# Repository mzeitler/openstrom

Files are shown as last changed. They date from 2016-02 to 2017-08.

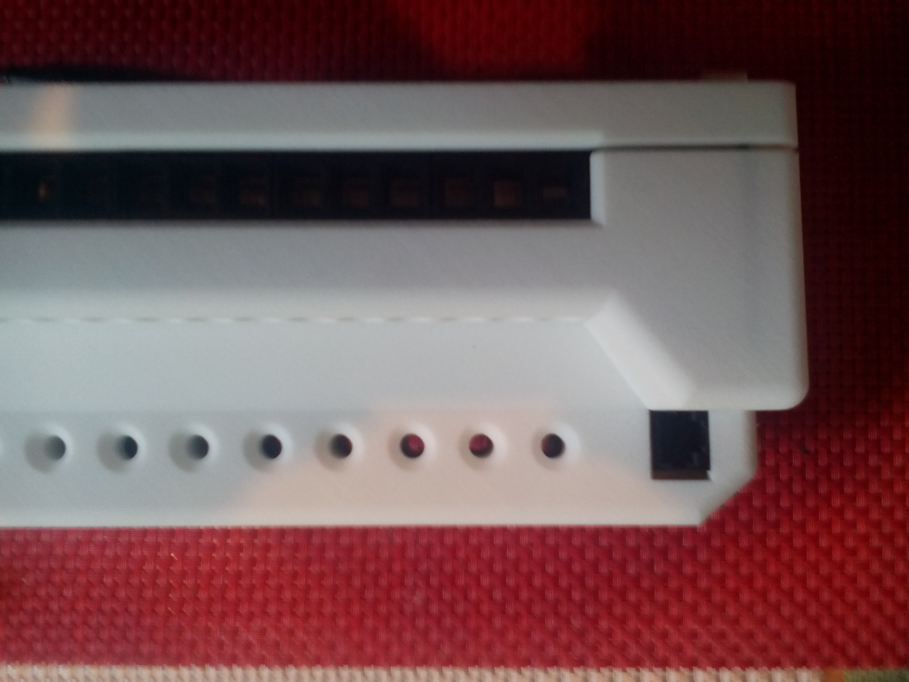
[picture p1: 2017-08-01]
housing/v0.4 - prototype 2/assembled/2017-06-19 11.30.17.jpg

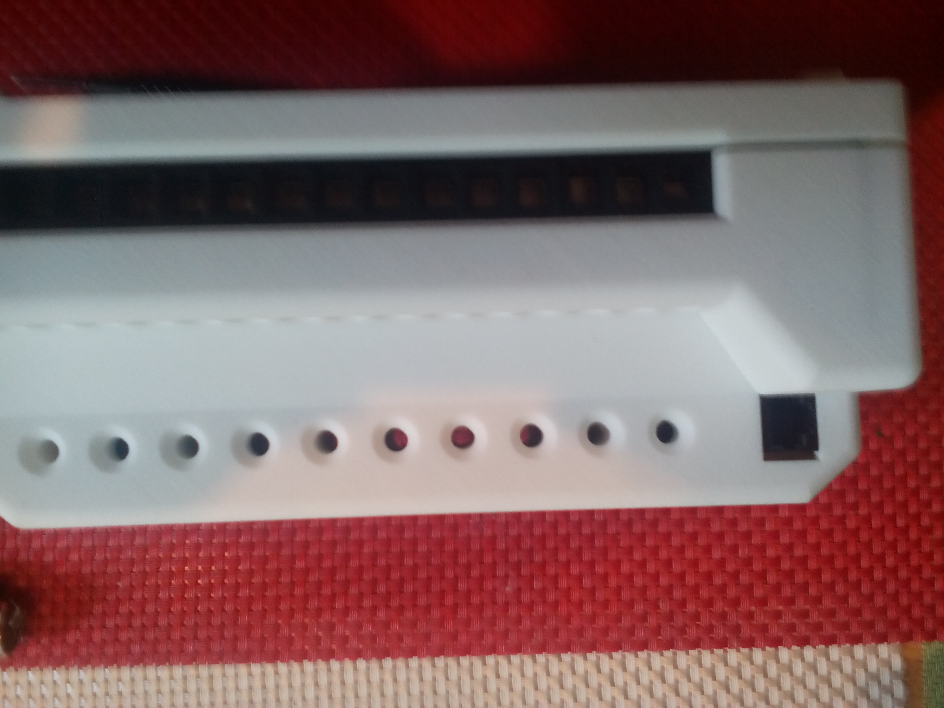
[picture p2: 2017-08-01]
housing/v0.4 - prototype 2/assembled/2017-06-19 11.30.14.jpg

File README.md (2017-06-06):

OpenStrom is an Open Hardware device that can measure and control power circuits over the internet.

It is developed by the [OpenStrom KG](http://www.openstrom.com) and generously supported by [netidee](http://www.netidee.at).

---
Copyright 2017 OpenStrom KG

Permission is hereby granted, free of charge, to any person obtaining a copy of this software and associated documentation files (the "Software"), to deal in the Software without restriction, including without limitation the rights to use, copy, modify, merge, publish, distribute, sublicense, and/or sell copies of the Software, and to permit persons to whom the Software is furnished to do so, subject to the following conditions:

The above copyright notice and this permission notice shall be included in all copies or substantial portions of the Software.

THE SOFTWARE IS PROVIDED "AS IS", WITHOUT WARRANTY OF ANY KIND, EXPRESS OR IMPLIED, INCLUDING BUT NOT LIMITED TO THE WARRANTIES OF MERCHANTABILITY, FITNESS FOR A PARTICULAR PURPOSE AND NONINFRINGEMENT. IN NO EVENT SHALL THE AUTHORS OR COPYRIGHT HOLDERS BE LIABLE FOR ANY CLAIM, DAMAGES OR OTHER LIABILITY, WHETHER IN AN ACTION OF CONTRACT, TORT OR OTHERWISE, ARISING FROM, OUT OF OR IN CONNECTION WITH THE SOFTWARE OR THE USE OR OTHER DEALINGS IN THE SOFTWARE.
---

if you are interested in helping with development or if you think you have some interesting use cases that we should consider, please get in touch with [Matthias](mailto:m.zeitler@openstrom.com "Matthias Zeitler").

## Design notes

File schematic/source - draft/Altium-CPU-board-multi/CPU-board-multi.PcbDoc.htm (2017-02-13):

Reporting Options

# File in Previous Format

Date | : | 03.01.2017
Time | : | 12:11:02
Filename | : | C:\Users\Matthias E. Zeitler\Dropbox\OpenStrom\Spec Documents\Production files for SM rev.2\CPU-Board files\AltiumFiles\CPU-board-multi.PcbDoc

Version | Warning

This file was generated by an earlier version of the software

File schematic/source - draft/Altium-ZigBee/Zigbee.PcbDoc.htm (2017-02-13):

Reporting Options

# File in Previous Format

Date | : | 03.01.2017
Time | : | 12:12:11
Filename | : | C:\Users\Matthias E. Zeitler\Dropbox\OpenStrom\Spec Documents\Production files for SM rev.2\Zigbee files\Zigbee.PcbDoc

Version | Warning

This file was generated by an earlier version of the software

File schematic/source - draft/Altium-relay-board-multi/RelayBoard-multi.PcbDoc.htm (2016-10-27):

Altium Reporting Options

# File in Newer Format

Date | : | 9/20/2016
Time | : | 3:22:10 PM
Filename | : | C:\APP\Dropbox\OpenStrom\Spec Documents\Schematics\SmartMeter-AltiumProject\Altium-relay-board-multi\RelayBoard-multi.PcbDoc

Version | Warning
Release 10 | CAUTION - New Custom Grids and Guides were introduced. Be aware that your design might contain Custom Grids and Guides that cannot be read in previous versions.
Release 10 | CAUTION - New Structured Clusters were introduced. Be aware that your design might contain Structured Clusters that cannot be read in previous versions.
Release 10 | CAUTION - New PCB 3D Movie Manager was introduced. Be aware that your design might contain 3D PCB movie that cannot be read in previous versions.
Release 10 update 1 | CAUTION - New Clearance Rule subscopes targeting differential pairs were introduced. Be aware that your design might contain Clearance Rules using those subscopes that cannot be read in previous versions.
Release 10 update 15 | CAUTION - Support of Solder Mask and Paste Mask expansions for Tracks, Arcs, Fills and Regions was introduced. Be aware that your design might contain Solder Mask and Paste Mask expansions for these types of primitives that cannot be read in the version of Altium Designer you are currently using.
Altium Designer update 19 | CAUTION - Air Gap Width attribute was introduced to Polygon Connect Style Rule. Be aware that your design might contain Polygon Connect Style Rules with new Air Gap Width attribute cannot be read in the version of Altium Designer you are currently using.
Release 13 | CAUTION - Silk To Solder Mask Clearance Rules are converted to Silkscreen Over Component Pads Rules.

This file was generated by a later version of the software

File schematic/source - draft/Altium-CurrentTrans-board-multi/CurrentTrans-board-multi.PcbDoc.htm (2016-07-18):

Reporting Options

# File in Previous Format

Date | : | 18.07.2016
Time | : | 20:55:33
Filename | : | C:\Users\Matthias E. Zeitler\Dropbox\OpenStrom\Spec Documents\Schematics\SmartMeter-AltiumProject\Altium-CurrentTrans-board-multi\CurrentTrans-board-multi.PcbDoc

Version | Warning

This file was generated by an earlier version of the software

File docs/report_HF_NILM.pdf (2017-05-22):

# High-frequency NILM and Possible Applications

## Innovationsscheck-Studie

## FHS, Günther Eibl

26.04.2017

# Contents

Introduction | 2
1 NILM Survey Papers of Zeifman and Zoha | 3
2 Google (Scholar) searches | 5
2.2.2 | Fault Detection of Airflow Handlers and Air Condi-
2.2.3 | Condition Monitoring of Wind Energy Converters . . | 9
3 What Other Companies Promise | 11
4 Books | 13

1

# Introduction

The goal of this work is the identification of possible applications of high frequency NILM (NonIntrusive Load Monitoring) with more emphasis on the application and less emphasis on the method. If possible the search results were screened for the frequency of the measurements in order to determine if the high frequency is really needed.
The report is structured by the main phases of the literature research. The search was done in four main phases with most time consumed in the first two phases.
The first, logical step builds on two already known NILM-surveys. Both of these two surveys were searched in depth for (i) other applications apart from NILM and (ii) applications based on NILM. Summarizing the results of this part of the research, the two survey papers are a good starting point for methodological research, their benefit for screening of possible applications of high-frequency measurements is however limited.
As a result, in the second phase further searching with Google (Scholar) was done which seemed to be more promising at this point of time. Despite various efforts papers found by Google searches only additionally yielded fault detection applications.
In order to find other kinds of applications, in the third phase the idea was to search on other companies web pages for applications. The special case of PCube was considered in more detail. While there numerous applications are listed, no details of the methods are given. Based on the statements there, it seems that the combined analysis of multiple sensors is necessary for many kinds of applications.
Finally, in the last phase, in order to have reliable and well-prepared information, various searches for books were performed. Books with promising names are listed in the last chapter.

2

# Chapter 1

# NILM Survey Papers of Zeifman and Zoha

The first starting point is the survey papers about NILM methods by Zeifman [1] and Zoha [2] and the contained publications. Both papers treat NILM methods for the disaggregation of the consumption curve into the consumption curves of different appliances. Both papers and practically all cited papers are very much focused on this particular application.

## 1.1 Cited Papers

The two papers only cite very few papers that do not only focus on NILM but could, according the their title, contain other applications. These papers are listed below:

- Publication [16] in [2] treats demand side management:
Cox, Robert, et al. "Transient event detection for nonintrusive load monitoring and demand side management using voltage distortion." Applied Power Electronics Conference and Exposition, 2006. APEC’06. Twenty-First Annual IEEE. IEEE, 2006.
- Publication [75] in [2] treats the influence of user behavior
Wood, G., and M. Newborough. "Influencing user behaviour with energy information display systems for intelligent homes." International journal of energy research 31.1 (2007): 56-78.
- Publication [77] in [2] considers NILM-results as input for a controlling unit
Erickson, Varick L., et al. "Energy efficient building environment

3

1.2. Description of Features | 4

control strategies using real-time occupancy measurements." Proceedings of the First ACM Workshop on Embedded Sensing Systems for Energy-Efficiency in Buildings. ACM, 2009.
- Publication [24] in [1] is different from the previous papers in that it mentions an application that is not directly related to NILM. It is a first hint that large frequencies are important for monitoring of motors Lee, Kwangduk D., et al. "Estimation of variable-speed-drive power consumption from harmonic content." IEEE Transactions on Energy Conversion 20.3 (2005): 566-574..
- Publication [41] in [1] then directly mentions the possibility to do fault-diagnosis of engines. However, it focuses on how information from different sensors should be fused.
Basir, Otman, and Xiaohong Yuan. "Engine fault diagnosis based on multi-sensor information fusion using Dempster–Shafer evidence theory." Information Fusion 8.4 (2007): 379-386.

## 1.2 Description of Features

On the methodological side, the different features that are used for analysis of high frequency signals could be of interest. These are listed below

- Harmonics or more generally the spectral envelope
- Correlation between power and different harmonics
- In contrast to the FFT, wavelets leads to information not only of the frequency but also of the time
- Geometric properties like the I-V curve
- Time-series I(t)
V(t)

, I · V(t)
- Eigenvalues of oscillation
- Transient curve when turning on or off
- Phase angle and power factor Preal
Papparent
Additionally, there are other features like occurrence frequencies of events, data from other sensors (e.g. noise). However, these features are not assumed to be interesting for this report.

High-frequency NILM and Possible Applications

# Chapter 2

# Google (Scholar) searches

Various search variants were conducted using Google and Google Scholar in order to find practical applications of high frequency measurements. Nearly all results are considering applications that are essentially based on NILM methods. The small remaining part of the scientific literature treats fault detection especially of motors. This part of the report is structured by application type. The papers found were screened especially for information about the frequency of the measurements.

## 2.1 NILM-related applications

### 2.1.1 Energy disaggregation

- The first paper of Batra is a practical NILM-toolkit for energy disaggregation. Of practical interest could be in Section 3 about data set diagnostics, statistics, preprocessing and accuracy metrics.
Batra, Nipun, et al. "NILMTK: an open source toolkit for non-intrusive load monitoring." Proceedings of the 5th international conference on Future energy systems. ACM, 2014.
- The second paper of Batra explores the differences between energy disaggregation for residential homes and commercial buildings. Batra, Nipun, et al. "A comparison of non-intrusive load monitoring methods for commercial and residential buildings." arXiv preprint arXiv:1408.6595 (2014).

5

2.1. NILM-related applications | 6

### 2.1.2 Appliance Identification

The two papers of Chang [3, 4]a treat appliance identification with transient signals. Signal durations in the graphics are in the order of several times 0.1s. The method works with wavelets and neural nets.

### 2.1.3 Occupancy Detection

Erickson [5] treats occupancy detection which is used in order to reduce the amount of air conditioning in large buildings.

### 2.1.4 NILM Applications

The paper of Armel focuses on possible applications of appliance-specific information and could be a good starting point for further research. Armel, K. Carrie, et al. "Is disaggregation the holy grail of energy efficiency? The case of electricity." Energy Policy 52 (2013): 213-234.

Given potential applications are

- Benefits to the consumer through direct feedback
– Auto-commissioning (not clearly explained)
– Fault detection
– Enabling of enhanced behavioral techniques through feedback – Analysis of when and what type of new appliance to purchase based on current use
- R&D
– Appliance Innovation: (a) redesign appliances for energy efficiency, (b) improved standards, and (c) back up appliance energy efficiency marketing
– Buildings: mproved building simulation models? Commissioning.
- Energy efficiency marketing
- Improved objectivity, sensitivity, and causal inference in program evaluation?
- Performance based metrics, ratings, and incentives of buildings
- Improved load forecasting

High-frequency NILM and Possible Applications

2.2. Fault Detection | 7

The paper also lists requirements for disaggregation algorithms and dares to estimate the number of detectable appliances depending on the frequency

- Hourly data: 3 end-use categories (i.e., loads that correlate with outdoor temperature, loads that are continuous, and loads that are timedependent such as pool pumps and outdoor lighting)
- 1min to 1s: 8 appliance types
- Multiple kHz range: identification of 20-40 appliance types
- MHz range: identification of potentially close to 100 distinct appliances

Finally, it explores the gap between existing solutions and what is needed, e.g. the accuracy of the AD-converter which influences the accuracy of the measurements.

## 2.2 Fault Detection

First, naive searches with Google with different searching terms showed surprisingly few papers that do NOT focus on the energy disaggregation application.
As a consequence, the search was performed with a possible application in mind, like fault detection. Good queries are e.g.
- fault detection induction motor

### 2.2.1 Fault detection of Induction Motors

The paper by Benbouzid [6] is a good starting point for fault detection of induction motors. Three types of faults are discussed

- Bearings damage
- Air gap eccentricity
- Broken rotor bar

According to this paper and that of Konar [7], bearings damage accounts for about 50% of failures. All these failures result in additional frequencies that occur in the motor current. Formulas for the frequencies are given. The methods that are used are also briefly discussed

High-frequency NILM and Possible Applications

2.2. Fault Detection | 8
- Classical FFT of single-phase motor current also includes a description how the analyis system looks like.
- Instant power FFT
- The bispectrum looks like an autocorrelation function with 2 varying time lags.
- High Resolution spectral analysis with determination of the eigenvalues of the autocorrelation matrix
- Wavelet analysis has the advantage over FFT that transitory characteristics can be described (e.g. drifts, abrupt changes, frequency drifts)
- Motor Current Signature algorithm

Konar [7] use a wavelet+ANN/SVM (Artificial Neural Nets / Support Vector Machines) approach. The sampling rate of the signal is given as 7680 Hz. The paper also shows a machinery fault simulator which could be interesting.
A paper where I only read the abstract is form Sualhi. The highlight of this paper seems to be its unsupervised classification technique (artificial ant clustering).
Soualhi, Abdenour, Guy Clerc, and Hubert Razik. "Detection and diagnosis of faults in induction motor using an improved artificial ant clustering technique." IEEE Transactions on Industrial Electronics 60.9 (2013): 4053-4062.

### 2.2.2 Fault Detection of Airflow Handlers and Air Condi-

tioners

This paper of Orji [8] is the first paper I found about fault detection. Although the method is based on fault detection of induction motors, it is applied to airflow handlers and therefore in its own subsection. It describes speed detection for an induction motor. The spectral envelope is used to determine when the device is turned on. The speed is calculated with the so-called principal slot harmonic frequency (Eq. (1) in the paper). This approach for estimating the speed of the motor seems to be quite common. The paper itself focuses on the determination of a frequency search window in which the maximum is taken. This approach has limited spectral accuracy for short sampling durations. An optimization method is proposed that improves the accuracy.

High-frequency NILM and Possible Applications

2.3. Methodological Papers | 9

The method is applied for the estimation of the blockage condition of an airflow handling unit due to clogging. The speed of the fan blade is a needed input for the estimation of the histogram of the volumetric airflow of the fan. The histogram needs to be created by many starts of the fan. This paper cites the survey of Benbouzid above.

There is also a PhD thesis of Christopher Reed Laughman from 2008 called "Fault detection methods for vapor-compression air conditioners using electrical measurements". While only the introduction is available, the references are also contained and could serve as a basis for further research.

In the PhD thesis of Cox [9], electromechanical actuators are triggered e.g. compressed air and vacuum systems are triggered by e.g. pressure or temperature. The time between pump runs in the graphics is in the order of minutes. So sampling rates of kHz do not seem to be needed for that. But maybe other systems have higher time intervals.

### 2.2.3 Condition Monitoring of Wind Energy Converters

The paper of Amirat [10] is very unspecific, especially the needed sampling rate is unclear.

The paper of Yang from 2010 treats condition monitoring for wind turbines. There, the sampling frequency seems to be 2kHz.
Yang, Wenxian, et al. "Cost-effective condition monitoring for wind turbines." IEEE Transactions on industrial electronics 57.1 (2010): 263-271.

## 2.3 Methodological Papers

Some papers do not treat applications but show methods that could be valuable for different applications.

Preprocessing is often of crucial importance for good performance of subsequent analysis tools. In 2010, Laughman introduces a Park Transform-Based Method for Condition Monitoring of Three-Phase Electromechanical Systems. The used sampling frequency was 8 kHz.
Laughman, Christopher, et al. "A park transform-based method for condition monitoring of three-phase electromechanical systems." Power Electronics, Machines and Drives (PEMD 2010), 5th IET International Conference on. IET, 2010.

High-frequency NILM and Possible Applications

2.3. Methodological Papers | 10

The energy monitoring sensor itself is possibly only among many sensors that are for example sensing also vibrations, sound, pressure and temperature (see also the description of PCube applications). Methods for combining evidence of different sensors are then needed. Such a method is shown in [11]

High-frequency NILM and Possible Applications

# Chapter 3

# What Other Companies Promise

You can find competitors easily by searching for “power quality monitoring” , “power monitoring” or “power monitoring solution”. I analyzed one of these companies (PQube) and screened another (Schneider Electric). These websites are good for getting ideas for possible applications. However, they of course do not contain precise informations about the arising problems and the solutions. PQube provides limited information about the sampling rate.

## 3.1 PQube

Regarding PQube, a high sampling rate is needed for electric vehicle charging monitoring: “You can even use your low-cost PQube 3 to record DC voltages and currents - 30,000 samples per second is standard – providing independent confirmation of charger performance, and cross-triggered DC disturbances.” While they sometimes mention the 30kHz, this of course does not mean that it is really necessary.
The following list contains the applications they propose (which is however often not much more than the application domain).
- Find Power Problems. Save Service Costs!
– Detect power disturbances, e.g. sags, quality of incoming power – Semiconductor tools
– MRI and medical equipment
– Data Centers - AC (and 380V DC!)
– Telecom and Base Stations

11

3.1. PQube | 12

– Use the barometric pressure sensors to detect clogged air filters. – Shipboard power, record the ship’s pitch and roll
– Large HVAC commissioning, and service, Environmental Sensors for temperature, humidity, and barometric pressure, remotely monitor
– Aircraft power and airports: monitor critical power infrastructure, like backup generators
– Pharmaceutical manufacturing
– Large power plant stability
– Distribution stability: impedances, to grid reconfiguration, to stability issues related to PV inverters, even to detect cyber attacks on substations
– Solar inverters
– Wind turbine nacelles
– Government and University Research
– Railroads and Transport: monitoring the power signature of rail switch motors, which can help predict mechanical failures and motor failures before they happen
– Electric vehicle charging: confirmation of charger performance – Military: bases and ships

High-frequency NILM and Possible Applications

# Chapter 4

# Books

There already exist books on power quality monitoring or power monitoring. Here is a short list of search results

- Electrical Power Systems Quality by Roger C. Dugan and Mark F. McGranaghan
- Modern Solutions for Protection, Control and Monitoring of Electric Power Systems by Hector J. Altuve Ferrer and Edmund O. Schweitzer
- Solar Power Generation Problems, Solutions and Monitoring by Peter Gevorkian
- Operation and Maintenance of Thermal Power Stations: Best Practices and Health Monitoring (Energy Systems in Electrical Engineering) by Pradip Chanda and Suparna Mukhopaddhyay
- Interconnected Power Systems: Wide-Area Dynamic Monitoring and Control Applications by Yong Li and Dechang Yang
- Phasor Measurement Units and Wide Area Monitoring Systems by Antonello Monti and Carlo Muscas

13

# Bibliography

[1] M. Zeifman and K. Roth, “Nonintrusive Appliance Load Monitoring: Review and Outlook,” IEEE Transactions on Consumer Electronics, vol. 57, pp. 76–84, 2011.
[2] A. Zoha, A. Gluhak, M. A. Imran, and S. Rajasegarar, “Non-intrusive Load Monitoring approaches for disaggregated energy sensing: A survey,” Sensors (Switzerland), vol. 12, no. 12, pp. 16 838–16 866, 2012.
[3] H. H. Chang, “Non-intrusive demand monitoring and load identification for energy management systems based on transient feature analyses,” Energies, vol. 5, no. 11, pp. 4569–4589, 2012.
[4] H.-H. Chang, K.-l. Lian, Y.-C. Su, and W.-j. Lee, “Energy Spectrum-Based Wavelet Transform for Non-Intrusive Demand Monitoring and Load Identification Hsueh-Hsien Chang,” in Industry Applications Society Annual Meeting. IEEE, 2013, pp. 1–9.
[5] V. L. Erickson, Y. Lin, A. Kamthe, R. Brahme, A. Surana, A. E. Cerpa,
M. D. Sohn, and S. Narayanan, “Energy efficient building environment control strategies using real-time occupancy measurements,” in Proceedings of the First ACM Workshop on Embedded Sensing Systems for Energy-Efficiency in Buildings - BuildSys ’09, 2009, p. 19. [Online]. Available: http://portal.acm.org/citation.cfm?doid=1810279.1810284
[6] M. E. H. Benbouzid, “A Review of Induction Motors Signature Analysis as a Medium for Faults Detection,” IEEE Transactions on Industrial Electronics, vol. 47, no. 5, pp. 984–993, 2000.
[7] P. Konar and P. Chattopadhyay, “Bearing fault detection of induction motor using wavelet and Support Vector Machines (SVMs),” Applied Soft Computing, vol. 11, no. 6, pp. 4203–4211, 2011.

14

Bibliography | 15

[Online]. Available: http://www.sciencedirect.com/science/article/pii/S1568494611001104 (http://www.sciencedirect.com/science/article/pii/S1568494611001104)

[8] U. A. Orji, Z. Remscrim, C. Laughman, S. B. Leeb, W. Wichakool,
C. Schantz, R. Cox, J. Paris, J. L. Kirtley, and L. K. Norford, “Fault detection and diagnostics for non-intrusive monitoring using motor harmonics,” Conference Proceedings - IEEE Applied Power Electronics Conference and Exposition - APEC, pp. 1547–1554, 2010.
[9] R. W. Cox, “Minimally Intrusive Strategies for Fault Detection and Energy Monitoring,” Ph.D. dissertation, Massachusetts institute of technology, 2006.
[10] Y. Amirat, M. E. H. Benbouzid, E. Al-Ahmar, B. Bensaker, and S. Turri, “A brief status on condition monitoring and fault diagnosis in wind energy conversion systems,” Renewable and sustainable energy reviews, vol. 13, no. 9, pp. 2629–2636, 2009.
[11] O. Basir and X. Yuan, “Engine fault diagnosis based on multi-sensor information fusion using Dempster-Shafer evidence theory,” Information Fusion, vol. 8, no. 4, pp. 379–386, 2007.

High-frequency NILM and Possible Applications

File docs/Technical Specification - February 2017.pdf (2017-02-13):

# OpenStrom

# Technical Specification

v0.8

## 12. February 2017

The OpenStom Technical Specification by OpenStrom KG (http://www.openstrom.com/) is licensed under a Creative Commons Attribution-ShareAlike 4.0 International License. (http://creativecommons.org/licenses/by-sa/4.0/)
Based on a work at https://github.com/mzeitler/openstrom.

THIS IS A DRAFT AND DOES NOT REFLECT THE FINAL SPECIFICATION Please direct all comment to m.zeitler@openstrom.com

Technical Specification

### Content

## Overview

OpenStrom is a hardware device that can measure and control up to 10 power circuits over the internet. It is intended to monitor and control the energy parameters from the wide spectrum of home and industrial appliance.

The device should meet to specified technical requirements and to cover certain functional features.

The main features are:

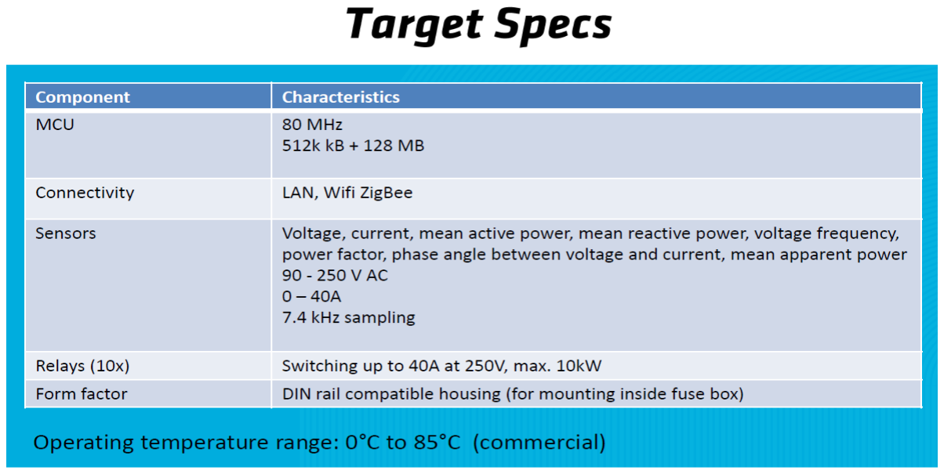
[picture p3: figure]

## Functional features

Scan, measure and record the energy parameters from 10 energy circuits that supply different types of appliances such as refrigerators, heaters, pool pumps, washers, dryers, toasters, computers and etc.

### Energy parameter measurements

Active power P [W] The device measures active power up to 10 KW | P = Irms * Vrms * cos(θ); Iac is a AC current in circuit; Vac is voltage in circuit; cos(θ) is a phase angle between current Iac and Vac
Reactive power Q [VAR] The device measures reactive power up to 10 KVAR | Q = V * I * sinθ which can be positive (+ve) for inductive, negative (-Ve) for capacitive load; Q refers to the maximum value of the instantaneous power absorbed the reactive component of the load
Apparent power S [VA] The device measures apparent power up to 10 KVA | S=Vrms*Irms;
Power factor PF The Power Factor is in the range 0-1 | In AC circuits, the power factor is the ratio of the real power that is used to do work and the apparent power that is supplied to the circuit.
Current and voltage [V] and [A] | The device detect and monitor the undervoltage (sag) and overvoltage (swell);

Frequency of the line Frq

### Functional requirements

- Switch 10 circuits on/off remotely via LAN or Wi-Fi up to 40A 250
- Measure data with high sampling frequency (7.8 kHz) to allow energy disaggregation algorithms for detecting of specific appliances or error states

### Communication Options

- Ethernet network with 10/100 Mbit/s transfer speed
- Wi-Fi standard 802.11. b/g/n
- ZigBee standard 802.14.4

In order to meet the functional requirements, the device will include the following circuits:

- Sensor circuits
- CPU
- Relays control circuits
- Network communications
- External RAM

## Technical specifications

### Sensor circuits

To meet the functional features of OpenStrom the sensor system measures the current and the voltage of every electrical grid connected to the device.

The sensor circuits comprise a current and voltage sensors.

Current sensor technical specification

- The current sensor input range is - 0~40 amps AC
- The sampling frequency is 1 KHz – 7.8 KHz with tolerance +-10 %
- Output convert the analog values of current in digital sequence in 24 bits binary format
- The sensor has linear response, because small error in transformation may result in incorrect output
- Resolution of the sensor is 24-bits to be able to transform the current changes with a high accuracy
- Size of the sensor is small, because of board size limitation

Voltage sensor specification

- Voltage sensor senses AC voltage
- Input range is 0~400 VAC
- Sampling frequency is 1KHz – 7.8KHz with tolerance +-10%
- Resolution of the voltage sensor is minimum 16-bits to be able to transform the voltage changes
- Voltage spikes should have no effect on sensor components

Frequency sensor specification

Range of frequency sensor must be 45 – 70Hz. Other than, this range cannot practically achieve, because at frequency outside this range the appliance device may get damage.

Specifications for frequency design
- Input range 40 – 70Hz;
- Output of the sensor will find zero crossing of input AC (important to switch relays)

Sensor circuits selection

The investigation and research of the possible sensor component implementation reached to the following solution:

STPM energy IC 34:

- Active power accuracy
- < 0.1% error over 5000 :1 dynamic range
- < 0.5% error over 10000:1 dynamic range
- Reactive power accuracy
- error over 2000:1 dynamic range
- Dual mode apparent energy calculation
- Instantaneous and averaged power
- RMS and instantaneous voltage and current
- Under voltage and over voltage detection (sag and swell)
- The limits of sag and swell set up programmable
- Sampling frequency 7.8 kHz tolerance +-0.5%
- UART and SPI high-speed serial interface;
- SPI timing specifications:
- MCLK of SPI communication – 20MHz;
- T_clk – Clock period | - 50ns;
- T-cpw – Clock pulse width | - 25ns;
- T_hold – Hold time | - 40ns;
- 2 independent current and voltage channels;
- Analog input voltage specifications:
- Current inputs voltages max +-300mV; min =-37.5mV;
- Current channel input gain – 2, 4, 8,16;
- Voltage inputs voltage +- 300mV;
- Voltage channel input gain – 2;
- Oversampling frequency – 4MHz+-1%;
- Vcc supply range 3.3v +- 10%;
- Supply current Icc 4mA+-400uA;
- Input clock frequency 16MHz+-1%;

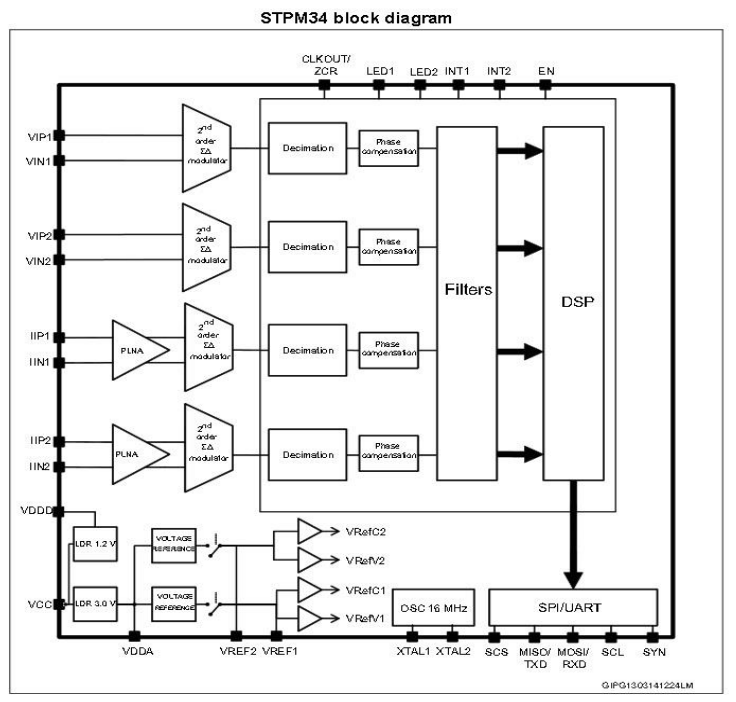
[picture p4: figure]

Current transformers

For the current measurements are used current transformers (CT).

The specifications for CT are:
- Sensed current I in – 40Amps;
- Turns(N) pri:sec – 1:2500 ;
- Frequency range(kHz) – 7-1000kHz;
- SMD size;

One of the more appropriate CT covering these requirements is ZMCT116A

### Technical specifications for the CPU / Microcontroller MCU

The CPU provides the following functions:
- Acquire data from sensor's circuits
- Process data
- Send and receive data and commands from backend server through the network
- Wi-Fi, Ethernet, Zig-Bee communication interfaces
- Control the states of relay’s circuits

Following the functional requirements, CPU acquires input data from current and voltage sensors of 10 grid circuits with sampling frequency between 1Hz – 7.8Mhz.

After scanning of Inputs data, the CPU exchanges the data with the backend server. At the same time the CPU control if some failures are raised (critical values of currents, voltages and mains frequency).

The high sampling frequency and the high number of the monitored and logged sensors requires from CPU to operate with very high performance and to have a large memory – RAM and flash.

A good choice would be if the CPU owns implemented network controller such a Wi-Fi, Ethernet or Zig-Bee. To be able to communicate effective with all these circuits, CPU has a high speed serial interface - SPI and UART.

We look for a CPU with a high performance, high speed serial interfaces, implemented TCP/IP stack and certain network controller.

CPU selection

We found that the PIC32MX795F512H system offers the best choice for us

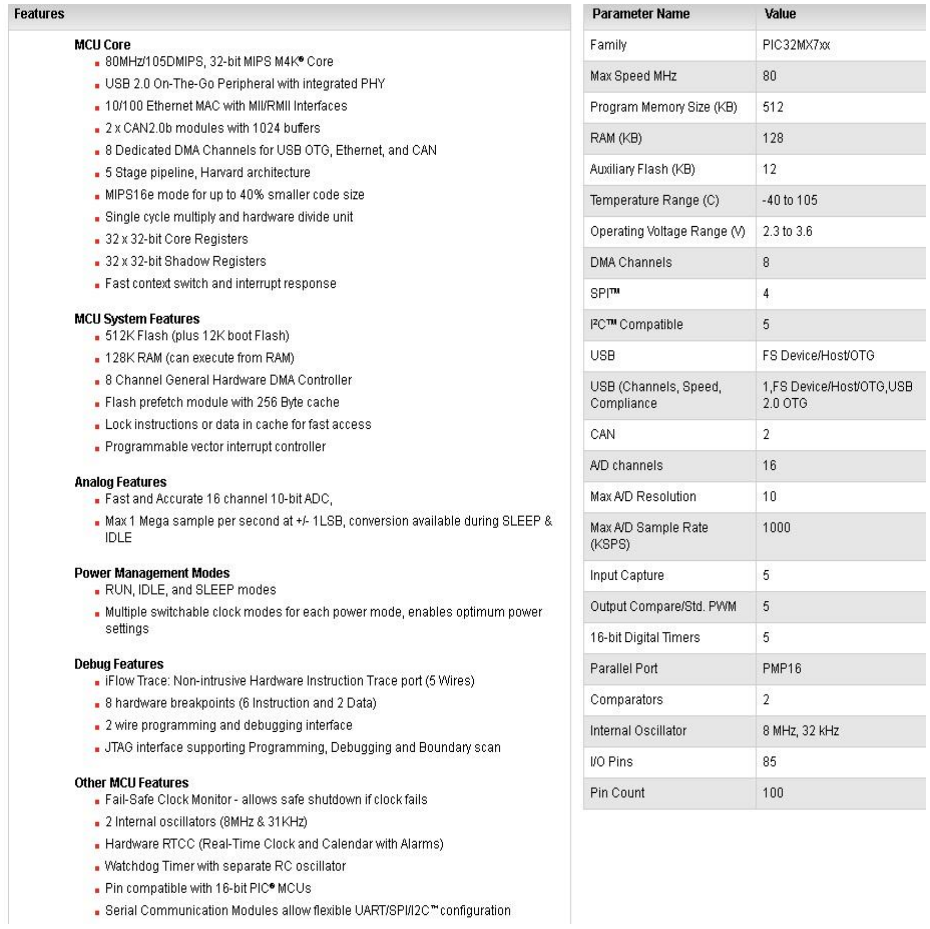
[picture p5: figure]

### Network specifications

Connectivity

To meet the functional requirements the device transmit and receive data frames (data and commands) from/to cloud server. Therefore the communication between the device and server should be realized as communication between “client” (smart meter) and active backend “server”.

LAN transfer speed

The required LAN bandwidth depends on the amount of data collected.

Data Collected | Bandwidth
1 circuit at 1 kHz | 120K bytes
1 circuit at 5 kHz | 600K bytes
1 circuit at 7.8 kHz | 936K bytes

Network protocol

The smart meter communicates in a network using TCP/IP protocol.
The device uses DHCP protocol to get default gateway, subnet mask and IP address by default. However it is also possible to assign these values manually on the device.

Ethernet controller

The Ethernet controller as MAC structure is included in the main microcontroller. The IC 8720 realizes PHY layer as an external module.
As a output bus is used RMII (Reduce Media Independed Interface) because have better ration performance/cost.

Wi-Fi module

The device has a Wi-Fi transceiver module to communicate with an access point (router).

Wi-Fi specifications

The Wi-Fi module has the following specifications:

- Wi-Fi standard IEEE 802.11 b/g/n;
- Wireless transmission rate – 100Mbps, 54Mbps, 10 Mbps;
- Frequency range – 2.4 GHz;
- Functional mode – Client/AP/Router;
- Wireless security – WPA/WPA2;

- Covered distance – 100m;

As Wi-Fi controller the ESP 8266 WROOM, commercial number ESP-EROOM-02 has been selected. This Wi-Fi module meets entirely the technical specifications. Moreover, this module has very good ratio performance/cost.

Technical specification of ESP 8266 WROOM module:

Espressif Systems’ Smart Connectivity Platform (ESCP) is a set of high performance, high integration wireless SOCs, designed for space and power constrained mobile platform designers. It provides unsurpassed ability to embed WiFi capabilities within other systems, or to function as a standalone application, with the lowest cost, and minimal space requirement.

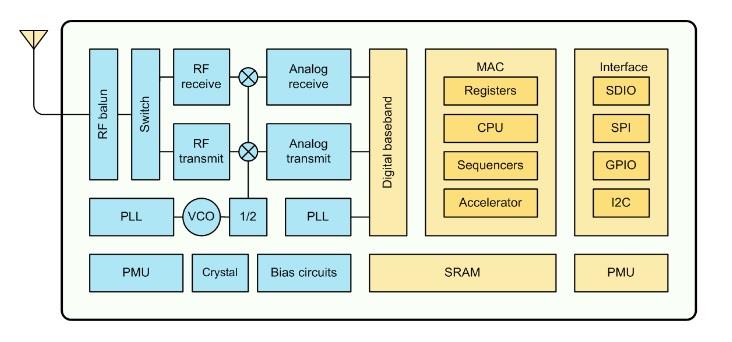
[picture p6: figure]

ESP 8266 WROOM offers a complete and self-contained WiFi networking solution; it can be used to host the application or to offload WiFi networking functions from another application processor. When ESP 8266 WROOM hosts the application, it boots up directly from an external flash. In has integrated cache to improve the performance of the system in such applications.
Alternately, serving as a WiFi adapter, wireless internet access can be added to any micro controller-based design with simple connectivity (SPI/SDIO or I2C/UART interface).
ESP 8266 WROOM is among the most integrated WiFi chip in the industry; it integrates the antenna switches, RF balun, power amplifier, low noise receive amplifier, filters, power management modules, it requires minimal external circuitry, and the entire solution, including front-end module, is designed to occupy minimal PCB area.
ESP 8266 WROOM also integrates an enhanced version of Tensilica’s L106 Diamond series 32-bit processor, with on-chip SRAM, besides the WiFi functionalities. ESP 8266 WROOM is often integrated with external sensors and other application specific devices through its GPIOs; sample codes for such applicationsare provided in the software development kit (SDK)

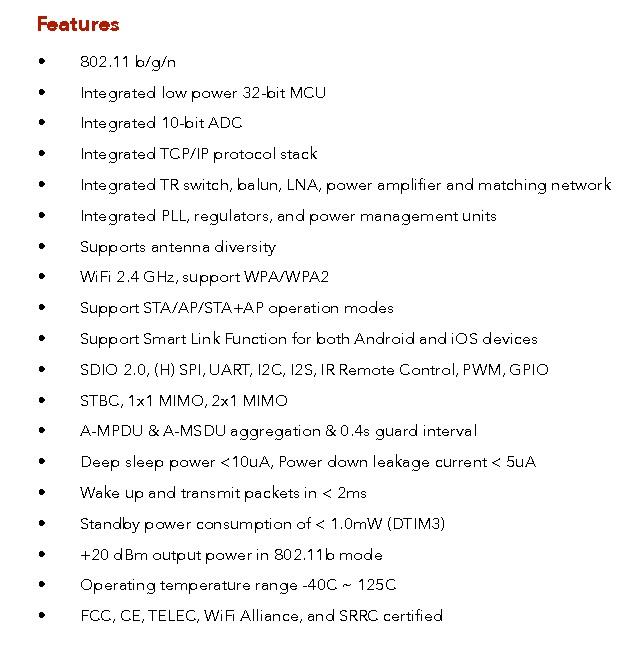
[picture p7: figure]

Zig-Bee Module Specification

- IEEE Std. 802.15.4™ Compliant RF Transceiver;
- Supports ZigBee, MiWi™, MiWi™ P2P and Proprietary Wireless Networking Protocols;
- Distance Up to 122meter(400 ft);
- Data Rate: 250 kbps;

- 94 dBm Typical Sensitivity with +5 dBm Maximum Input Level;
- ISM Band 2.405-2.48 GHz Operation;
- +0 dBm Typical Output Power with 36 dB TX Power Control Range;
- Integrated Low Phase Noise VCO, Frequency Synthesizer and PLL Loop Filter;
- Digital VCO and Filter Calibration;
- Integrated RSSI ADC and I/Q DACs;
- Integrated LDO;
- High Receiver and RSSI Dynamic Range;
- Hardware CSMA-CA Mechanism, Automatic ACK
- Response and FCS Check;
- Independent Beacon, Transmit and GTS FIFO;
- Supports all CCA modes and RSS/LQI;
- Automatic Packet Retransmit Capable;
- Hardware Security Engine (AES-128) with CTR, CCM and CBC-MAC modes;
- Supports Encryption and Decryption for MAC Sublayer and Upper Layer;
- Hardware CSMA-CA Mechanism, Automatic ACK;
- Response and FCS Check Independent Beacon, Transmit and GTS FIFO;
- Supports all CCA modes and RSS/LQI Automatic Packet Retransmit Capable;

- Hardware Security Engine (AES-128) with CTR, CCM and CBC-MAC modes;
- Supports Encryption and Decryption for MAC Sublayer and Upper Layer.

The Zig-Bee module that meets these specifications is MRF24J40MA from Microchip.

### Relay circuits

The device has 10 relays that control the state of the circuits. GPIO will turn on and off the relays. Each relay switches the grid circuit with the max load of 40 amps. The relays are mounted on the separated board. They are reconfigurable. The user can configure if NO or NC leads to be connected to the controlled circuit.
They can provide about 100,000 clicks before which it will get degraded.

Specification for the switching relays

- Power requirements of the coil - 5v/40mA
- Can support load up to 40 A
- 10 years expected lifetime
- Contact system – SPDT with external possibility to exchange the NO with NC contacts
- Reconfigurable leads

The relays that can meet these specifications are:
JQX-16F manufacturer YUEQING HENGWEI ELECTRONICS CO.,LTD

### Additional components

The device includes the following active and passive components:
- Power supply IC
- NPN transistors
- Diodes
- Capacitors
- Resistors
- Quartz resonators
- Terminal blocks
- Network connector RJ-45
- 128 MB SRAM
- Battery
- Power switch

Power Supply
A 5v and a 3.3v supply will be used to provide necessary voltages for all circuits and components of device. The power supplies are step-down switching regulators located on the main board.

Power Supply 3.3 v
Rating is 3.3v+- 0.3v @ 500 mA;
Expected life time of 10 years

Power Supply 5 v
Rating is 5v +- 0.4v @ 2 Amps Expected life time of 10 years

PCB

The device comprises three PCBs.
- SM-CPU Board PCB;
- SM-Relay Board PCB;
- SM-Current Trans Board PCB;

The SM-CPU Board PCB will be designed as a high density 6 layers PCB according to EMI and RoHS requirements and will cover the following specifications:
- Core Material should be - FR
- Copper layers – weight (oz)- 1; thickness(mm) - 1.2;
- Thermal pads and vias for high density IC packages;
- The high frequency signals are routed without loops and max shorted;
- The digital and analog grounds are separated;
- The zones of PCB where high EMI radiation is expected should be hatched with appropriate segments;

- Dimensions - 99.4mm x 66mm;

The SM-Relay Board PCB will be designed as a 4 layers PCB according to termal and high current requirements and will cover the following specifications:
- Core Material should be - FR
- Copper layers – weight (oz)- 4;
- The track’s width for high current lines should be up to 6mm on the Top and Bottom layers.
- Dimensions – 100mm x 170mm;

The SM-Current Transf Board PCB will be designed as a 2 layers PCB and will cover the following specifications:
- Core Material should be - FR
- Copper layers – weight (oz)- 1;
- Dimensions – 170.2mm x 43mm;

### BOM

# | Description | Manufacturer | Part Number | Package | Amount | Cost $ (@1000) | Total

1 | PIC32MX512 microcontroler | Microchip | PIC32MX795F512H | 64QFN | 1 | $6,68 | $6,68
2 | Energy IC STPM34 | ST Microelectronics | SSTPM34TR | 32 QFN | 5 | $1,13 | $5,65
3 | WiFi IC module ESP8266 | Shenzhen Guangshun Electronic Business | ESP 8266-Wroom-2 | | 1 | $2,34 | $2,34
4 | PHY IC LAN 8720 | Microchip | LAN 8720 | 24 QNF | 1 | $0,95 | $0,95
5 | ZigBee IC moduleMRF24J40MA | Microchip | MRF24J40MA | 32 QN2 | 1 | $3,39 | $3,39
6 | Serial RAM 128 MB | Winbond Electronics | W25Q16DVZPIG | 8-WSON | 1 | $1,82 | $1,82
8 | Terminal Blocks | Shenzhen Sced Electronics Co Ltd | GD135-3 | | 10 | $0,25 | $2,50
9 | Ethernet Transformer | Pulse Electronic Corporation | HX1224-CNL | | 1 | $1,27 | $1,27
10 | Power Supply IC MP2403 | MPS Inc | MP2403DN-LF-Z | 8-SOIC | 1 | $2,6 | $2,6
11 | Power Supply IC MP1470 | MPS Inc | MP1470GJ-P | 8-SOIC | 1 | $1,12. | @1,12
12 | Crystal oscillator 40Mhz | China manfufacturer | HC-49S | | 2 | $0,25 | $0,50
13 | JQX-16F relay 250VAC/40A | Yueqing HengweiElectronics Co.,Ltd | JQX-16F(T91) | | 1 | $0,32 | $0,32
15 | RJ-45 8px8c modulare jack | China manufacturer | P88RE50V2GN | | 1 | $0,25 | $0,25
16 | Optocouplers 4N25 | Vishay China analog | 4N25 | DIL-6 | 10 | $0,02 | $0,20
17 | Transistors NPN | Fairchild | MMBT2222 | | 10 | $0,02 | $0,20
18 | PCB1 | SM-CPU | | 6Layers | 1

19 | PCB2 | SM-RelayBoard | | 4 layers | 1
20 | PCB3 | SM-CurrentTrans | | 2 layers | 1
21 | Custom Housing | TBD | | | 1 | $5,00 | $5,00
22 | LED | longhua | quarter watt led blue color
23 | Current transformer | NanJing ZeMing Electronics Co.Ltd | ZMCT116A | | 10 | $0,4 | $4,00

The most up to date BOM is available online: https://docs.google.com/spreadsheets/d/1HDGjBxVw-1nGk1cR228rhcC5lW-j-Xv8pPq2h0ZrsOU/edit?usp=sharing (https://docs.google.com/spreadsheets/d/1HDGjBxVw-1nGk1cR228rhcC5lW-j-Xv8pPq2h0ZrsOU/edit?usp=sharing)

### Software specification

This section determines the specifications to the software allowing the device to realize its functional features.

The software includes:
- Firmware structure
- User application firmware
- Provisioning (initial setup)
- Server application software backend

Firmware specifications

The device firmware is created with MPLAB Harmony, a development framework containing a wide set of firmware libraries (API), device drivers, middleware and application software.

To cover the basic software feature the firmware is separated in appropriate software modules, realized with the resources of Harmony:

Scan and Measure Sensors – SPI Library Module

This library provides an interface to manage the SPI of PIC32MX microcontroller and includes the following functions:

- System Interaction Functions – provides system module interface, device initialization, reinitialization, task and status functions
- Client Setup Functions – provides open, close, status and setup functions;
- Data Transfer Functions – provides send and receive data messages;
- Relay Control - Port Peripheral Library(PLIB)
Firmware Feature | Harmony Resources
Scan and measure sensors Relay control | SPI Library Module Port Peripheral Library(PLIB)
WiFi transfer | UART Library Module
Ethernet Transfer | TCP/IP Stack Module
Service functions and archive in EEPROM | SPI Library Module

This library provides an API to the GPIO of PIC32MX and includes the following functions:
- Port functions – performs port access read/write/toggle/clean interface to the available ports in MPU;

Wi-Fi Transfer – UART Library Module
The Wi-Fi transfer between MCU and ESP 8266 wi-fi module is realized by UART Library(API)

This library includes the following functions:
- Baud rate generator Function – provides setup and configuration interface routine;
- Transmit Function – provides setup, data transfer, error and status interface routines for the transmitter
- Receive Function – provides setup, data transfer, error and status interface routines for the receiver;

Ethernet Transfer – TCP/IP Stack Device Driver Library

This driver includes the following API functions:
- Client Level Functions - DRV_ETHMAC_PIC32Open, DRV_ETHMAC_PIC32Close, DRV_ETHMAC_PIC32MACSetup to support the TCP/IP Stack
- Receive Functions
- Transmit Functions
- Event Functions

Host Driver

The host driver performs the communication services between Wi-Fi module and AP (access point). The host driver sends request to the AP and receives the responses from the server. This driver is located in ESP8266 and can be configured and update with the appropriate software tool.

Technical specifications of Host driver
- support Wi-Fi subsystem services (callback functions );
- support asynchronous even handling;
- support hardware function of the its own 32-bit microcontroller;
- support the following peripheral interfaces:
- SPI with SCLK up to 20 Mbps;
- Standard UART with up to 3 Mbps;

User Application Firmware

The application firmware contains the following modules
- Init Routine – this routine utilizes API library function to initialize device hardware
- Input Scan Routine - this routine performs scanning and measuring inputs of energy metering IC and store there values in microcontroller SRAM
- Time Sampling Routine – this routine use timer’s resources of microcontroller to generate time sampling sequences

- JSON Convertor Routine– this routine converts measured data into JSON string format;
- Switch Relay Routine - this routine provide relay’s switching process
- Main program – this program should be as a state machine program to run the all firmware tasks in the device

Provisioning (Initial Setup)

The smart meter can communicate in wireless network as a standalone device (station), or as a AP (Access point) device. The selection of the ESP8266 Wi-Fi module gives two options of Wi-Fi configurations (Initial Setup):

1. Smart meter as a station. In this configuration it communicates with separated AP device (router). In this case, the SSDI and password set up by AT Command programming interface using a software tool.
2. Smart meter as AP device. In this case configuration is realized by AP control firmware. This firmware allows the user to connect to the smart meter and set SSDI and password of the network the smart meter will be connected to.

The AP firmware has the following specifications:
- set the smart meter to AP mode
- set a name and password
- present a server asking for SSDI and password
- connect to the network

Server Software

The data from the sensors will be converted into interchange formats such as JSON and XML/Webservices and send to a backend server.

The JSON format meets the requirements of the standard ECMA 404.
Since the transformation of binary data into JSON format data, increase JSON files with 33%, the software of SM should have compression algorithm such a gziped+hpack and an additional temporary SRAM to store JSON data blocks before to be transferred to the backend server.
Take into account that 10 KHz sampling creates data blocks of 2 MB per second and requires optimization.
As a high level of compression algorithm is used so called “Resumable Load data compression” algorithm applied in smart grid investigation in Massachusetts Institute of technology(MIT). This algorithm is based on the consume power profiles of values of home appliances energy parameters. The compression is coming from the fact that the two neighbor values can be presented with their difference that in 90% of cases is very small.

A SRAM buffer and battery will keep unsent data in case of connectivity or power loss and resend data to backend server after connectivity/power is restored.

Firmware functionality
For the prototype the initial version of the firmware should covers these basic features for demonstration and testing:
- Data logging of all sensor data in a XML package
- Sending the XML package to a web service backend (backend will be simulated with hyper terminal)
- Connecting to default wifi hotspot
- Connecting to LAN (DHCP)
- Controlling relays (=data package response turns on/off specific relay)
- Controlling one Zigbee device (turn on and off)

The initial firmware will only be used to show the circuit works in general. A more advanced firmware will be specified and implemented later

### Housing

The housing should fit into a standard fuse box and be DIN rail mountable.

- The enclosure provides a degree of protection to personnel against access to hazardous parts and to provide a degree of protection of the equipment inside the enclosure against ingress of solid foreign objects;
- The enclosure covers the requirements of the IEC 60950-1 standard.
- The device has protection against RF&EMF radiations.
- The device enclosure has thermal shield which has sink up to 12-15W.

It should provide location of one PCB board with following sizes:
- Length - 240+35mm;
- Width - 175+35mm;
- Height - 40+10mm;

### Self-testing and diagnostic possibilities

The device will execute test procedure verifying its main blocks of the device.
This procedure starts by the command from the server and generates feedback messages that determine the faults. The faults messages will be organized as a dictionary of faults.

The other diagnostic specifications are
- Watchdog timer;
- Calibration procedure for inputs sensors group;
- Check procedure for Wi-Fi transfer;
- Check procedure for relays;
- Test points (TP) at the every one functional circuit.

### Safety & Compliance Marking

The device will be marked with the applicable safety and compliance marks required for commercial distribution in US and EU markets.

Specifically:

- For EU market of electric and electronic appliances - CE, RoHS;
- For Nord America market – UL, FCC

In addition each device will be marked as follows:

OpenStrom a product of OpenStrom KG
Part Number P/N: xxxxxxxxxx
Serial Number: xxxxxxxxxxxxxxx Wifi MAC: xxxxxxxxxxxxxxx
LAN MAC: xxxxxxxxxxxxxxx
Barcode
Standard Marks

### Safety Requirements and Specifications

The OpenStorm meets the requirements of the following electronic standards

- FCC – Federal Communication Commission - USA;
- CE – Conformite Europence – Europe;
- UE – Underwrites Laboratory - USA / Canada;
- OSHA Electrical Safety – Europe;
- EMC Directive – Europe;
- R&TTE – Europe;
- RoHS – Europe;

The following are the product safety compliance regulations are implemented:

- UL60950-1/CSA 60950-1 (USA / Canada)
- EN60950-1 (Europe)
- IEC60950-1 (International)

Specifications of Safety

OpenStorm design will handle normal operating conditions and also faulty conditions, consequential faults, and external influences such as temperature, altitude, pollution and moisture.

- The safety design for OpenStrom includes:
- Enclosure design for protection of electrical shock and energy related hazards;
- Enclose will have a high value of dielectric insulation
- Enclosure’s material will be high resistive to fire , climate factors and electromagnetic radiations;
- The component selection, circuit design and enclosure will be done to protect the device from currents overload, insulate breakdown and by this way will protect the device from the temperature shock and fire
- Protection against mechanical hazard will be reach in enclosure design where the sharp edges and corners will be rounded

RF Certification Compliance

The design of OpeenStorm includes two types of RF wireless communications:

- WiFi;
- ZigBee;

To be compliant with RF certification requirements OpenStorm is designed with the following modules:

- WiFi ESP 8266-Wroom-2 module which is pre-certified with the standard ETSI – Europe
- ZigBee MRF24J40MA module is pre-certified with:
- FCC(USA);
- IC(Canada);
- ETSI(Europe);

## Schematic

The complete schematic is available at: https://www.dropbox.com/sh/ot0jd58d2qf6njz/AAB8RIcgBR5rNrH3Oqq_DbuMa?dl=0

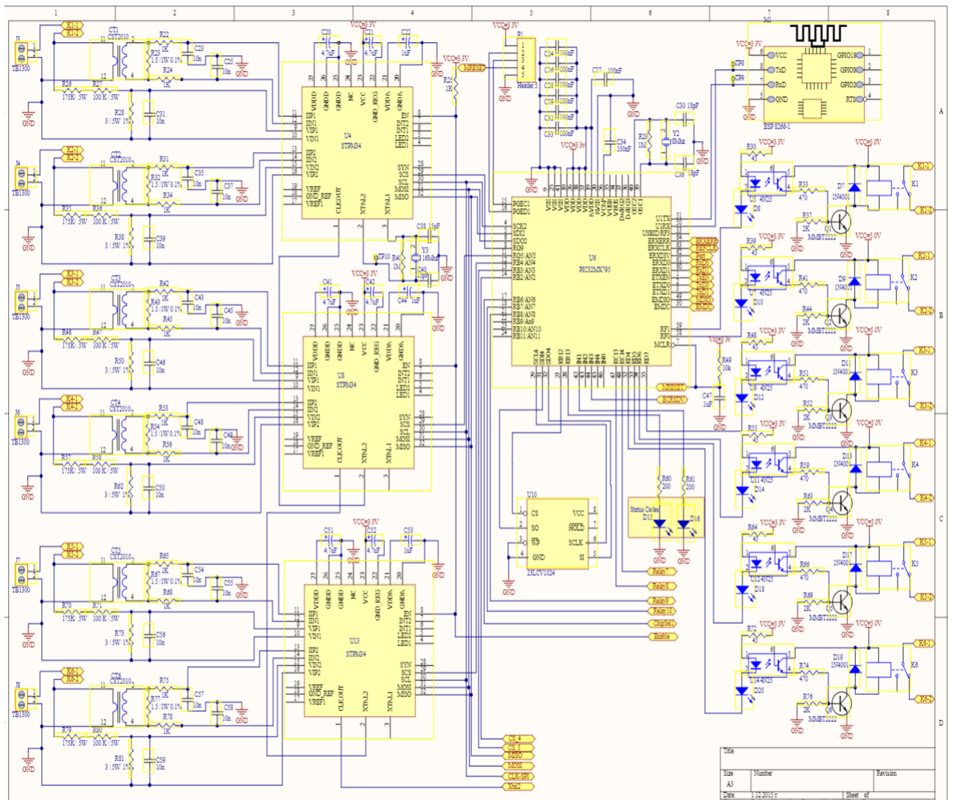
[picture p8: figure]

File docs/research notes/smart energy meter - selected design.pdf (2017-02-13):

# SMART ENERGY METER

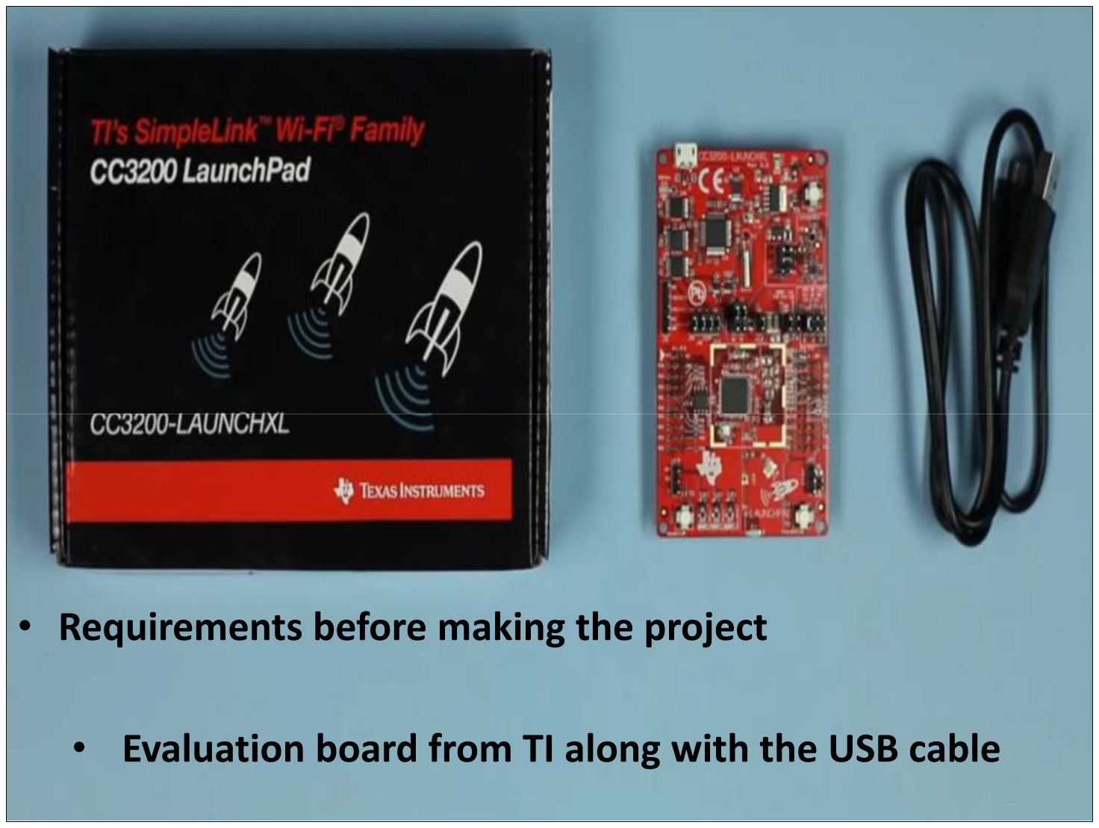
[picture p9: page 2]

- Requirements before making the project
- Evaluation board from TI along with the USB cable

## Software requirements

- Latest CCS or Energia.
- I Prefer Code composer studio Version 6.0.1
- Software : cc3200sdk_1.0.0 _ downloadable.
- >> Testing Datafor the terminal :

– Recommended Teraterm,
– Hyperterminal, termite can be tried.

- TI – RTOS for simplelink as addon in CCS
- SimpleLink Wifi as addons in CCS

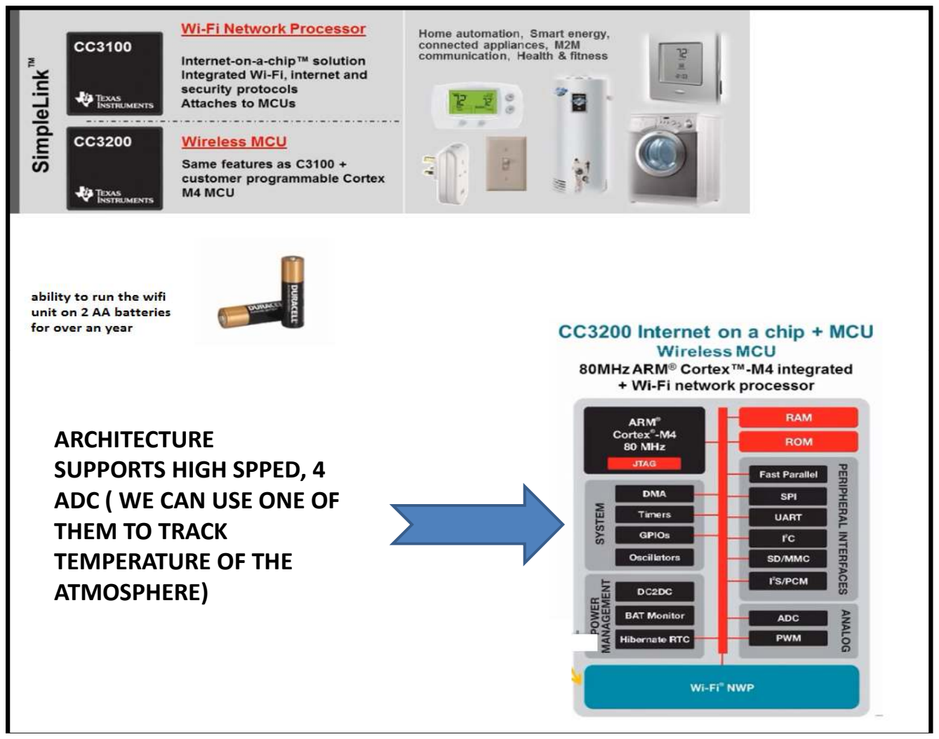
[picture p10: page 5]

ARCHITECTURE
SUPPORTS HIGH SPPED, 4
ADC ( WE CAN USE ONE OF
THEM TO TRACK
TEMPERATURE OF THE
ATMOSPHERE)

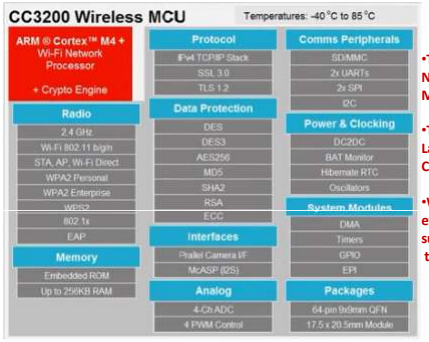
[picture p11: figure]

•The modules shows
No sign of Ethernet
Module.

•To be controlled through
Lan we need a Ethernet
Controller.

•We will have to fix an

suffice our requirement
to access through LAN

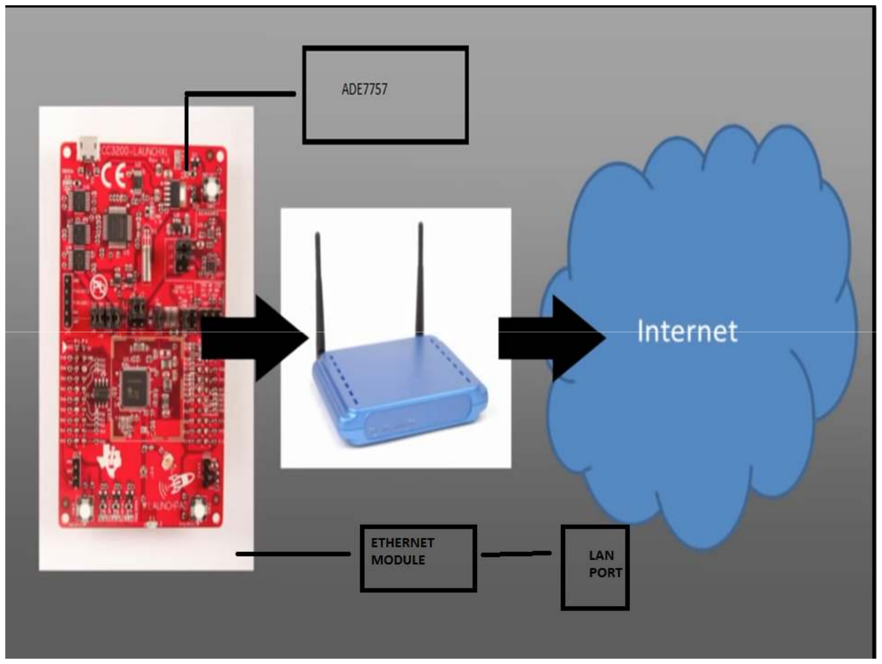
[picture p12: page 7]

I have to still work on accessing Details to the cloud .

I have no much experience on accessing The cloud details.

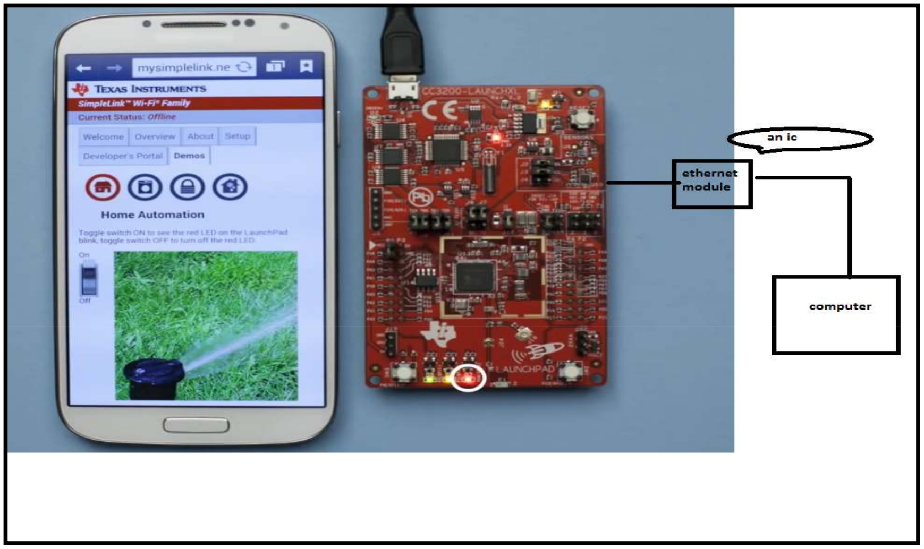
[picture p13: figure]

## SECURITY

- WPA2 PERSONAL AND ENTERPRISE
- SSL 3.0/ TLS 1.2
- On chip hw encryption – Real time encryption – Fast TLS connection in 200 msec

## Module required

- Cc3200r1m2rgc ( 256kb, ram) - 1000 nos @ $4.61

## Codes and different API’s

- Init function to setup the access point.
- Drive the relays through the uln2003 driver or appropriate drivers.
- Drive relays to check parameters in the LCD module on the board. ( keeping an lcd module would help us to trouble shoot it in the later stage, lets apis be written for this , not necessary to have it mounted on the finished project)

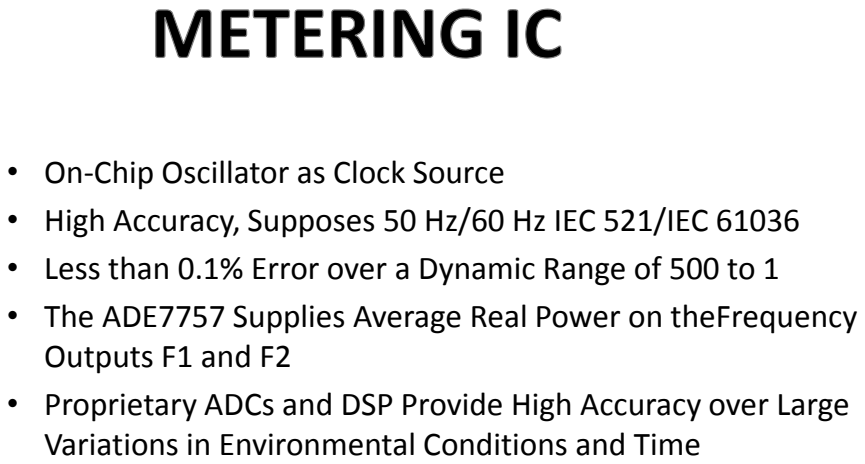
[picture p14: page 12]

• On-Chip Oscillator as Clock Source
• High Accuracy, Supposes 50 Hz/60 Hz IEC 521/IEC 61036
• Less than 0.1% Error over a Dynamic Range of 500 to 1

Outputs F1 and F2
• Proprietary ADCs and DSP Provide High Accuracy over Large
Variations in Environmental Conditions and Time

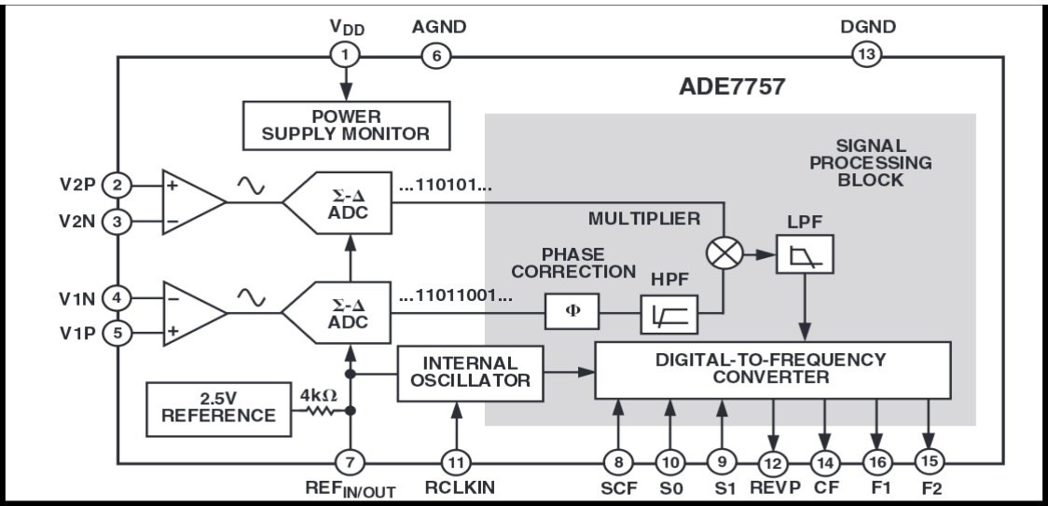
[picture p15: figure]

•ADC used is a Sigma Delta
•On-Chip Power Supply Monitoring
•On-Chip Creep Protection (No Load Threshold)
•On-Chip Reference 2.5 V (20 ppm/C Typical) with External Overdrive Capability
•Single 5 V Supply, Low Power (20 mW Typical)
•Low Cost CMOS Process
•AC Input Only

Sample Circuit to read details
from the sensing circuit using ADE7757

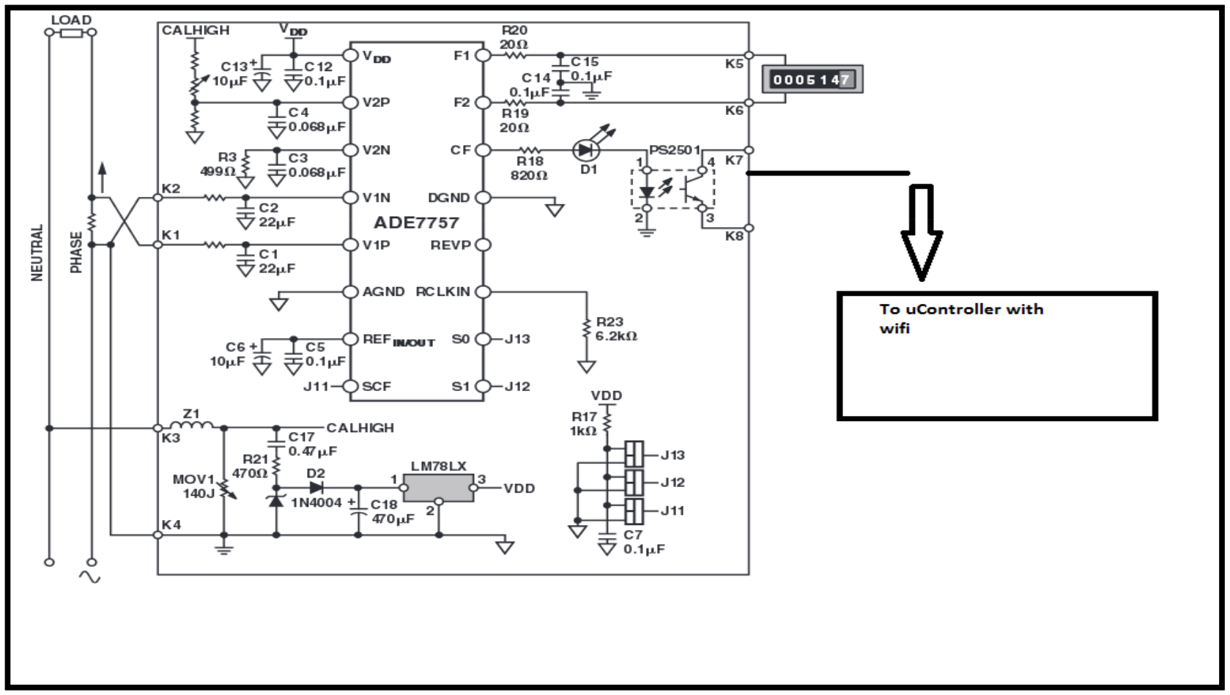
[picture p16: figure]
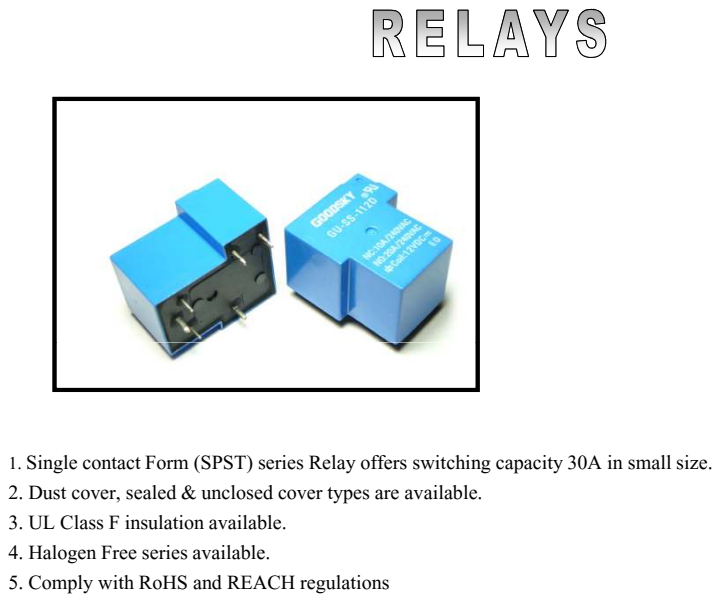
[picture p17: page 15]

1. Single contact Form (SPST) series Relay offers switching capacity 30A in small size.
2. Dust cover, sealed & unclosed cover types are available.
3. UL Class F insulation available.
4. Halogen Free series available.
5. Comply with RoHS and REACH regulations

•Power Consumption | : | 0.93 W
•Dielectric Strength
•:
AC, 1500V (between coil and contact). AC, 1500VBetween Contacts

•Life Expectancy:
•Mechanical 10 ^ 7 = 10000000 times at No load condition
•Electrical 10 ^ 5 = 100000 at resistive load

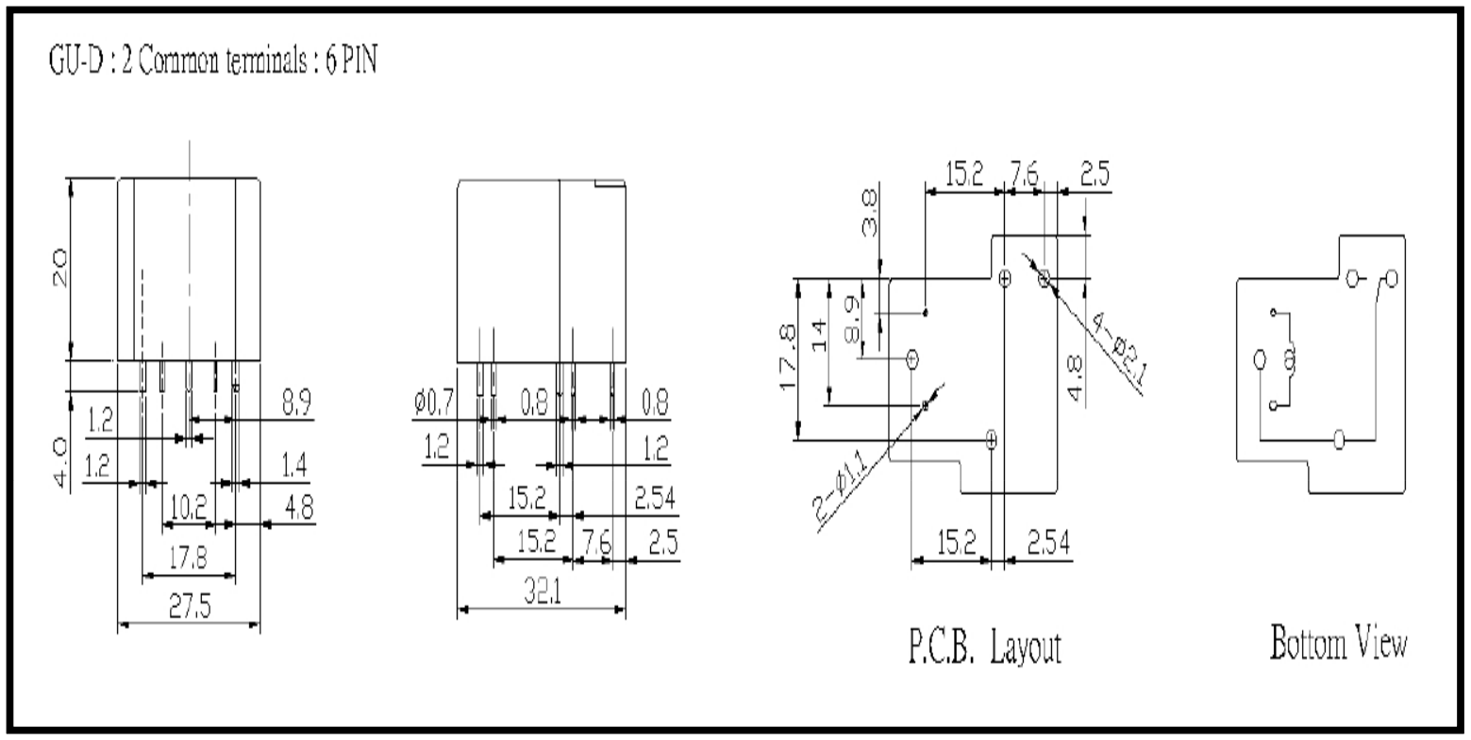
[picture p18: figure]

### PENDING ITEMS

- PCB BOARD -
- BOXING
- ACCESSING SOFTWARES….

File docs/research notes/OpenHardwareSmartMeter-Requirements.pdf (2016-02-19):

## OpenStrom ‐ Open Hardware Smart Meter Requirements

Please send feedback to m.zeitler@openstrom.com

The idea is to build an open hardware smart meter that can measure and control 10 circuits and will be used by makers and system integrators as part of their own smart electricity applications and projects. It will be connected via LAN /wifi to the internet.

1
The main difference to existing smart meters is that we want to create an open solution (not proprietary systems), get a higher level of details (voltage/current/power factor, not only energy) and have relays to do some simple automation tasks compared to other commercial smart meters.
Also we want to get into a €30 price range for manufacturing costs (assuming contract manufacturing in China and an initial batch size of about 1000 units; not considering tooling and other manufacturing setup costs). This would allow a sales price around €100.

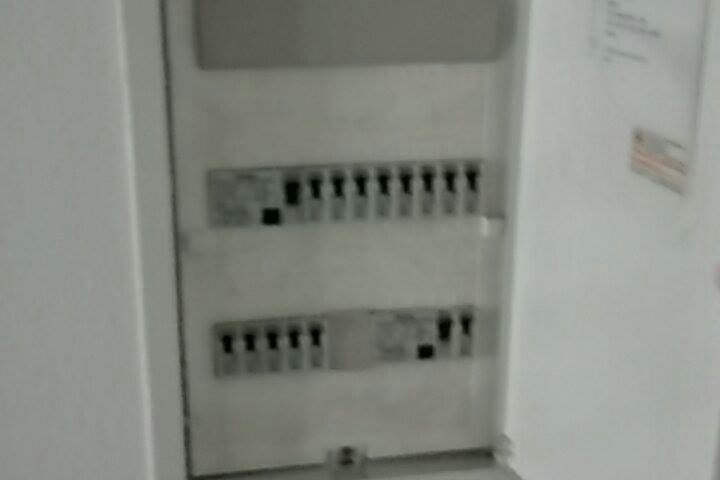
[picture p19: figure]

The solution consists of one (or more) din rail mounted hardware devices that plug directly into the main fuse box, the firmware that interacts with the sensors/relays and a simple backend server that logs the data and performs simple automation tasks.

The scope of this requirements document is the hardware aspect of the project. The backend system will be described in a different document.

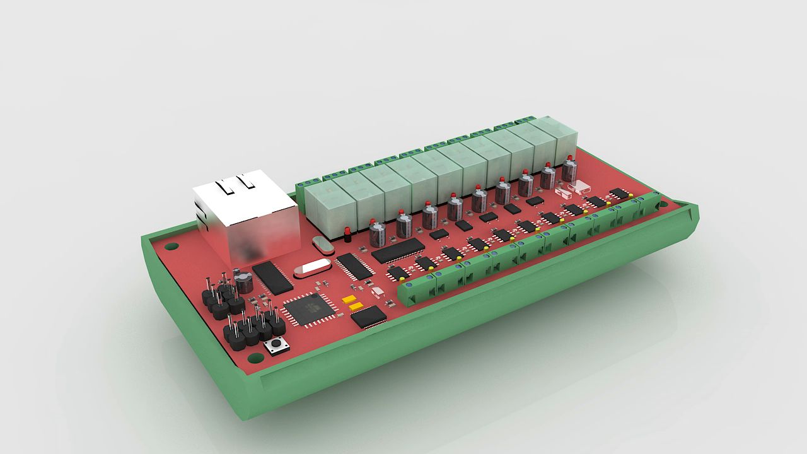
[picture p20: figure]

We will provide a firmware that logs the data and accepts on/off commands for circuits via simple HTTP/XML communication. Special focus has to be put on the easy initial setup of the device, the ability to do firmware updates and safety/regulatory requirements.

Even though we expect others to use our smart meter in their solutions and will not design the final applications for endusers, our smart meter should support a wide range of use cases like:

people that run data centers and want to know individual consumption data to determine if old hardware should be replaced

1 There are currently no MCUs available that have Wifi and LAN on the chip. A possible solution for LAN is using Wiznet W5200, preferably as an addon as it is not clear if we need to support wifi and LAN for most users.

industrial or agricultural use cases to see if machinery has an unusual energy pattern (like a blocked pump).
consumer use cases where people want to monitor their whole house and do simple home automation by switching circuits on and off

We will NOT cover the public power utility use case where energy consumption is metered and billed to the end customer. This use case has a lot of regulatory requirements and already huge competition, so we will stay away from it. This reduces our requirements and costs significantly.

The hardware has to be able to cover a range of use cases and we see the following requirements:

measure electric power (P), reactive power (Q), apparent power (S), electric current (I), voltage (V), power factor (cos phi), others?
detecting specific appliances through energy disaggregation

2
The idea is to do this on the backend (cloud), however depending on our sampling frequency this means we would potentially need to send a lot for data which could be a problem. So maybe a combination of some kind of “patterns” detection on the device and backend data processing is required.
Also there are challenges getting into our target price range when aiming really high sampling (MHz range), so we will most likely limit this to 10kHz.
detecting unusual patterns (e.g. a fridge using coolant and requiring more power than normal or a freezer that needs thawing/cleaning)
switching off/on a whole circuit (we are not switching appliances, but the whole phase)
This has a massive impact on size of the device and the cost to build it. I would prefer to build only one device (because of easier certification, testing,
manufacturing, logistics etc.) instead of different models, but maybe we can make the switching functionality somewhat modular, so that the relays can be added via some kind of “shield” to the device to allow users to buy the device with and without switching functionality.
combine multiple smart meters to interact with more than 10 circuits (most likely by combining them in the backend software). The management/aggregation of data will be done on the backend, so that we install multiple devices with the same hardware to accomplish this.
fault tolerance (what happens when we lose internet connectivity or if we have a failure on one of the circuits). This might require some local data storage (if internet is lost) and some failure mode for switching (to prevent circuits to be permanently on or off when internet is lost). Also consider “missed” data packets and other similar error scenarios.

2
http://web.stanford.edu/group/peec/cgibin/docs/events/2011/becc/presentations/3%20Disaggregation%20The%20Holy%20Grail%20-%20Carrie%20Armel.pdf (http://web.stanford.edu/group/peec/cgi-bin/docs/events/2011/becc/presentations/3%20Disaggregation%20The%20Holy%20Grail%20-%20Carrie%20Armel.pdf)

Some initial considerations regarding components:

Which MCU to use? Arduino would be great (very open), but maybe not enough processing power and possible issues with wifi
Check: TI CC3200 and HLK-RMO4; also maybe ESP8266; also check MediaTek MT7681
How to measure? Should we use a sensor chip or should we design our own circuit Check: ADE7753ARSZRL and CS5484; also maybe 78M6618 or STPM32/33/34 or ATM90E26
| Which relays should we use? Something like SSR25A might make it expensive for
| 10 circuits (especially if not everyone is using the switching functionality). Can the
| switching functionality be like an addon “shield”?
| Check: T90S5D12-5 , jqx-15f , HF102F, JQX-102F
Also consider power consumption of the device. Latching/solid state relays?
Doing our own custom housing might be cost prohibitive for small production runs (as
| it would require injection molding). Can we fit our solution into a “standard” DIN rail
| housing? Which one?
Everything should be as integrated as possible to reduce manufacturing and
| installation. Power supply has to be on the board itself.
What is required to test the functionality of the device during manufacturing to
| prevent that we ship defective devices? Test points?
The solution should be marketed worldwide (main focus: USA and European Union).
| There are several legal requirements to market electronic products in these markets
| like the CE mark, electromagnetic compatibility (EMC 2014/30/EU) and the low
| voltage directive 2014/35/EU. There might be other relevant regulations.
| The relevant legal requirements must be identified and considered when designing
| the device.

Roadmap:
Based on these initial requirements we will develop a technical specification and ask for feedback from the smart meter community and possible customers.
The idea is to build a working prototype, already designed for manufacturing and designed to cost.
After the prototype is completed, a vendor selection with different contract manufacturing companies will initiated to get quotes.
Then a crowdfunding campaign will be launched to presell the first production run.
In parallel we will develop the initial firmware and backend for the system.

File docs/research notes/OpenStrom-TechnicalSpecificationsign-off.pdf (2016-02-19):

# OpenStrom Topics and Structure of Technical Specification

The goal of the technical specification document is to have a basis to design the solution. The high level requirements of our solution are listed here: https://docs.google.com/document/d/1AJmYfzObi8I9YgZ2tjCaWna7VfgmVBiYcD5WFaKjvU

The technical specification will probably have between 15 and 30 pages and look similar (in terms of formatting and outline) to this document: http://files.opencompute.org/oc/public.php?service=files&t=4bb682624927b315b4f3d8a30f0 22c19 (http://files.opencompute.org/oc/public.php?service=files&t=4bb682624927b315b4f3d8a30f022c19)

The document should be broken down into individual sections that outline the solution. This is not a complete list of aspects that need to be considered for each section of the document, but rather a starting point for you.

MCU:
| Is it powerful enough for our use cases? (cpu/ram)
| oWhat is the maximum sampling rate and how much data would need to be
| processed on the unit and how much data would be sent to the backend
| oCan we support energy disaggregation on the unit?
| oCan we support event detection (appliance turned on/off or unusual energy
| consumption patterns) on the unit?
| oCan we use data compression on the unit to reduce the amount of data we
| sent to the backend?
| What is available on the chip?
| oWifi
| oLAN
| oGPIO (how many?)
| oI2C?
| oOther interesting functions (for future extensions and to allow users to hack
| the device with their own stuff)

Data / API:
| JSON and/or XML to transfer data (needs spec of format)
| Compression
| Frequency of sending data and packet size for different sampling rates
| Device should always initiate connection to backend, so that we can rule out any
security issue by making the device accessible to the internet. So no incoming connections. This means that the switching of circuits needs to be triggered by the confirmation message after sending data or by some polling mechanism. Also consider “missed” messages or stuck relays, so the device should also receive the total expected relay status from the server, not only a single on/off command.

Sensors:
| Which data can be collected by sensors?
| What is the resolution of the sensor and what the maximum collection frequency?

Relays:
| Expected lifetime of relay
| Power draw of relay
| Plugin/Shield for relays to save cost? Basically this would mean that the device works
without relays, but we can just add a special relay board to add switching functionality. (using the same housing and pretty much the same manufacturing steps to get two versions of the device). What are the advantages/disadvantages of this approach?

Power Supply:
| Expected lifetime
| Temperature / heat

Housing/Enclosure:
| Do we need a custom mold? Or can we use a standard housing? Which one?
| Heat issues
| Electric magnetic shielding required?
| Wifi antenna required?

Firmware:
How does the initial setup of the network connectivity work? (see http://www.ti.com/lit/wp/swry011/swry011.pdf). Should support: Wifi Protected Setup , Access Point Mode until internet connectivity is established, Smart Config app via phone
| How does the user/device enter the initial setup mode?
| How can users update the firmware? Can they brick the device? How to unbrick?
| How can the initial firmware be loaded during manufacturing (fast)
| How can we assign a unique device identifier that we can use to connect devices to the
backend service
| Do we need to set MAC address during manufacturing?
| What security considerations do we need to consider?

Legal / Regulatory
Which laws and regulations do we need to consider to market the device in the US and in the EU?

PCB:
| What connectors do we need? (how do they align with the housing?)
| Do we need a reset or on/off switch? What happens with the relays if we turn the device
off?
Do we support addons, shields or other extensions that users can use to add functionality to the device? (like additional sensors for e.g. temperature?)

Pricing:

Are we at the €30-€35 BOM cost?

Components:
The component selection is part of the design phase, however the technical specification should already reference the different options listed in the requirements and do a quick assessment if these components are suitable. Use a table format that has the component and the relevant parameters at the end of each section.

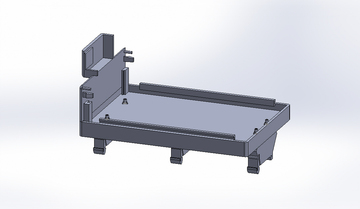
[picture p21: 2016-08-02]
housing/v0.2 - design for prototpye/Part1.JPG

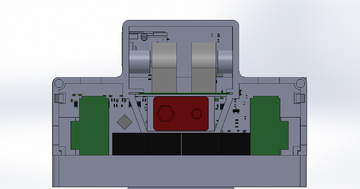
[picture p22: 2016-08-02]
housing/v0.2 - design for prototpye/Assem1 _Back View.JPG

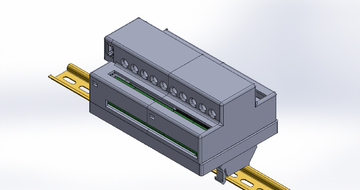
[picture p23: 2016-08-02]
housing/v0.2 - design for prototpye/Assem1.JPG

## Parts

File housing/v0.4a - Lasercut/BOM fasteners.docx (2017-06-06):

| Part | Qty | Link to order
1 | Standoff M3x45 | 16 | http://www.tme.eu/bg/details/tfm-m3x45_dr224/distantsionni-metalni-elementi/dremec/224x45/
2 | Standoff M3x18 | 8 | http://www.tme.eu/bg/details/tff-m3x18_dr124/distantsionni-metalni-elementi/dremec/124x18/
3 | Spacer 4.3x25 | 8 | http://www.tme.eu/bg/details/dr318_4.3x25/distantsionni-metalni-elementi/dremec/31843x25/
4 | Spacer 4.3x4 | 12 | http://www.tme.eu/bg/details/dr318_4.3x4/distantsionni-metalni-elementi/dremec/31843x04/
5 | Screw M3x10 | 16 | http://www.tme.eu/bg/details/b3x10_bn1719/boltove/bossard/1370162/
6 | Screw M4x16 | 12 (+4) | http://www.tme.eu/bg/details/b4x16_bn3334/boltove/bossard/1538772/
7 | Screw M4x40 | 8 | http://www.tme.eu/bg/details/b4x40_bn3334/boltove/bossard/1538829/
8 | Nut M4 | 20 | http://www.tme.eu/bg/details/b4_bn115/gayki/bossard/m4bn115/
9 | Nut M3 | 4 (+6) | http://www.tme.eu/bg/details/b3_bn115/gayki/bossard/m3bn115/
10 | Screw M3x5 | 4 (+2) | http://www.tme.eu/bg/details/b3x5_bn344/boltove/bossard/1131079/
11 | Screw M4x10 | 2 (+9) | http://www.tme.eu/bg/details/b4x10_bn3334/boltove/bossard/1538748/
12 | Screw M3x16 | (4) | http://www.tme.eu/bg/details/b3x16_bn3334/boltove/bossard/1538640/
13 | Screw M4x6 | (12) | http://www.tme.eu/bg/details/b4x6_bn384/boltove/bossard/1154494/

- - Numbers in brackets are for the 3D printed housing.

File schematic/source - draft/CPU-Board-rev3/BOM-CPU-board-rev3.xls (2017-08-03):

Comment | Designator | Quantity | Manufacturer | Suppl.PN# | Supplier | Mfr.PN# | PackageReference
4.8V/300mAh | Battry pack 4xaaa | 1 | Guangdong, China (Mainland) |  | https://www.google.bg/search?q=battery+pack+aaa+4.8v+300mah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 | HW-NiMH 4.8v 300-2/3AAA
1uF/6.3V | C7, C16, C28, C46, C59, C64, C78, C81, C93, C99, C111, C117 | 12 | Murata | 490-1320-1-ND | DigiKey | GRM155R60J105KE19D | 0402
22uF/6.3V | C8, C10 | 2 | Murata | 490-1824-2-ND | Digi-Key | GRM31CR60J226KE19L | 1206
100nF/6.3V | C9, C11, C13, C14, C24, C27, C30, C34, C36, C37, C38, C40, C41, C44, C45, C52, C53, C57, C60, C63, C67, C71, C72, C75, C77, C82, C88, C89, C91, C95, C100, C105, C107, C110, C112, C116, C123, C124, C125 | 39 | Taiyo Yuden | 587-1227-1-ND | Digi-Key | CRM155R71H103KA880 | 0402
10uF/6.3V | C12, C15 | 2 | Murata | 490-13238-6-ND | Digi-Key | GRM155R60J106ME15D | 0402
150pF/10V | C17, C50, C51, C69, C70, C86, C87, C104, C106, C121, C122 | 11 | Wurth Electronics | 732-7432-1-ND | Digi-Key | 885012005014 | 0402
10pF/50V | C18, C19, C20, C21 | 4 | Murata | 490-6186-1-ND | Digi-Key | GRM1555C1H100FA01D | 0402
470pF/7.5kV | C22 | 1 | Murata | 81-DHRB5AD471M1CB | Mouser | DHRB5AD471M1CB | 1801
22nF/16V | C23 | 1 | Murata Electronics | 490-3884-1-ND | 490-5407-6-ND | GRM155R71H223KA12D | 0402
30pF/50V | C25, C26 | 2 | Murata | 399-7785-1-ND | KEMET | C0402C300J5GACTU | 0402
150pF/10V | C29, C32, C33, C56, C61, C62, C74, C79, C80, C96, C97, C98, C108, C113, C115 | 15 | Wurth Electronics | 732-7432-1-ND | Digi-Key | 885012005014 | 0402
470uF/6.3V | C31 | 1 | Nichicon | 493-4019-3-ND | Digi-Key | RL80J471MDNASQKX | Radial Can
10n/16V | C35, C43, C48, C54, C65, C66, C68, C73, C83, C84, C85, C90, C94, C101, C102, C103, C114, C118, C119, C120 | 20 | Murata Electronics | GRM155R71C103KA01D, GRM155R71C103KA01D, GRM155R71C103KA01D, GRM155R71C103KA01D, 490-1313-1-ND, GRM155R71C103KA01D, GRM155R71C103KA01D, GRM155R71C103KA01D, GRM155R71C103KA01D, GRM155R71C103KA01D, GRM155R71C103KA01D, GRM155R71C103KA01D, GRM155R71C103KA01D, GRM155R71C103KA01D, GRM155R71C103KA01D, GRM155R71C103KA01D, GRM155R71C103KA01D, GRM155R71C103KA01D, GRM155R71C103KA01D, GRM155R71C103KA01D | Digi-Key | GRM155R71C103KA01D | 0402
4.7uF/16V | C39 | 1 | Samsung | 1276-6836-1-ND | DigiKey | CL05A475MO5NUNC | 0402
22pF/6.3V | C42, C47 | 2 | Murata | 490-8170-1-ND | DigiKey | GRM1555C1E120JA01D | 0402
LED2 | D2, D7, D8, D9, D14, D15 | 6 | Lite-On Inc | 160-1446-2-ND | Digi-Key | LTST-C191KGKT | 0603
ES3A | D4, D16 | 2 | Fairchild Co | ES3AFSCT-ND | DigiKey | ES3A | DO-214AC
1N4148 | D5 | 1 | Vishay | 1N4148W-E3-18CT-ND | Digikey | 1N4148W-E3-18 | SOD-123
MM3Z4V7 | D6 | 1 | Fairchild Semi | MM3Z4V7BCT-ND | DigiKey | MM3Z4V7B | SOD-323F
RJ45-GENERIC | J1 | 1 | Assman WSW Components | AE10384-ND | DigiKey | A-2004-2-4-LP-N-R
Header2x1 | J2, J3, J4, J5, J6, J7 | 6 |  | S9014E-02-ND | Digikey
4.7uH/2.6A | L2 | 1 | Bourns | 490-10791-1-ND | DigiKey | SDR7045-6R8M | 2-SMD
FB1/120 Ohms | L3 | 1 | Murata Electronics | 490-1037-1-ND | Digi-Key | BLM18PG121SN1D | 0603
FeILB | L4, L5, L6, L7, L8, L9, L10, L11, L12, L13, L14, L15, L16, L17, L18, L19, L20, L21, L22, L23, L24, L25, L26, L27, L28, L29, L30, L31, L32, L33 | 30 | Brand Samsung | 1276-6326-1-ND | Digi-Key | C1M10J152NC | 0603
ESP8266-WROOM-02 | M1 | 1 |  | ESP8266-WROOM-02 | Alixpress | https://www.aliexpress.com/store/product/ESP8266-serial-WIFI-model-ESP-WROOM-02-Authenticity-Guaranteed/431798_32319251013.html
MRF24J40MA | M2 | 1 | Microchip | MRF24J40MDT-I/RMCT-ND | Digi-Key | MRF24J40MDT-I/RM
Header 5 | P1, P4 | 2 |  | S9014E-05-ND | Digikey
Header 24 | P2 | 1 | Sullins Connector Solution | S7057-ND | Digikey | PPPC241LFBN-RC
Header 13 | P3 | 1 | Sullins Connector Solution | S7046-ND | Digikey | PPPC131LFBN-RC
Header 5X2 | P5 | 1 | Samtec Inc | SAM8798-ND | Digikey | FTSH-105-01-L-D-K
Wifi-Ext Connector | P6 | 1 |  | S9014E-05-ND | Digikey
Fan Connector | P7 | 1 |  | S9014E-05-ND | Digikey
PWR2.5 | PJ1 | 1 | CUI Inc | CP1-022PJCT-ND | Digikey | PJ1-022-SMT-TR
MMBT3906 | Q1 | 1 | On Semi | MMBT3906LT1GOSCT-ND | DigiKey | MMBT3906LT1G | SOT23-3
MMBT2222 | Q2 | 1 | Diodes Inc. | MMBT2222A-FDICT-ND | Digi-Key | MMBT2222A-7-F | SOT-323
100K | R3 | 1 | Panasonic | P100KLCT-ND | DigiKey | ERJ-2RKF1003X | 0402
47R | R4, R20 | 2 |  | P47.0LCT-ND | Digi-Key | CRCW080545R0FKTA, ERJ-6ENF47R0V | 0402
27K | R7 | 1 | Panasonic | P27.0KLDKR-ND | DigiKey | ERJ-2RKF2702X | 0402
4.7k | R9, R22, R36 | 3 | Panasonic | P4.70KLCT-ND | Digi-Key | ERJ-2RKF4701X | 0402
10R | R10, R11 | 2 | Panasonic | P10.0LDKR-ND | DigiKey | ERJ-2RKF10R0X | 0402
17.2K | R12 | 1 | Vishay Dale | 541-2080-2-ND | DigiKey | TNPW040217K2BEED | 0402
10K | R13, R16, R17, R59, R120, R121 | 6 | Panasonic | P10.0KLTR-ND, P10.0KLTR-ND, P10.0KLTR-ND, P10.0KLTR-ND, P10KJCT-ND, P10.0KLTR-ND | Digi-Key | ERJ-2RKF1002X, ERJ-2RKF1002X, ERJ-2RKF1002X, ERJ-2RKF1002X, ERJ-2GEJ103X, ERJ-2RKF1002X | 0402
0 Ohm | R14 | 1 | Vishay Dale | 541-2230-1-ND | Digi-Key | RCA0805100KFKEA | 0402
30K | R15 | 1 | Panasonic |  | DigiKey | ERJ-2RKF3002X | 0402
75K | R18 | 1 | Panasonic | P75KJDKR-ND | Digikey | ERJ-2GEJ753X | 0402
40.2K/1%/.125W | R19 | 1 | Panasonic | P40.2KLCT-ND | DigiKey | ERJ-2RKF4022X | 0402
13K | R21 | 1 | Panasonic | P13.0KLCT-ND | DigiKey | ERJ-2RKF1302X | 0402
49.9R | R23, R24, R25, R26 | 4 | Panasonic | P49.9LCT-ND | Digi-Key | ERJ-2RKF49R9X | 0402
75R | R27, R28, R33, R34 | 4 | Panasonic | P75.0LCT-ND | Digi-Key | ERJ-2RKF75R0X | 0402
30R | R29, R30, R31, R32, R35 | 5 | Panasonic | P30.0LCT-ND | Digi-Key | ERJ-2RKF30R0X | 0402
12.1k | R37 | 1 | Panasonic | P12.1KLCT-ND | Digi-Key | ERJ-2RKF1212X | 0402
220R | R38, R39, R40, R42, R47, R50, R55, R58, R63, R66, R67, R68, R74, R77, R80, R83, R87, R89, R92, R95, R101, R104, R109, R111 | 24 | Panasonic | P1.00KLCT-ND | DigiKey | ERJ-2RKF1001X | 0402
6.2R | R41, R49, R57, R64, R75, R82, R88, R94, R103, R110 | 10 | Vishay Dale | 541-6.20LLCT-ND | Digi-Key | CRCW04026R20FKED | 0402
470/1%/.250W | R45, R53, R61, R72, R78, R85, R90, R96, R106, R112 | 10 | Vishay/Draloric | 71-SMM0204-F-470 | Mouser | SMM02040C4700FB300 | 1206
1M | R46 | 1 | Panasonic | P1.00MLTR-ND | Digi-Key | ERJ-2RKF1004X | 0402
10K | R113 | 1 | Panasonic | P10.0KLCT-ND | Digikey | ERJ-2RKF1002X | 0402
10K | R114, R115, R116, R117 | 4 | Panasonic | P10.0KLCT-ND | Digikey | ERJ-2RKF1002X | 0402
Wifi - Switch | S1 | 1 | Digibay |  | http://www.digibay.in/157-smd-tactile-micro-push-button-switch | SE-DE01-09-0157 | SPST-2
TESTPOINT | TP6, TP7, TP8,TP9, TP10, TP1 ,TP14, TP15,TP16, TP17, TP26, TP27,TP7,TP8,TP28,TP29,TP30,TP50,TP51,TP52,TP53,TP54 | 30 | Harwing Inc | 952-2665-1-ND | Digikey | S2761-46R
TESTPOINT | TP2, TP3, TP4,TP5, TP11, TP11, TP12, TP13, TP17, TP18, TP19, TP20, TP21, TP21, TP22, TP23, TP24, TP25 | 25 | Sullins Connector Solution |  |  | GRPB- 01-1- VWV c-RC
HX1224CNL | TrET1 | 1 | Pulse Electronic Corporation | HX1224CNL-ND | DigiKey | HX1224CNL
PTC TMP37 | TS1 | 1 | Analog Devices | TMP37GRTZ-REEL7CT-ND | Digikey | TMP37GRTZ-REEL7
MP1470 | U2 | 1 | MPS Inc | 1589-1018-1-ND | DigiKey | MP1470GJ-P | TSOT-23-6
LAN8720A | U3 | 1 | Microchip | LAN8720A-CP-CT-ND | Digi-key | LAN8720A-CP-TR | 24 QFN
STPM34 | U4, U6, U8, U9, U10 | 5 | STMicroelectronics | 497-14670-1-ND | DigiKey | STPM34TR
PIC32MX795F512H | U5 | 1 | Microchip | PIC32MX795F512H-80I/PT-ND | Digikey | PIC32MX795F512H-80I/PT
W25Q16DVZP | U7 | 1 | Winbond Electronics | W25Q16DVZPIG-ND | DigiKey | W25Q16DVZPIG | 8-SOIC
NUD312D | U11, U13 | 2 | On Semi | NUD3112DMT1GOSCT-ND | Digikey | NUD3112DMT1G
NUD3112D | U12, U14, U15, U21 | 4 | On Semi | NUD3112DMT1GOSCT-ND | Digikey | NUD3112DMT1G
NL17SZ125 | U16, U17, U18, U19, U20 | 5 | ON Semi | NL17SZ125DTT1GOSCT-ND | Digikey | NL17SZ125DTT1G
25MHz | Y1 | 1 | KDS DAISHINKU.Corp | DSX321SH-25MHz | KDS DAISHINKU.Corp | DSX321SH-25MHz
CB-3 Oscillator | Y2 | 1 | CTS Electronics Component | 774-632L3I016M00000 | Mouser | 632L3I016M00000
8MHz | Y3 | 1 | KDS DAISHINKU.Corp | DSX321G-8MHz | KDS DAISHINKU.Corp | DSX321G-8MHz
Header 5X2 | P5 | 1 | Samtec Inc | SAM8798-ND | Digikey | FTSH-105-01-L-D-K
MRF24J40MA | M2 | 1 | Microchip | MRF24J40MDT-I/RMCT-ND | Digi-Key | MRF24J40MDT-I/RM
ZF120A-1202000 | Mini Power Supply -12V Vdc, 2.0A,24W | 1 |  |  | https://www.aliexpress.com/item/100PCS-LOT-DC12V-2A-24W-Mini-Ultra-thin-Compact-size-LED-Drive-power-supply-AC-DC/32428741080.html
DFS401012H | Mini Fan - DC2 V , 1.1W | 1 |  |  | https://ru.aliexpress.com/item/10-PCS-LOT-DC6-12V-40x40x10-40mm-4010-Small-Brushless-Cooling-Cooler-Fan/32743113432.html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

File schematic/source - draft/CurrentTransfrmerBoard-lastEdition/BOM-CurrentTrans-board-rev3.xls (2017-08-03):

Designator | Manufacturer | Mfr.PN# | PartType | Quantity | Suppl.PN# | Supplier
CT1, CT2, CT3, CT4, CT5, CT6, CT7, CT8, CT9, CT10 | NanJing ZeMing Electronics Co.Ltd | ZMCT116A | CurrentTransf | 10 |  | NanJing ZeMing Electronics Co.Ltd
P1 | ASSMAN WSW Components | 2.54mm 90 degree singlw row 13 pins | AW140-EA-G13J | 1 |  | ASSMAN WSW Components

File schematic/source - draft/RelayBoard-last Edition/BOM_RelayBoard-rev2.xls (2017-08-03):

Comment | Description | Designator | Manufacturer | Mfr.PN# | Quantity | PackageReference | Suppl.PN# | Supplier
1N4148 | 1N4001, 1N4001, 1N4001, 1N4148, 1N4001, 1N4001, 1N4001, 1N4001, 1N4001, 1N4001 | D1, D2, D3, D4, D5, D6, D7, D8, D9, D10 | Micro Commercial Co | 1N4148X-TP | 10 | SOD523 | 1N4148XTPMSCT-ND | Digikey
Relay-SPDT | Single-Pole Dual-Throw Relay | K1, K2, K3, K4, K5, K6, K7, K8, K9, K10 | Yueqing Hengwei Electronics Co. | BT-SS-1-05-D | 10 | MODULE5B | JQX15F(T90)-40-1C DC12 | Yueqing Hengwei Electronics Co.
Header 24 | Header, 24-Pin - Pin header,pitch 2.54,right-angled, single 24 pins | P1 | ASSMANN WSW components | AW140-EA-G02J | 1 |  |  | http://www.tracepartsonline.net/(S(4ypagvgyqx3mb4lo30hzmeaj))/partdetails.aspx?PartID=10-15062010-080061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
Header 2 | Header, 2-Pin | P3, P4 | TE Connectivity | 282834-2 | 2 |  | 650282834-02 | Connection Technologies
270K/5%/.5 | Resistor | R1, R2, R3, R4, R5, R6, R7, R8, R9, R10, R11, R12, R13, R14, R15, R16, R17, R18, R19, R20, R21, R22, R23, R24, R25, R26, R27, R28, R29, R30 | Panasonic | ERJ-14YJ274U | 30 | 1210 | P270KVCT-ND | DigiKey
DG135-3 | Header, 3-Pin | TB1, TB2, TB3, TB4, TB5, TB6, TB7, TB8, TB9, TB10 | SMparts/www.smparts.com | DG135T-10.16-04P-13-00A(H)-3pin | 10 |  | DG-135DG135T-10.16-04P-13-00A(H) | SMparts/www.smparts.com
DG135-1 | Socket | TB-1, TB-2 | SMparts/www.smparts.com | SMparts/www.smparts.com | 2 |  | SMparts/www.smparts.com | SMparts/www.smparts.com

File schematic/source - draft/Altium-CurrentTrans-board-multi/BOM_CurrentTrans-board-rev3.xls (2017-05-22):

Designator | Manufacturer | Mfr.PN# | PartType | Quantity | Suppl.PN# | Supplier | Link
CT1, CT2, CT3, CT4, CT5, CT6, CT7, CT8, CT9, CT10 | NanJing ZeMing Electronics Co.Ltd | ZMCT116A | CurrentTransf | 10
P1 | JYR Ecec Co.,Ltd China | 2.54mm 90 degree singlw row 13 pins | Header 13 | 1 |  | Alibaba | http://jyrcon.en.alibaba.com/product/60262288613-800882385/2_54mm_pitch_single_row_3_pin_male_header_90degree.html

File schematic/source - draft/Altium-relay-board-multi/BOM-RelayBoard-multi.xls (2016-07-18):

Item No | Comment | Description | Designator | Manufacturer | Mfr.PN# | Quantity | Suppl.PN# | Supplier | PackageReference | Links
1 | 1N4148 | 1N4148 | D1, D2, D3, D4, D5, D6, D7, D8, D9, D10 | Micro Commercial Co | 1N4148X-TP | 10 | 1N4148XTPMSCT-ND | Digikey | SOD523 | http://www.digikey.com/product-search/en?keywords=1N4148XTPMSCT-ND
2 | Relay-SPDT | Single-Pole Dual-Throw Relay | K1, K2, K3, K4, K5, K6, K7, K8, K9, K10 | Yueqing Hengwei Electronics Co. | JQX16(T91) | 10 | JQX16(T91) | Yueqing Hengwei Electronics Co. | MODULE5B | http://mollelec.en.made-in-china.com/product/CvLEGXrPOfVY/China-Air-Conditioning-Jqx-16-Relay.html
3 | Header 24 | Header, 24-Pin | P1 | ASSMANN WSW components | AW140-EA-G02G | 1 |  |  |  | https://www.verical.com/pd/assmann--aw140-ea-g02g-1721380
4 | 270K/5%/.5 | Resistor | R1, R2, R3, R4, R5, R6, R7, R8, R9, R10, R11, R12, R13, R14, R15, R16, R17, R18, R19, R20, R21, R22, R23, R24, R25, R26, R27, R28, R29, R30 | Panasonic | ERJ-14YJ274U | 30 | P270KVCT-ND | DigiKey | 1206 | http://www.digikey.com/product-search/en?keywords=P270KVCT-ND
5 | DG135 | Header, 3-Pin | TB1, TB2, TB3, TB4, TB5, TB6, TB7, TB8, TB9, TB10 | SMParts | DG-135-10.16-3 | 10 | DG-135-10.16-3 | SMParts |  | http://smparts.com/
6 | DG135-1 | Socket | TB-1 | SMParts | DG135.10.16-1 | 1 | SMParts | DG135.10.16-1 |  | http://smparts.com/

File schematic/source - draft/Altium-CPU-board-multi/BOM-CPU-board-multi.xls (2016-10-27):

Comment | Designator | Price | Quantity | Manufacturer | Suppl.PN# | Supplier | Mfr.PN# | PackageReference | Link
9.0V | BT1- Battery 9v/250mAh | 1 | 1 | Guangdong, China (Mainland) |  | Alibaba | PICCELL | BAT-2 | https://www.alibaba.com/product-detail/9v-Rechargeable-Nimh-Battery-With-250mah_60442896775.html Link
10n/16V | C35, C43, C48, C54, C65, C66, C68, C73, C83, C84, C85, C90, C94, C101, C102, C103, C114, C118, C119, C120, C123 | .002 | 22 | Murata Electronics | GRM155R71C103KA01D, GRM155R71C103KA01D, GRM155R71C103KA01D, GRM155R71C103KA01D, GRM155R71C103KA01D, 490-1313-1-ND, GRM155R71C103KA01D, GRM155R71C103KA01D, GRM155R71C103KA01D, GRM155R71C103KA01D, GRM155R71C103KA01D, GRM155R71C103KA01D, GRM155R71C103KA01D, GRM155R71C103KA01D, GRM155R71C103KA01D, GRM155R71C103KA01D, GRM155R71C103KA01D, GRM155R71C103KA01D, GRM155R71C103KA01D, GRM155R71C103KA01D, GRM155R71C103KA01D, GRM155R71C103KA01D | Digi-Key | GRM155R71C103KA01D | 0402 | http://www.digikey.com/product-detail/en/murata-electronics-north-america/GRM155R71C103KA01D/490-1313-1-ND/587926
10uF/6.3V | C12, C15 | .049 | 3 | Murata | 490-13238-6-ND | Digi-Key | GRM155R60J106ME15D | 0402 | http://www.digikey.com/product-search/en?keywords=490-13238-6-ND
100nF/6.3V | C9, C11, C13, C14, C24, C27, C30, C34, C36, C37, C38, C40, C41, C44, C45, C46, C52, C53, C57, C60, C63, C67, C71, C72, C75, C77, C82, C88, C89, C91, C95, C100, C105, C107, C110, C112, C116, C123, C124 | .002 | 40 | Taiyo Yuden | 587-1227-1-ND | Digi-Key | LMK105BJ104KV-F | 0402 | http://www.digikey.com/product-search/en?keywords=587-1227-1-ND
1uF/6.3V | C7, C16, C28, C46, C59, C64, C78, C81, C93, C99, C111, C117 | .049 | 11 | Murata | 490-1320-1-ND | DigiKey | GRM155R60J105KE19D | 0402 | http://www.digikey.com/product-search/en?keywords=490-1320-1-ND
22uF/6.3V | C8, C10 | .049 | 2 | Murata | 490-1824-2-ND | Digi-Key | GRM31CR60J226KE19L | 1206 | http://www.digikey.com/product-search/en?keywords=490-1824-2-ND
150pF | C17, C50, C51, C69, C70, C86, C87, C104, C106, C121, C122 | .002 | 11 | Wurth Electronics | 732-7432-1-ND | Digi-Key | 885012005014 | 0402 | http://www.digikey.com/product-search/en?keywords=732-7432-1-ND
10pF/50V | C18, C19, C20, C21 | .03 | 4 | Murata | 490-6186-1-ND | Digi-Key | GRM1555C1H100FA01D | 0402 | http://www.digikey.com/product-search/en?keywords=490-6186-1-ND
470pF/7.5k | C22 | .0096 | 1 | Vishay | 564R75GAT47 | Digikey | 564R75GAT47-ND | thoughhole | http://www.digikey.com/product-search/en?keywords=564R75GAT47-nd
22nF/16V | C23 | .0096 | 1 | Murata Electronics | 490-3884-1-ND | 490-5407-6-ND | GRM155R71H223KA12D | 0402 | http://www.digikey.com/product-search/en?keywords=490-3884-1-ND
18pF/6.3V | C25, C26 | 0402 | 2 | Murata | 490-6172-1-ND | Digi-Key | GRM1555C1E180JA01D | 0402 | http://www.digikey.com/product-search/en?keywords=490-6172-1-ND
150pF/10V | C29, C32, C33, C56, C61, C62, C74, C79, C80, C96, C97, C98, C108, C113, C115 | .002 | 15 | Wurth Electronics | 732-7432-1-ND | Digi-Key | 885012005014 | 0402 | http://www.digikey.com/product-search/en?keywords=732-7432-1-ND
470uF/6.3V | C31 | .065 | 1 | Nichicon | 493-4019-3-ND | Digi-Key | RL80J471MDNASQKX | Radial Can | http://www.digikey.com/product-search/en?keywords=493-4019-3-ND
4.7uF/16V | C39 | 0.1 | 1 | Samsung | 1276-6836-1-ND | DigiKey | CL05A475MO5NUNC | 0402 | http://www.digikey.com/product-search/en?keywords=1276-6836-1-ND
LED2 | D2, D7, D8, D9, D20, D21 | .04 | 17 | Lite-On Inc | 160-1446-2-ND | Digi-Key | LTST-C191KGKT | 0603 | http://www.digikey.com/product-search/en?keywords=160-1446-2-ND
ES1A | D4 | .142 | 1 | Fairchild Co | ES1A | DigiKey | ES1AFSCT-ND | DO-214AA | http://www.digikey.com/product-detail/en/fairchild-semiconductor/ES1A/ES1AFSCT-ND/3042545
1N4148 | D5 | 0.14 | 1 | Vishay | 1N4148W-E3-18CT-ND | Digikey | 1N4148W-E3-18 | SOD-123 | http://www.digikey.com/product-search/en?keywords=1N4148W-E3-18CT-ND
Zener 9.1V | D6 | 0.21 | 1 | NXP Semi | 568-12284-1-ND | DigiKey | BZX84-C9V1,235 | SOT23-3 | http://www.digikey.com/product-detail/en/nxp-semiconductors/BZX84-C9V1,235/568-12284-1-ND/5221780
RJ45-GENERIC | J1 | 0.32 | 1 | Assman WSW Components | AE10384-ND | DigiKey | A-2004-2-4-LP-N-R |  | http://www.digikey.com/product-search/en?keywords=AE10384-ND
4.7uH/2.6A | L2 | .82 | 1 | Bourns | 490-10791-1-ND | DigiKey | SDR7045-6R8M | 2-SMD | http://www.digikey.com/product-search/en?keywords=490-10791-1-ND
FB1/120 Ohms | L3 | .288 | 1 | Murata Electronics | 490-1037-1-ND | Digi-Key | BLM18PG121SN1D | 0603 | http://www.digikey.com/product-search/en?keywords=490-1037-1-ND
FeILB | L4, L5, L6, L7, L8, L9, L10, L11, L12, L13, L14, L15, L16, L17, L18, L19, L20, L21, L22, L23, L24, L25, L26, L27, L28, L29, L30, L31, L32, L33 | .027 | 30 | Brand Samsung | 1276-6326-1-ND | Digi-Key | C1M10J152NC | 0603 | http://www.digikey.com/product-search/en?keywords=1276-6326-1-ND
MRF24J40MA | M1 | 6.08 | 1 | Microchip | MRF24J40MDT-I/RMCT-ND | Digi-Key | MRF24J40MDT-I/RM |  | http://www.digikey.com/product-search/en?keywords=MRF24J40MDT-I%2FRMCT-ND
ESP-WROOM-02 | M2 | 3.0 | 1 |  | ESP-WROOM-02 |  |  |  | http://espressif.com/en/products/hardware/esp-wroom-02/resources
Header 5 | P1 | 0.22 | 4 |  | S9014E-05-ND | Optional depend of debugger |  |  | http://www.digikey.com/product-search/en?keywords=S9014E-05-ND
Header 24 | P2 | 0.3 | 1 | Guagdong, China |  |  | PH2.54-A201 |  | https://www.alibaba.com/product-detail/single-row-straight-24pin-female-header_925058879.html
Header 13 | P3 | 0.2 | 1 | Guangdong, China (Mainland) |  |  | EL1734164865 |  | https://www.alibaba.com/product-detail/single-row-straight-24pin-female-header_925058879.html
MMBT3906 | Q1 | 0.022 | 1 | On Semi | MMBT3906 | Verical | MMBT3906LT1G | SOT23-3 | http://www.digikey.com/product-detail/en/on-semiconductor/MMBT3906LT1G/MMBT3906LT1GOSCT-ND/1139817
MMBT2222 | Q2 | 0.022 | 11 | Diodes Inc. | MMBT2222ALT1G | Verical | MMBT2222A-7-F | SOT23-3 | http://www.digikey.com/product-search/en?keywords=MMBT2222A-FDICT-ND
100K | R3 | .0035 | 2 | Panasonic | P100KLCT-ND | DigiKey | ERJ-2RKF1003X | 0402 | http://www.digikey.com/product-search/en?keywords=P100KLCT-ND
220R | R40, R42, R47, R50, R55, R58,R38,R39, R63, R66, R74, R77, R80, R83, R87, R89, R92, R95, R101, R104, R109, R111, R113, R114 | .0035 | 24 | Panasonic | P1.00KLCT-ND | DigiKey | ERJ-2RKF1001X | 0402 | http://www.digikey.com/product-search/en?keywords=P1.00KLCT-ND
47R | R4, R20, R35 | .0035 | 3 | Panasonic | P47.0LCT-ND | Digi-Key | CRCW080545R0FKTA, ERJ-6ENF47R0V, CRCW080545R0FKTA, CRCW080545R0FKTA, CRCW080545R0FKTA | 0402 | http://www.digikey.com/product-search/en?keywords=P47.0LCT-ND
10K | R113,R114,R115,R116,R117 | .0035 | 5 | Panasonic | P10.0KLTR-ND | Digi-Key | ERJ-2RKF1002X | 0402 | http://www.digikey.com/product-search/en?keywords=P10.0KLTR-ND
27K | R7, R15 | .0035 | 2 | Panasonic | P27.0KLDKR-ND | DigiKey | ERJ-2RKF2702X | 0402 | http://www.digikey.com/product-search/en?keywords=P27.0KLDKR-ND
4.7k | R9, R22, R36 | .1 | 3 | Panasonic | P4.70KLCT-ND | Digi-Key | ERJ-2RKF4701X | 0402 | http://www.digikey.com/product-search/en?keywords=P4.70KLCT-ND
10R | R10, R11 | .0035 | 2 | Panasonic | P10.0LDKR-ND | DigiKey | ERJ-2RKF10R0X | 0402 | http://www.digikey.com/product-search/en?keywords=P10.0LDKR-ND
57.6K | R12 | .0035 | 1 | Panasonic | P57.6LCT-ND | DigiKey | ERJ-2RKF57R6X | 0402 | http://www.digikey.com/product-search/en?keywords=P57.6LCT-ND
0/125W | R14 | .0035 | 1 | Vishay Dale | 541-2230-1-ND | Digi-Key | RCA0805100KFKEA | 0402 | http://www.digikey.com/product-search/en?keywords=541-2230-1-ND
75K/1%/.125W | R18 | .0035 | 1 | Panasonic | P75KJDKR-ND | Digikey | ERJ-2GEJ753X | 0402 | http://www.digikey.com/product-search/en?keywords=P75KJDKR-ND
40.2K/1%/.125W | R19 | .0035 | 1 | Panasonic | P40.2KLCT-ND | DigiKey | ERJ-2RKF4022X | 0402 | http://www.digikey.com/product-search/en?keywords=P40.2KLCT-ND
13K | R21 | .0035 | 1 | Panasonic | P13.0KLCT-ND | DigiKey | ERJ-2RKF1302X | 0402 | http://www.digikey.com/product-search/en?keywords=P13.0KLCT-ND
49.9 | R23, R24, R25, R26 | .0026 | 4 | Panasonic | P49.9LCT-ND | Digi-Key | ERJ-2RKF49R9X | 0402 | http://www.digikey.com/product-search/en?keywords=P49.9LCT-ND
75/1%/.125W | R27, R28, R33, R34 | .0026 | 4 | Panasonic | P75.0LCT-ND | Digi-Key | ERJ-2RKF75R0X | 0402 | http://www.digikey.com/product-search/en?keywords=P75.0LCT-ND
100 | R29, R30, R31, R32 | .1 | 4 | Panasonic | P100LCT-ND | Digi-Key | ERJ-2RKF1000X | 0402 | http://www.digikey.com/product-search/en?keywords=P100LCT-ND
12.1k | R37 | .1 | 1 | Panasonic | P12.1KLCT-ND | Digi-Key | ERJ-2RKF1212X | 0402 | http://www.digikey.com/product-search/en?keywords=P12.1KLCT-ND
6.2 | R41, R49, R57, R64, R75, R82, R88, R94, R103, R110 | .05 | 10 | Vishay Dale | 541-6.20LLCT-ND | Digi-Key | CRCW04026R20FKED | 0402
470/1%/.250W | R45, R53, R61, R72, R78, R85, R90, R96, R106, R112 | .02 | 10 | Vishay/Draloric | 71-SMM0204-F-470 | Mouser | SMM02040C4700FB300 | 1206
1M | R46 | .0027 | 1 | Panasonic | P1.00MLTR-ND | Digi-Key | ERJ-2RKF1004X | 0402 | http://www.digikey.com/product-search/en?keywords=P1.00MLTR-ND
Wago-2060 | TB1-1, TB1-2 |  | 2 | Wago | 2059-301/998-403 |  | 2059-301/998-403, 2102477 |  | https://eshop.wago.com/JPBC/0_5StartPage.jsp;jsessionid=765159348460A4FDB6DFF08CE911289B?zone=6
Pulse Transformer | TrET1 | 4.0 | 1 | Pulse Electronic Corporation | HX1224CNL-ND | DigiKey | HX1224CNL |  | http://www.digikey.com/product-search/en?keywords=MP2403DN-LF-Z-ND
MP1470 | U2 | 0.65 | 1 | MPS Inc | MP1470GJ-Z | Avnet | MP1470GJ-P | TSOT-23-6 | http://www.digikey.com/product-search/en?keywords=1589-1018-1-ND
LAN8720 | U3 | .76 | 1 | Microchip | LAN8720A-CP-CT-ND | Digi-key | LAN8720A-CP-TR | 24 QFN | http://www.digikey.com/product-search/en?keywords=LAN8720A-CP-CT-ND
STPM34 | U4, U6, U8, U9, U10 | 1.0 | 5 | STMicroelectronics | 2435572 | farnel | STPM34TR |  | http://www.digikey.com/product-search/en?keywords=497-14670-1-ND
PIC32MX795F512H | U5 | 5.16 | 1 | Microchip | 1778989 | Farnel | PIC32MX795F512H-80I/PT | TQFP64N | http://bg.farnell.com/microchip/pic32mx795f512h-80i-pt/mcu-32bit-pic32-80mhz-tqfp-64/dp/1778989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|pcrid|93205780756|kword|pic32mx795f512h%2080i%20pt|match|p|plid
NUD3112D | U11, U12, U13, U14, U15 | 0.227 | 5 | On Semi | NUD3112DMT1GOSCT-ND | Digikey | NUD3112DMT1G
W25Q16DVPIG | U7 | 0.44 | 1 | Microchip | W25Q16DVZPIG | DigiKey | 23LCV1024-I/SN | 8-SOIC | http:/Winbond.com (http://www.digikey.com/product-search/en?keywords=23LCV1024-I%2FSN-ND)
25MHz | Y1 | 0.2 | 1 | KDS DAISHINKU.Corp | DSX321SH-25MHz | KDS DAISHINKU.Corp | DSX321SH-25MHz |  | www.kds.info/product
CB-3 Oscillator | Y2 | 1.0 | 1 | CTS Electronics Component | CTX947LVCT-ND | DigiKey | CB 3 LV-31-16M000 |  | http://www.digikey.com/product-search/en?keywords=CTX947LVCT-ND
8MHz | Y3 | 0.2 | 1 | KDS DAISHINKU.Corp | DSX321G-8MHz | KDS DAISHINKU.Corp | DSX321G-8MHz |  | www.kds.info/product
NL17SZ125 | U16, U17, U18, U19, U20 | 0.068 | 5 | ON Semi | NL17SZ125DTT1GOSCT-ND , NL17SZ125DTT1GOSCT-ND , NL17SZ125DTT1GOSCT-ND , NL17SZ125DTT1GOSCT-ND, NL17SZ125DTT1GOSCT-ND | Digikey | NL17SZ125DTT1G |  | http://www.digikey.bg/product-detail/en/on-semiconductor/NL17SZ125DTT1G/NL17SZ125DTT1GOSCT-ND/3487613
12pF/6.3V | C42, C47 | 0.02 | 2 | Murata | 490-8170-1-ND | DigiKey | GRM1555C1E120JA01D | 0402
Header 5X2 | P5 | 3.0 | 1 | Samtec Inc | SAM8798-ND | Digikey | FTSH-105-01-L-D-K
Header2x5(.050") | female cable two 2x5 headers with 5-wires cable 18cm |  | 1 | Samtec Inc | SAM8219-ND | Digikey | FTSD-05-D-12.00-01-N

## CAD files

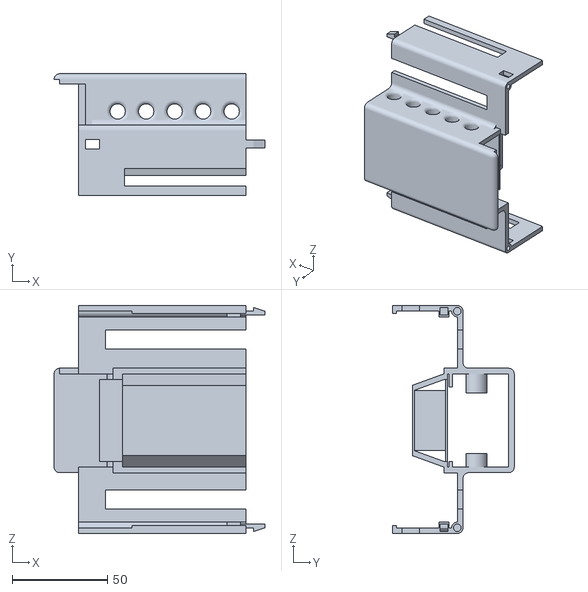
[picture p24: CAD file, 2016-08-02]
housing/v0.3 - prototype/Part2.STL
111.0 x 64.0 x 120.0

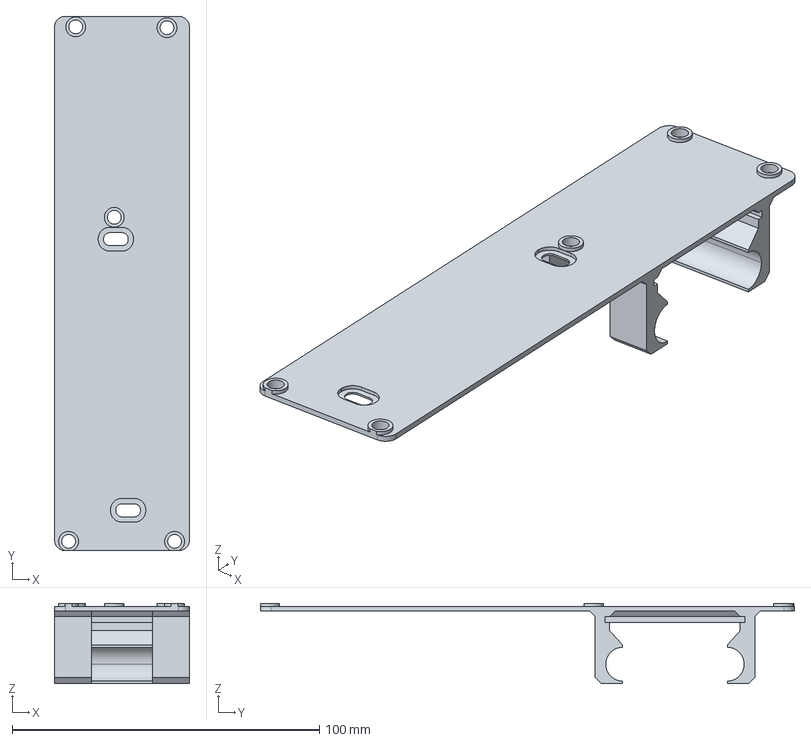
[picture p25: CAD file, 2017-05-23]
housing/v0.4 - prototype 2/SmartM Additional Fixture.step
44.0 x 174.0 x 26.1 mm

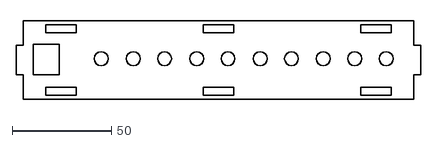
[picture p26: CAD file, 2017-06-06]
housing/v0.4a - Lasercut/3.dxf
203.3 x 39.3

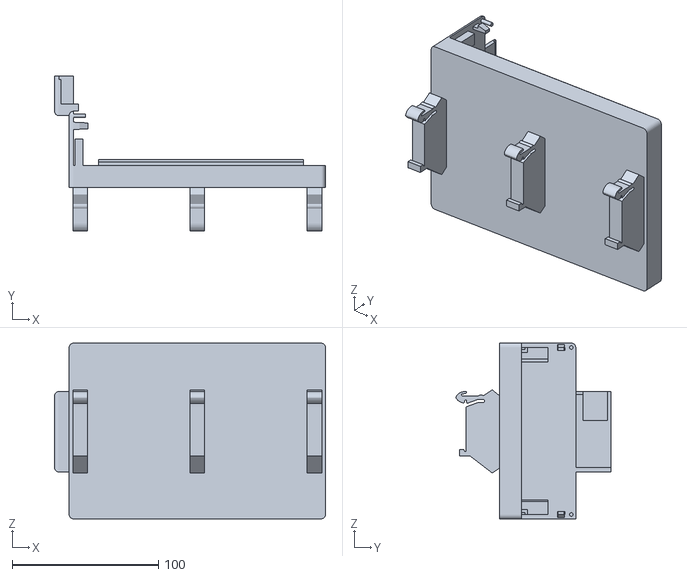
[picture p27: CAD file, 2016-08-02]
housing/v0.3 - prototype/Part1.STL
185.0 x 105.7 x 120.0

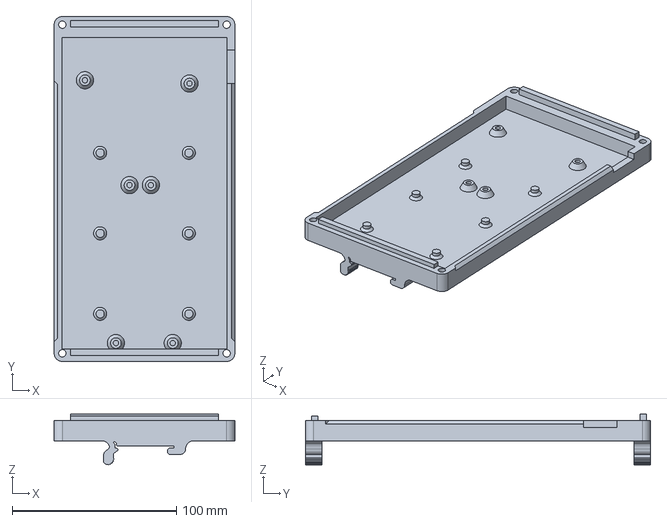
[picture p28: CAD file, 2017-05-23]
housing/v0.4 - prototype 2/SmartM Housing Bottom Plate.step
110.0 x 210.0 x 30.8 mm

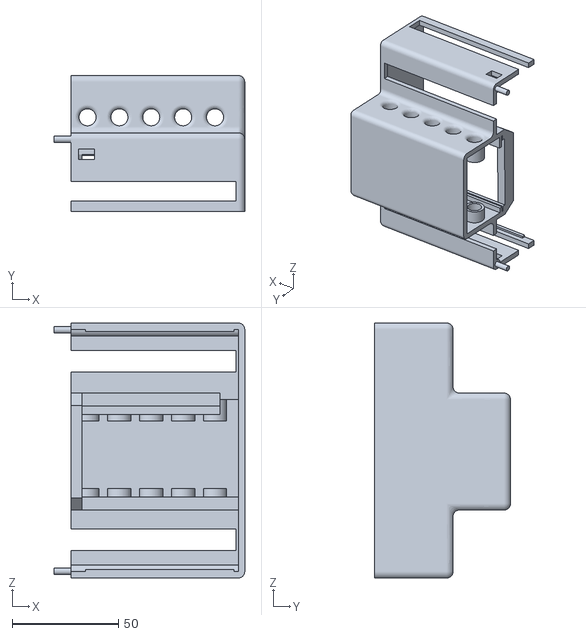
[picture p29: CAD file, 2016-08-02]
housing/v0.3 - prototype/Part3.STL
89.7 x 64.0 x 120.0

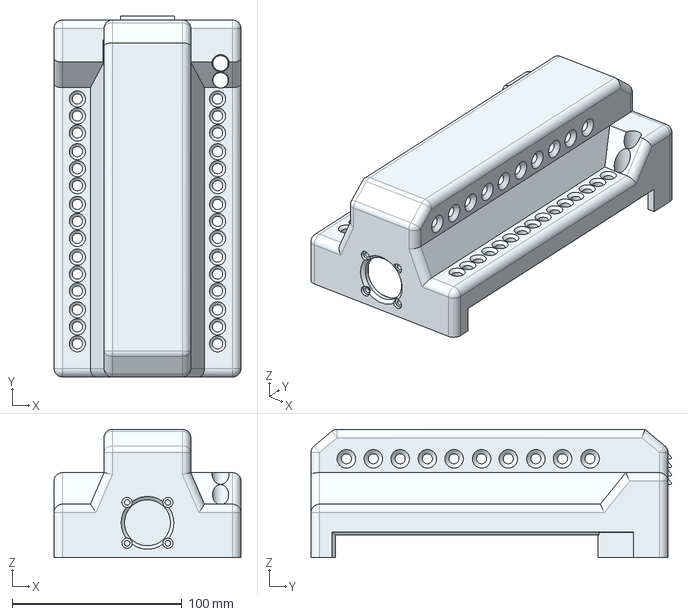
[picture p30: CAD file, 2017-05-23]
housing/v0.4 - prototype 2/SmartM Housing Cover.step
110.0 x 212.3 x 75.5 mm

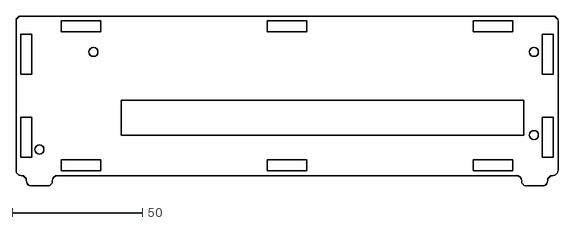
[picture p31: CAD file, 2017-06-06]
housing/v0.4a - Lasercut/9.dxf
208.3 x 65.3

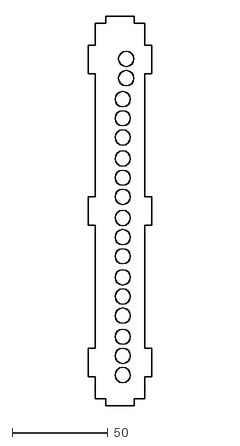
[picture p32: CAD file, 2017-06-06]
housing/v0.4a - Lasercut/4.dxf
33.1 x 203.3

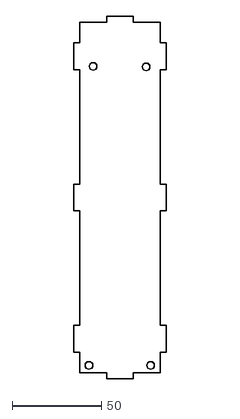
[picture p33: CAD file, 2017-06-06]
housing/v0.4a - Lasercut/1.dxf
51.9 x 203.3

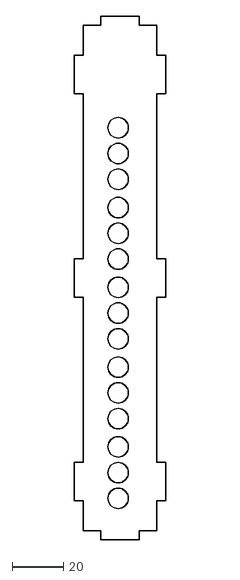
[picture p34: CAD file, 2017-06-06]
housing/v0.4a - Lasercut/5.dxf
35.7 x 203.3

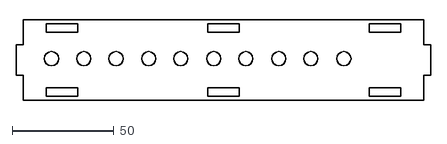
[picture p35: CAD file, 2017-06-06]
housing/v0.4a - Lasercut/2.dxf
203.3 x 39.3

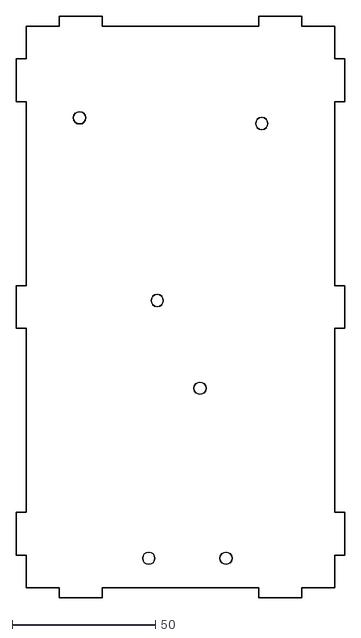
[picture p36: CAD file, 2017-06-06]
housing/v0.4a - Lasercut/8.dxf
114.7 x 203.3

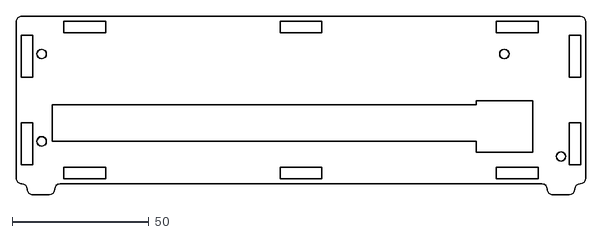
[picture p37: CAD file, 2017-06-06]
housing/v0.4a - Lasercut/10.dxf
208.3 x 65.3

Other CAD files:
housing/v0.4a - Lasercut/6.dxf
housing/v0.4 - prototype 2/SmartM Housing Bottom Plate_STL.stl
housing/v0.4a - Lasercut/7.dxf
housing/v0.3 - prototype/Part1.SLDDRW
housing/v0.3 - prototype/Part2.SLDDRW
housing/v0.3 - prototype/Part3.SLDDRW
housing/v0.4 - prototype 2/SmartM Additional Fixture.stl

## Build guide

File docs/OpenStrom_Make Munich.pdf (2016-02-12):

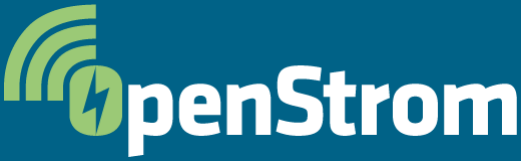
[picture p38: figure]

# The Open Hardware Smart Meter that powers the energy revolution

•••••••••

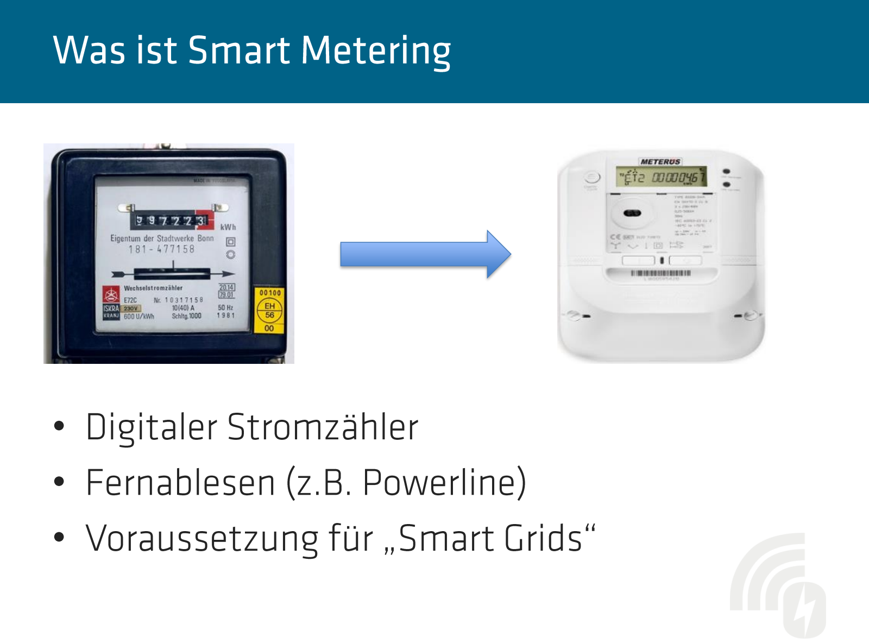
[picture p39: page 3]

•••

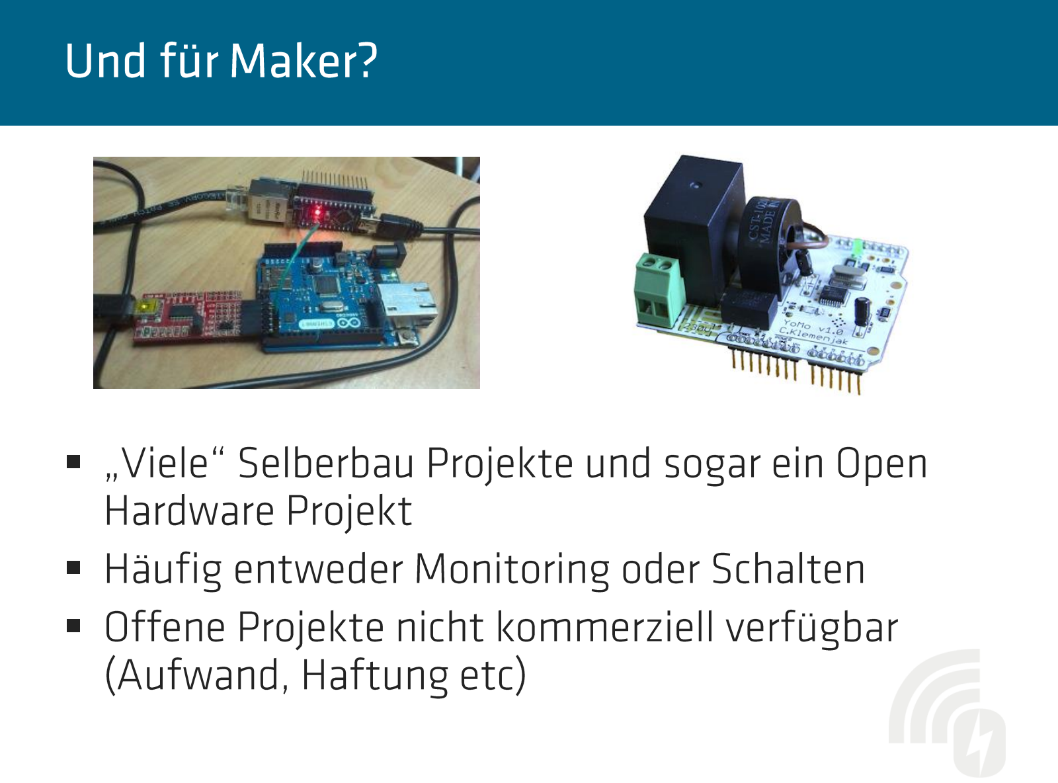
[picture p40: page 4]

▪▪▪

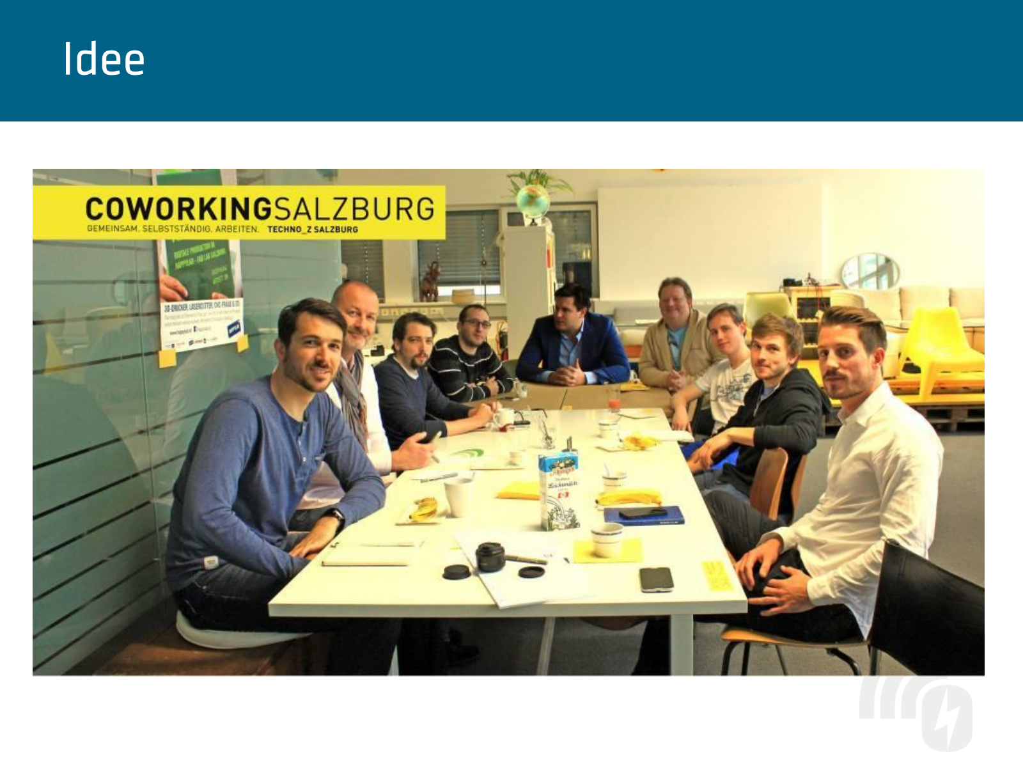
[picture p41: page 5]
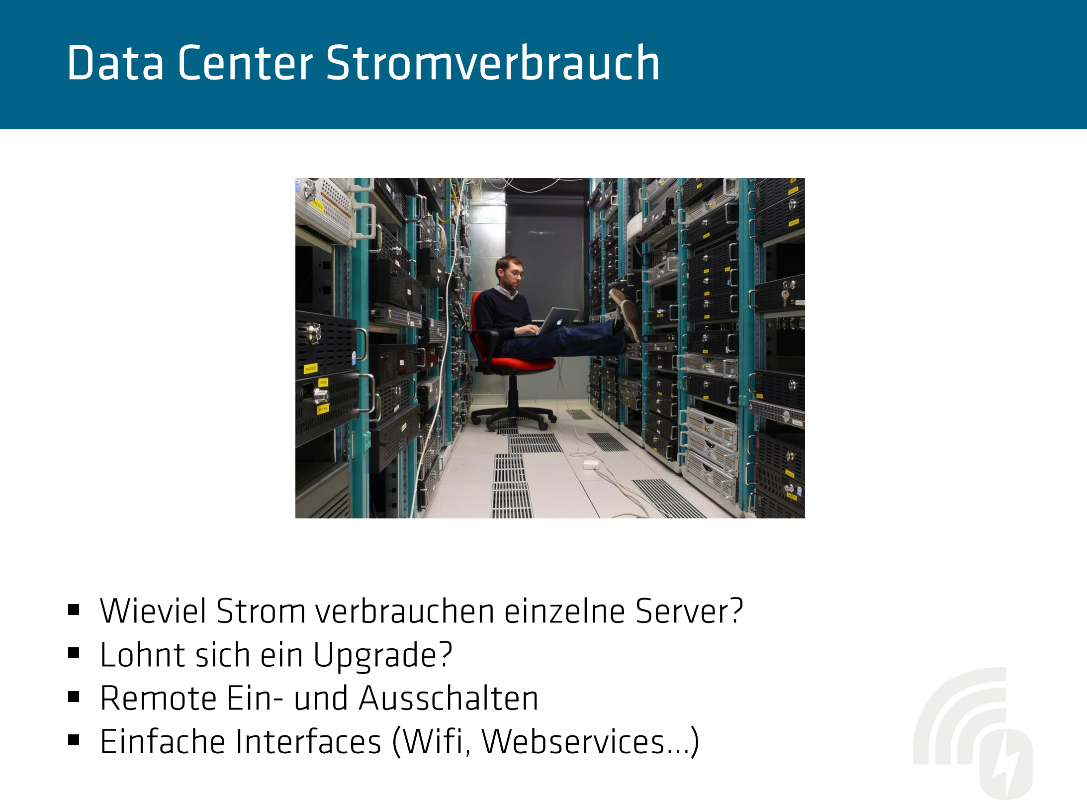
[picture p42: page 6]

▪▪▪▪

Komponente | Features
Microcontroller | Arduino?
Verbindungen | WiFi
Sensor | Schein- und Wirkleistung, Strom, Spannung, Leistungsfaktor hohe Sampling Frequenz (kHz) 220 V 16 A kHz Sampling
Relays (10x) | Schalten bis zu 16A / 250V
Gehäuse | Hutschiene
Temperatur | 0 - 85°C

▪▪▪▪▪▪

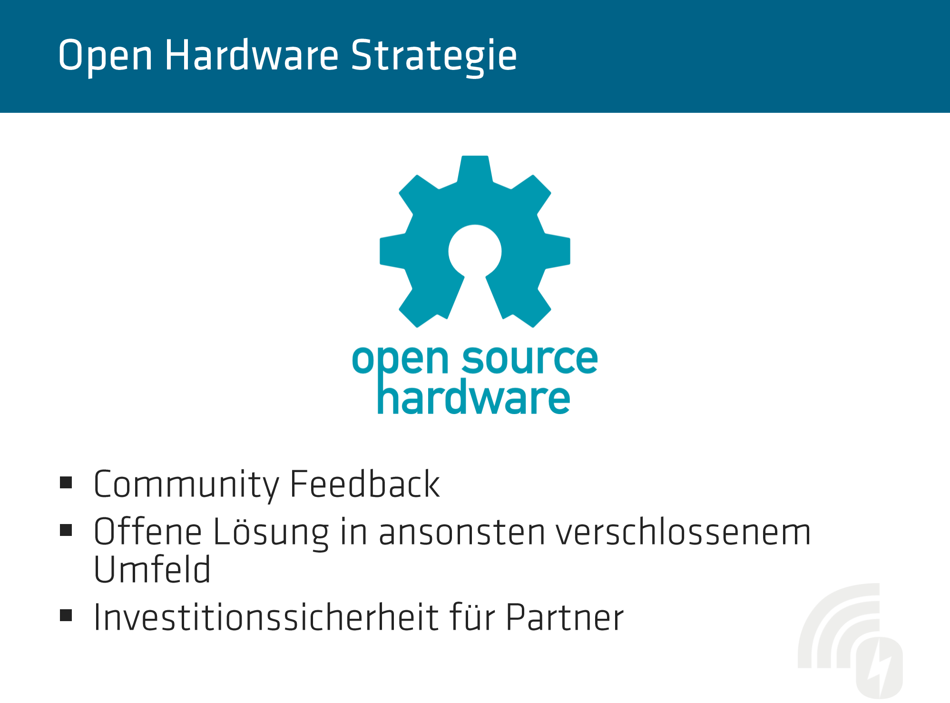
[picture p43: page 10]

▪▪▪

•••

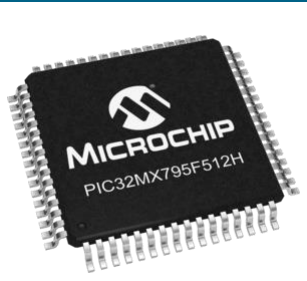
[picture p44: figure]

▪▪▪

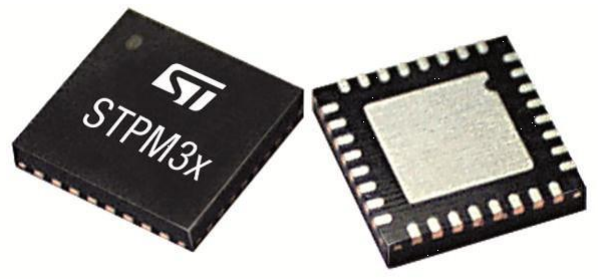
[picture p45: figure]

•••

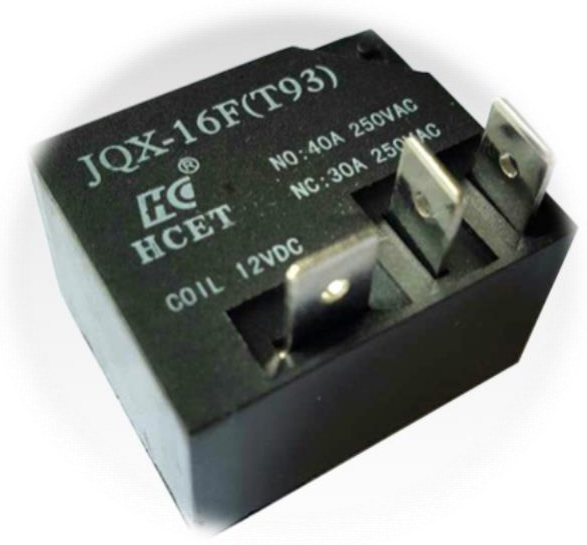
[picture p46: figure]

•••

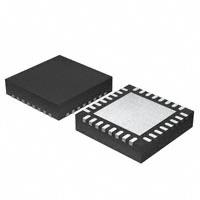
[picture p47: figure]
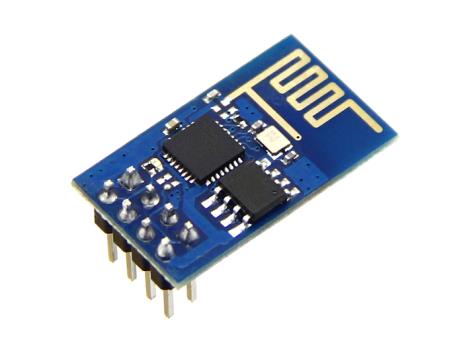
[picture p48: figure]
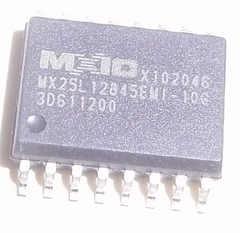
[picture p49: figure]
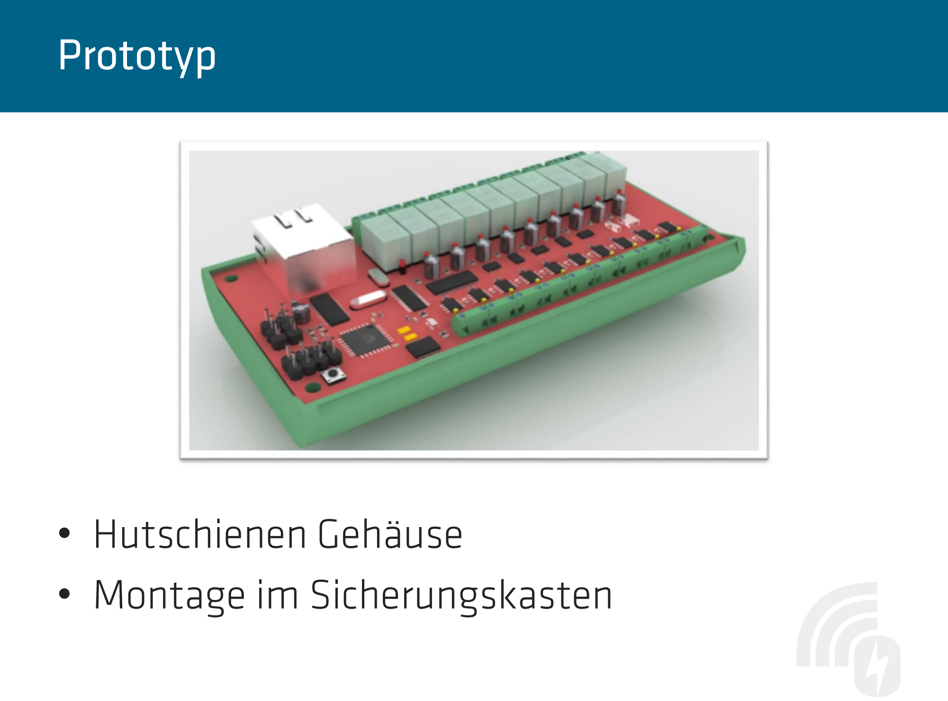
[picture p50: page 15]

••

# | Description | Manufacturer | Part Number | Package | Amount | Cost $ (@1000) Total

1 | PIC32MX512 microcontroler | Microchip | PIC32MX795F512H | 64QFN | 1 | $6,68 | $6,68
2 | Energy IC STPM34 | ST Microelectronics | SSTPM34TR | 32 QFN | 5 | $1,13 | $5,65
3 | WiFi IC ESP8266 | Shenzhen Guangshun Electronic Business | ESP 8266 | | 1 | $2,34 | $2,34
4 | PHY IC LAN 8720 | Microchip | LAN 8720 | 24 QNF | 1 | $0,95 | $0,95
5 | ZigBee IC AT86RF233 | ATMEL | AT86RF233 | 32 QN2 | 1 | $3,39 | $3,39
6 | Serial RAM 128 MB | macronix International Ltd | MX25L12845EMI-10G | 8-WSON | 1 | $1,82 | $1,82
8 | Terminal Blocks | Shenzhen Sced Electronics Co Ltd | TB13000-00-C | | 10 | $0,25 | $2,50
9 | Ethernet Transformer | BEL | S558-5999 | | 1 | $1,27 | $1,27
10 | Power Supply IC | ON Semi | LM2575 | 5 Lead TO-220 | 2 | $0,90 | $1,80
11 | Crystal oscillator 40Mhz | China manfufacturer | HC-49S | | 2 | $0,25 | $0,50
12 | JQX-16F relay 250VAC/40A | Yueqing HengweiElectronics Co.,Ltd | JQX-16F(T91) | | 1 | $0,32 | $0,32
13 | RJ-45 8px8c modulare jack | China manufacturer | P88RE50V2GN | | 1 | $0,25 | $0,25
14 | Optocouplers 4N25 | Vishay China analog | 4N25 | DIL-6 | 10 | $0,02 | $0,20
15 | Transistors NPN | Fairchild | MMBT2222 | | 10 | $0,02 | $0,20
16 | PCB | TBD | | single side | 1 | $3,00 | $3,00
17 | Custom Housing | TBD | | | 1 | $5,00 | $5,00
19 | Battery plus Holder? | MPD | BC501SM | | 1 | $0,50 | $0,50
20 | Power Switch | ningbo | MTS 101 | miniature toggle switch | 1 | $0,18 | $0,18
21 | LED | longhua | quarter watt led blue color
22 | Current transformer | Coilcraft | CST2010 | custom SMD | 10 | $.9 | $9,00
24 | Filter-Bulon2450FB1 | Johanson | AS222-92 | custom SMD | 1 | $0.5 | $0,50
25 | RF-SwitchAS222-92 | Skyworks Solution | AS222-92 | custom SMD | 0.35 | $0.35 | $0,35

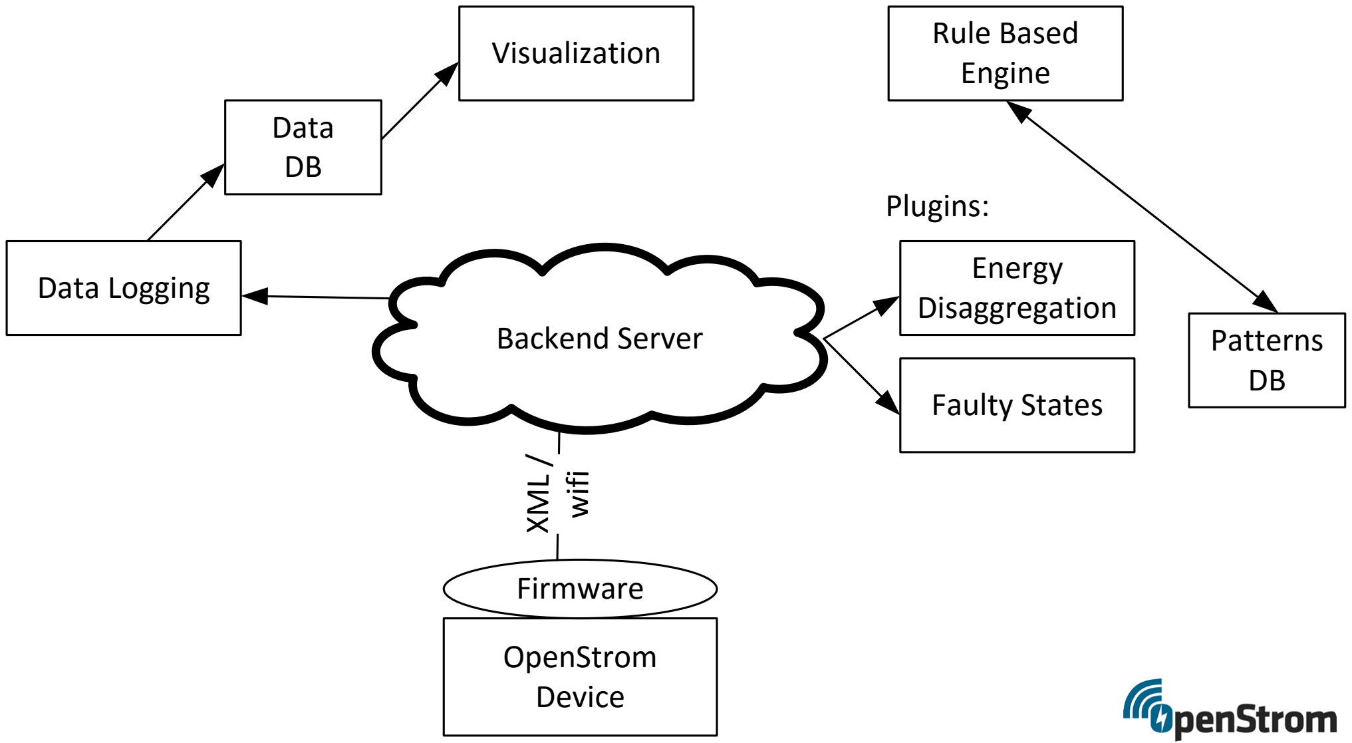
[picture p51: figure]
OpenStrom Device; Firmware; Backend Server Data Logging; Visualization; Data DB; XML / wifi; Plugins:; Rule Based Engine

Energy Disaggregation Faulty States | Patterns DB

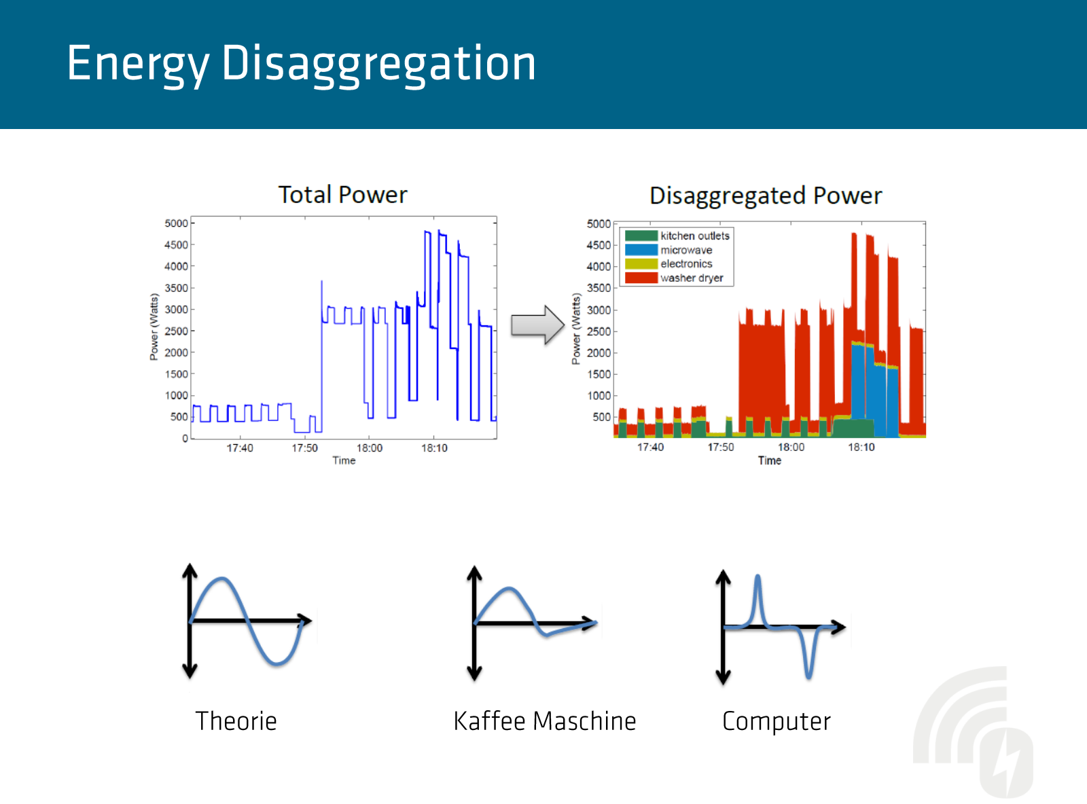
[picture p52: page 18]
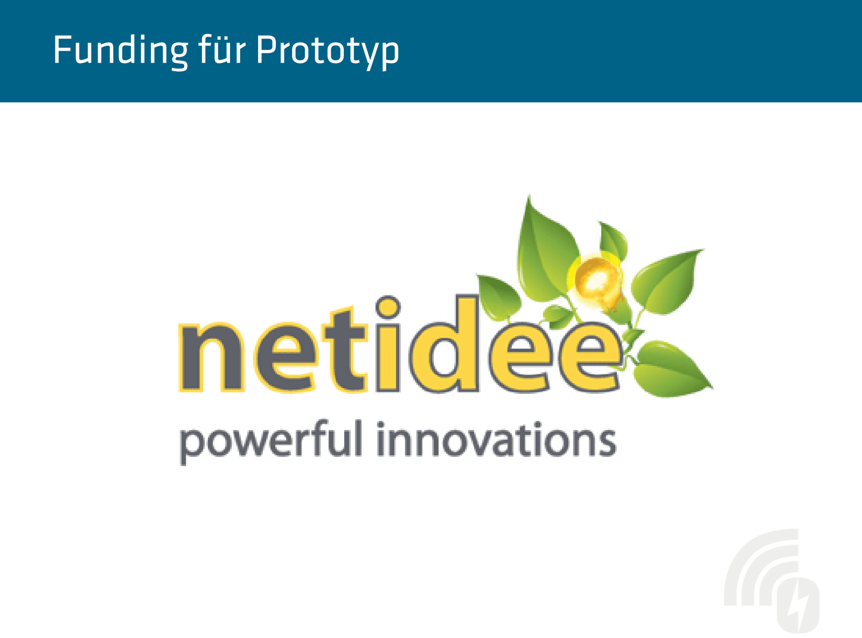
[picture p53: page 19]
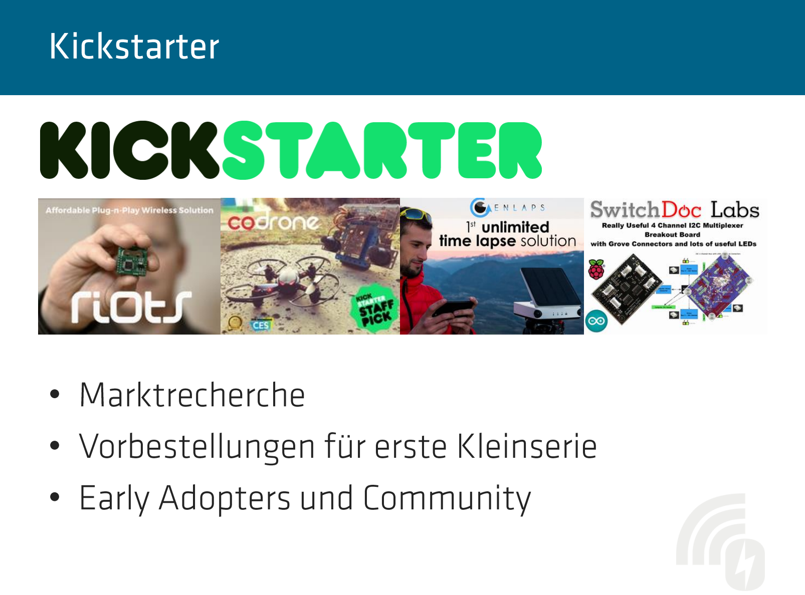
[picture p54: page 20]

•••

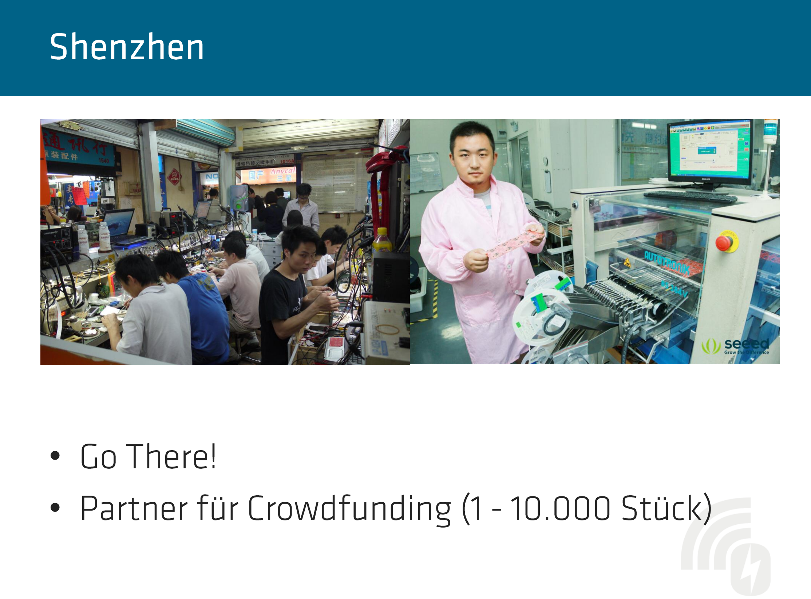
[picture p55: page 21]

••

••••••

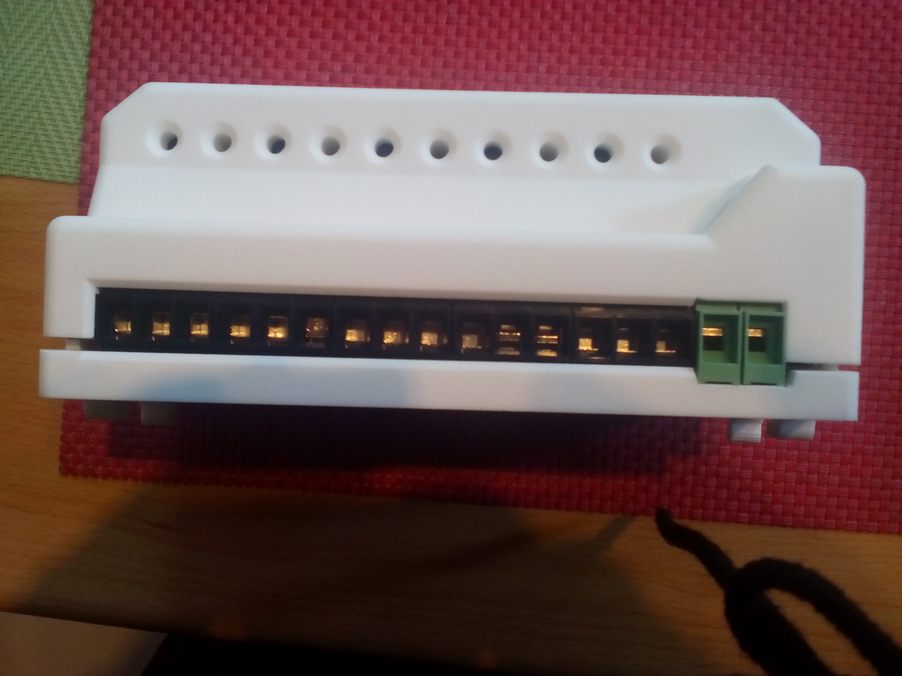
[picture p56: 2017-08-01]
housing/v0.4 - prototype 2/assembled/2017-06-19 11.57.15.jpg

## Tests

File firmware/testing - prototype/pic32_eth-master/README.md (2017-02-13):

# eth_pic32
An ethernet MAC and PHY layer for PIC32.
This demo project runs over PIC32 Ethernet Starter Kit and has been tested with an Ubuntu laptop through an Ethernet switch.

The demo application just sends a frame with a fixed message. You can use a sniffing tool like Wireshark. 
ATTENTION: set MAC address of your PC as destination MAC address and check the sent frame with a tool like Wireshark.

For an example of use please have a look at minUDP or minIP projects.

Known issues:
 - Ethernet layer remains stacked until an Ethernet cable is connected. It is necessary to add a timeout in order to exit the related infinite loop in eth.c file.

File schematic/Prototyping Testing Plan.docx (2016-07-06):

Prototyping Testing Plan

Project: Open Strom Smart Meter

Object: CPU Board PCB

## 1.1. Introduction and Project Overview

### 1.1.1. The goal of Open Strom Smart Mete project is to develop the necessary hardware and software for acquisition ,monitoring and disaggregation estimation of the energy parameters for electrical home and business appliances

## 1.2. Project Sub-Systems Being Tested

### 1.2.1. Figure 1.1 is a high level block diagram showing all of the components that need to be tested.

Battery Charger

Power Supply

5.0V, 3.3V

Current/Voltage Sensor

STPM 34

Ch1

Relay Switch

Ch1

SPI

Main Microcontroller

PIC 32MX975F512H

SPI

Current/Voltage Sensor

STPM 34

Ch10

Relay Switch

Ch10

Tx,Rx

MMI

SPI

Ethernet

Circuit

LAN 8720

WiFi Module

ESP 8266 WROOM

ZigBee Module

MRF24J40MA

Fig .11

## 1.3. Test Strategy

### 1.3.1. . Table 1.1 is an abbreviated version of the specifications that will be filled in as tests are carried out.

Engr. Spec. # | Specification (description) | Pass criteria | Units | Measured | Pass/Fail
Hardware
Test1 | Power Supply 5.0V | ±0.5% | Volt
Test2 | Power Supply 3.3v | ±0.05% | Volt
Test3 | PIC32MX759F512H | works
Test4 | RelaySwith1-10 | Switch On/Off | Volt | 4.75V-5.25v
Test5 | SPI2 BUS Sensors | works
Test6 | SPI3 BUS ZigBee | works
Test7 | Current Sensors 1-10 | works | Volt | ±0-300mV
Test8 | Voltage Sensor 1-10 | works | Volt | ±0-300mV
Test9 | STPM34 | works
Test10 | Ethernet | works

Table 1.1: Specification test sheet

## 1.3.2 Prototype reference documents

The prototype is real PCB named SM-CPU board Rev.0.3 with the following reference documents:

- Schematics – CPU-board-Sheet1-multi.schDoc;

-CPU-board-Sheet2-multi.schDoc;

-CPU-board-Sheet1-multi.schDoc;

-BOM – BOM-CPU-board-multi.xls;

### 1.3.3. Equipment required for testing follows:

### Oscilloscope with probes 100MHZ two channels;

- Voltage Digital Multimeter 6 Digit;

### DC Voltage supply 12V/ 3Amps;

### DC Current supply 1- 20mAmps;

### ICD -3 debugger/programmer;

### PicKit2-programmer (optional);

## 1.3. Steps of testing

### 1.4.1. Power Supply test step 5.0V - Test1

      1.4.1.1 Power Supply – 5.0V (PS5.0V)

Populate components that build the PS5.0V – see List of components

1.4.1.2. List of components

- Terminal Block – TB1-1, TB1-2, P1,P2,P3;

- IC – U1;

- Capacitors – C1, C2, C3, C4, C5, C6;

- Resistors – R1, R2, R5, R6, R8;

- Inductor – L1;

- Diodes – D1, D2;

- Solder components to the board

Connect external PS 12V/3Amps to the terminals TB1-1, TB1-2 .

1.4.1.3 Measurement of PS5.0V

- use TP1 -5.0V located on the header P2-21 and GND located on the P1-5

- the measured voltage should be in the rate of +5.25V- 4.75V;

- D3 should light up;

1.4.1.4. Measurement PS5.0V under a load

- between P1-2 and P1-5 connect load resistor 5 Ohms/5W;

- The measured value of PC5.0V should be in the range of 4.75V – 5.0V;

- D3 should light up;

-mark in the Table 1.1 that Test1 was passed;

1.4.2 . Power Supply test step 3.3V – Test 2

Populate components that build the PS3.3V – see List of components

1.4.2.1. List of components

- IC – U1;

- Capacitors – C8, C9, C7, C10;

- Resistors – R14, R17, R18, R19, R20;

- Inductor – L2;

- Diode- D5, D7;

1.4.2.2. Measurement of PS3.3V

- use TP2 3.3V on the header P1-1;

- use GND on the header P1-5;

- measure voltage between TP2 and GND;

- the measured value should be in the range 2.8V - 3.4V ;

1.4.2.3. Measurement of the PS3.3V under a load

- between P1-1 and P1-5 connect load resistor 5 Ohms/5W

- the measured value should be in the rate of 2.8V – 3.4V ;

- D7 should light up;

-mark in the Table 1.1 that Test2 was passed

1.5. Microcontroller pic32mx795F512H test step – Test 3

1.5.1. Populate all of the components to the PCB without Wifi Module M2

1.5.2. Check power supply of microcontroller pic32mx

- between microcontroller (uC) GND’s pins 9,25,41 and Vdd’s pins 26,38,10,57 the voltage should be in the range 2.8V -3.4V;

1.5.3. Download TestCPU01.hex file

- connect ICD 3 debugger or PicKit2 to header P1.

- download the hex file TestCPU01.hex file;

- switch on/off power supply 12V to activate RESET-START ;

- measure frequency in TP6 and TP6 using 100Mhz oscilloscope;

- the rate of frequency should be 8MHZ +/- 2%;

- the LEDs D14,D15 should light alternatively with delay of 500ms;

-mark in the Table 1.1 that Test3 was passed

1.6. Relays test step – Test 4

1.6.1. Download the testRelays01.hex file by ICD-3 debugger

- switch on/off power supply 12V to activate RESET-START ;

- use the oscilloscope to measure the state on the header pins P2-2,

P2-4, P2-6, P2-8, P2-10, P2-12, P2-14, P2-16, P2-16, P2-20;

- the state on these pins should change alternately between 0.4v to 3.2V with the frequency of 10Hz.

1.7. SPI-2 bus sensor test step – Test5

1.7.1. Download the testSPI02.hex file by ICD-3 debugger

- switch on/off power supply 12V to activate RESET-START ;

- use the oscilloscope to view SPI signals as follows:

- TP7 - SCS;

- TP8 – SCL;

- TP9 – MOSI;

-TP10 – MISO;

1.7.2. The oscilloscope waveform should looks like as in the attached files:

- ;

- ;

1.7.2.1. If the real oscilloscope picture corresponds to the waveform in the files

Mark in Table 1.1 that the test was passed

1.8. SPI-3 bus Zegbee test step – Test6

1.8.1. Download the testSPI03.hex file by ICD-3 debugger

- switch on/off power supply 12V to activate RESET-START ;

- use the oscilloscope to view SPI signals as follows:

- TP11 SDO3;

- TP15 – SDI 3;

- TP14 – SCLK;

- TP17 – CS;

- TP12 – RESET;

1.8.2.1. If the real oscilloscope picture corresponds to the waveform in the files

Mark in Table 1.1 that the test was passed

1.9. Current measurement test step – Test 7

1.9.1. Connect DC current supply 1-20mA to the CPU board as follows:

- DC Current Supply active output to the P3-1;

- DC Power Supply GND to the P3-11/12/13;

- List of the test point (see the schematic document CPU-board-Sheet2-multi.SchDoc and CPU-board-Sheet3-multi.SchDoc :

- for Channel 1/2 :TP18 – U4-11; TP19 – U4-9; TP20 - U4-13; TP21- U4 -11;

- for Channel 3/4 :TP22 – U6-11; TP23 – U6-9; TP24 - U6-13; TP25- U6 -11;

- for Channel 5/6 :TP26 – U8-11; TP27 – U8-9; TP28 - U8-13; TP29- U8 -11;

- for Channel 7/8 :TP30 – U9-11; TP31 – U9-9; TP32 - U9-13; TP33- U9 -11;

- for Channel 9/10 :TP34 – U10-11; TP35 – U10-9; TP36 - U10-13;

TP37- U10 -11;

1.9.1.1. Apply the input current from the DC current Supply as is shown in

Table 2.1 and measure the voltage at the TP18

DC Current Value(adjustable) active output | Voltage value at TP18 (mV+-2%)
0 mA | 0 mV +/- 2%
40 uA | 7.48mV +/- 2%
2 mA | 37.4mV +/- 2%
4 mA | 74.8mV +/- 2%
6 mA | 112.2 mV +/- 2%
8 mA | 149.6 mV +/- 2%
10 mA | 187 mV +/- 2%
12 mA | 224.4mV +/- 2%
14 mA | 261.8 mV +/- 2%
16 mA | 299.2 mV +/- 2%

Table 1.2

1.9.1.2. Connect DC current supply 1-20mA to the CPU board as follows:

- DC Current Supply active output to the P3-2;

- DC Power Supply GND to the P3-11/12/13;

1.9.1.2.1 Apply the input current from the DC current Supply as is shown in

Table 1.2 and measure the voltage at the TP20

1.9.1.3. Connect DC current supply 1-20mA to the CPU board as follows:

- DC Current Supply active output to the P3-3;

- DC Power Supply GND to the P3-11/12/13;

1.9.1.3.1 Apply the input current from the DC current Supply as is shown in

Table 1.2 and measure the voltage at the TP22

1.9.1.4. Connect DC current supply 1-20mA to the CPU board as follows:

- DC Current Supply active output to the P3-4;

- DC Power Supply GND to the P3-11/12/13;

1.9.1.4.1 Apply the input current from the DC current Supply as is shown in

Table 1.2 and measure the voltage at the TP24

1.9.1.5. Connect DC current supply 1-20mA to the CPU board as follows:

- DC Current Supply active output to the P3-5;

- DC Power Supply GND to the P3-11/12/13;

1.9.1.5.1 Apply the input current from the DC current Supply as is shown in

Table 1.2 and measure the voltage at the TP26

1.9.1.6. Connect DC current supply 1-20mA to the CPU board as follows:

- DC Current Supply active output to the P3-6;

- DC Power Supply GND to the P3-11/12/13;

1.9.1.6.1 Apply the input current from the DC current Supply as is shown in

Table 1.2 and measure the voltage at the TP28

1.9.1.7. Connect DC current supply 1-20mA to the CPU board as follows:

- DC Current Supply active output to the P3-7;

- DC Power Supply GND to the P3-11/12/13;

1.9.1.7.1 Apply the input current from the DC current Supply as is shown in

Table 1.2 and measure the voltage at the TP30

1.9.1.8. Connect DC current supply 1-20mA to the CPU board as follows:

- DC Current Supply active output to the P3-8;

- DC Power Supply GND to the P3-11/12/13;

1.9.1.8.1 Apply the input current from the DC current Supply as is shown in

Table 1.2 and measure the voltage at the TP32

1.9.1.9. Connect DC current supply 1-20mA to the CPU board as follows:

- DC Current Supply active output to the P3-9;

- DC Power Supply GND to the P3-11/12/13;

1.9.1.9.1 Apply the input current from the DC current Supply as is shown in

Table 1.2 and measure the voltage at the TP34

1.9.1.10. Connect DC current supply 1-20mA to the CPU board as follows:

- DC Current Supply active output to the P3-10;

- DC Power Supply GND to the P3-11/12/13;

1.9.10.1 Apply the input current from the DC current Supply as is shown in

Table 1.2 and measure the voltage at the TP36

1.10. Voltage measure test step – Test 8

1.10.1. Connect DC voltage supply to the CPU board as follows:

- DC Voltage Supply active output to the P2-1;

- DC Power Supply GND to the P3-11/12/13;

1.10.1.1. Apply the input voltage from the DC voltage Supply as is shown in

Table 2.1 and measure the voltage at the TP18

Table 2.1

DC Voltage Value(adjustable) active output | Voltage value at TP19 (mV+-2%)
0 mV | 0 mV +/- 2%
116mV | 116mV +/- 2%
121mV | 121mV +/- 2%
127mV | 127mV +/- 2%
133mV | 133 mV +/- 2%
139mV | 139 mV +/- 2%
145mV | 145 mV +/- 2%

1.10.2. Connect DC voltage supply to the CPU board as follows:

- DC Current Supply active output to the P2-3;

- DC Power Supply GND to the P3-11/12/13;

1.10.2.1. Apply the input current from the DC current Supply as is shown in

Table 2.1 and measure the voltage at the TP21

1.10.3. Connect DC voltage supply to the CPU board as follows:

- DC Current Supply active output to the P2-5;

- DC Power Supply GND to the P3-11/12/13;

1.10.3.1. Apply the input current from the DC current Supply as is shown in

Table 2.1 and measure the voltage at the TP23

1.10.4. Connect DC voltage supply to the CPU board as follows:

- DC Current Supply active output to the P2-7;

- DC Power Supply GND to the P3-11/12/13;

1.10.4.1. Apply the input current from the DC current Supply as is shown in

Table 2.1 and measure the voltage at the TP25

1.10.5. Connect DC voltage supply to the CPU board as follows:

- DC Current Supply active output to the P2-9;

- DC Power Supply GND to the P3-11/12/13;

1.10.5.1. Apply the input current from the DC current Supply as is shown in

Table 2.1 and measure the voltage at the TP27

1.10.6. Connect DC voltage supply to the CPU board as follows:

- DC Current Supply active output to the P2-11;

- DC Power Supply GND to the P3-11/12/13;

1.10.6.1. Apply the input current from the DC current Supply as is shown in

Table 2.1 and measure the voltage at the TP29

1.10.7. Connect DC voltage supply to the CPU board as follows:

- DC Current Supply active output to the P2-13;

- DC Power Supply GND to the P3-11/12/13;

1.10.7.1. Apply the input current from the DC current Supply as is shown in

Table 2.1 and measure the voltage at the TP31

1.10.8. Connect DC voltage supply to the CPU board as follows:

- DC Current Supply active output to the P2-15;

- DC Power Supply GND to the P3-11/12/13;

1.10.8.1. Apply the input current from the DC current Supply as is shown in

Table 2.1 and measure the voltage at the TP33

1.10.9. Connect DC voltage supply to the CPU board as follows:

- DC Current Supply active output to the P2-17;

- DC Power Supply GND to the P3-11/12/13;

1.10.9.1. Apply the input current from the DC current Supply as is shown in

Table 2.1 and measure the voltage at the TP35

1.10.10. Connect DC voltage supply to the CPU board as follows:

- DC Current Supply active output to the P2-19;

- DC Power Supply GND to the P3-11/12/13;

1.10.10.1. Apply the input current from the DC current Supply as is shown in

Table 2.1 and measure the voltage at the TP37

1.11. STPM 34 Test step - Test 8 (to be continued)

1.12. Ethernet test step – Test 9 (to be continued)

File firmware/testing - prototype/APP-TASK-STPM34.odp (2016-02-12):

## Smart meter firware structure

S34 State MachineTPM

Begin

Firware files for STPM34 application state machine

1. app-stpm34.h – header file for STMP34 task app

2. App-stpm34.c – source ile for STPM34 task app

3. STPM34-header.h -header file for IC STPM34

4. main-test.c – test file for SPI STPM34

APP_STPM34_Init

APP_STPM34_Read

SYS_INIT

Init Clock;

Init Sys-core;

Init IO;

Init STMP34

APP_STPM34_Idle

APP_STPM34_Error

Start Timer #1

IRQ Timer1

active

APP_STPM34_Crypto

1

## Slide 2

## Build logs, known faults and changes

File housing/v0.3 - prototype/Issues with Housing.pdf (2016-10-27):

# Issues with Housing

## V0.3 - Prototype

# Controller board

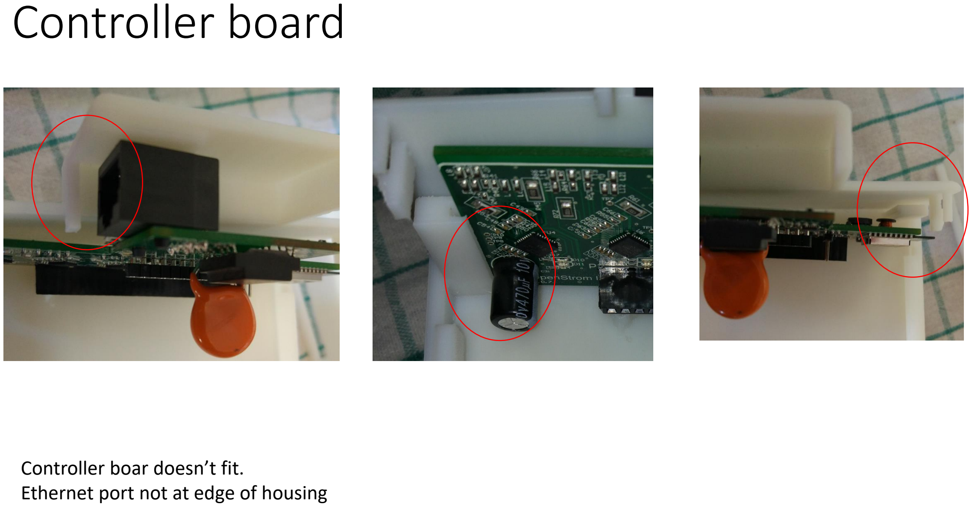
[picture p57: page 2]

Controller boar doesn’t fit.
Ethernet port not at edge of housing

# Relay Board

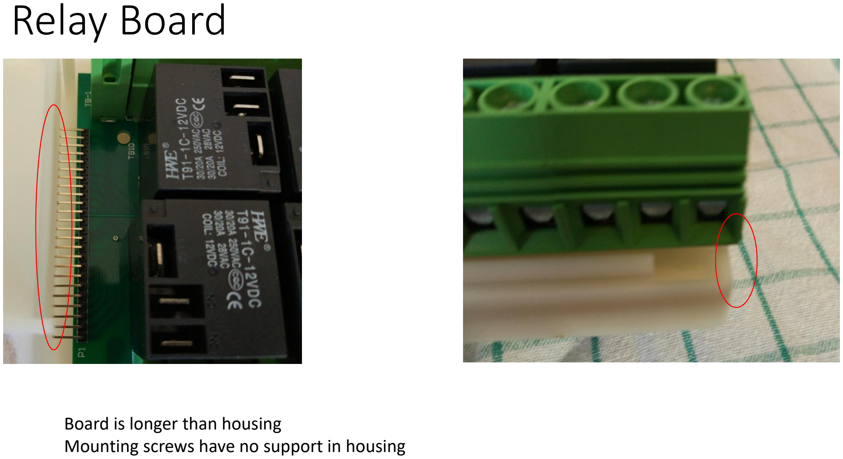
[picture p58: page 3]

Board is longer than housing
Mounting screws have no support in housing

# Transformer board

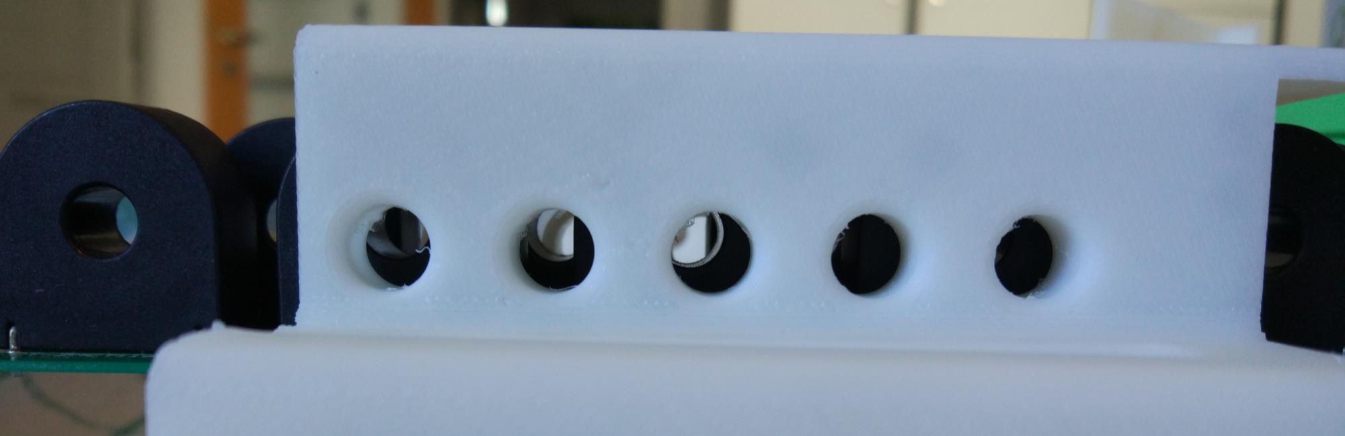
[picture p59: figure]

Holes do not align with transformers
Also board doesn’t fit into guide (board too thick, plus consider solder on underside)

# Battery & Zigbee

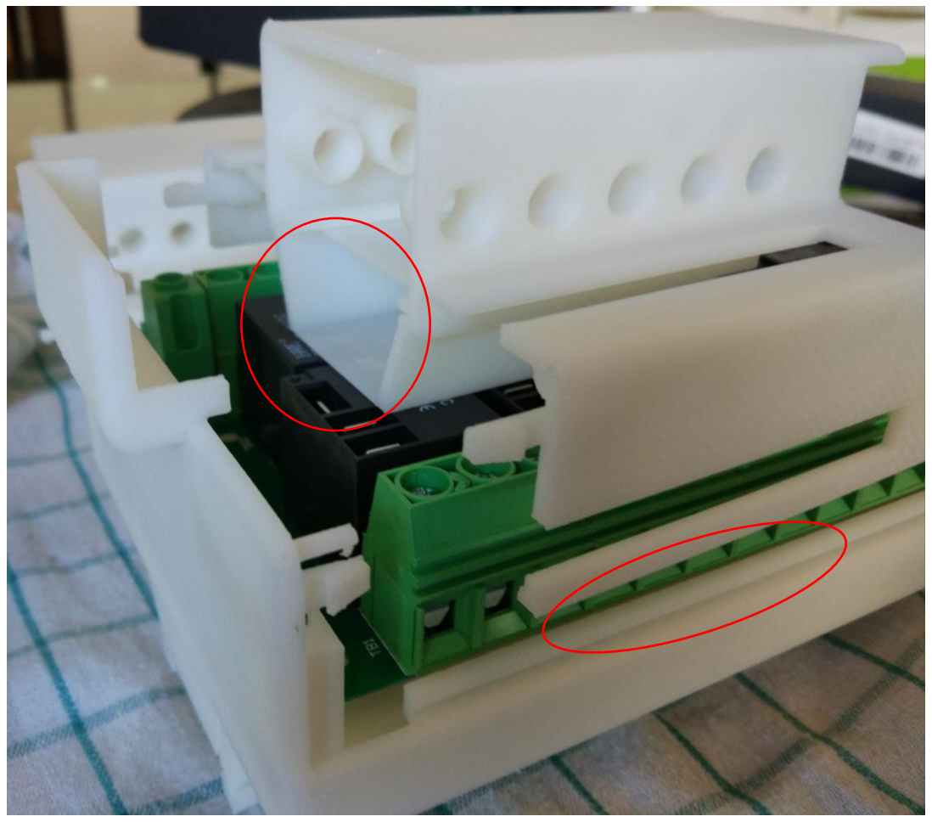
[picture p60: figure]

This doesn’t fit

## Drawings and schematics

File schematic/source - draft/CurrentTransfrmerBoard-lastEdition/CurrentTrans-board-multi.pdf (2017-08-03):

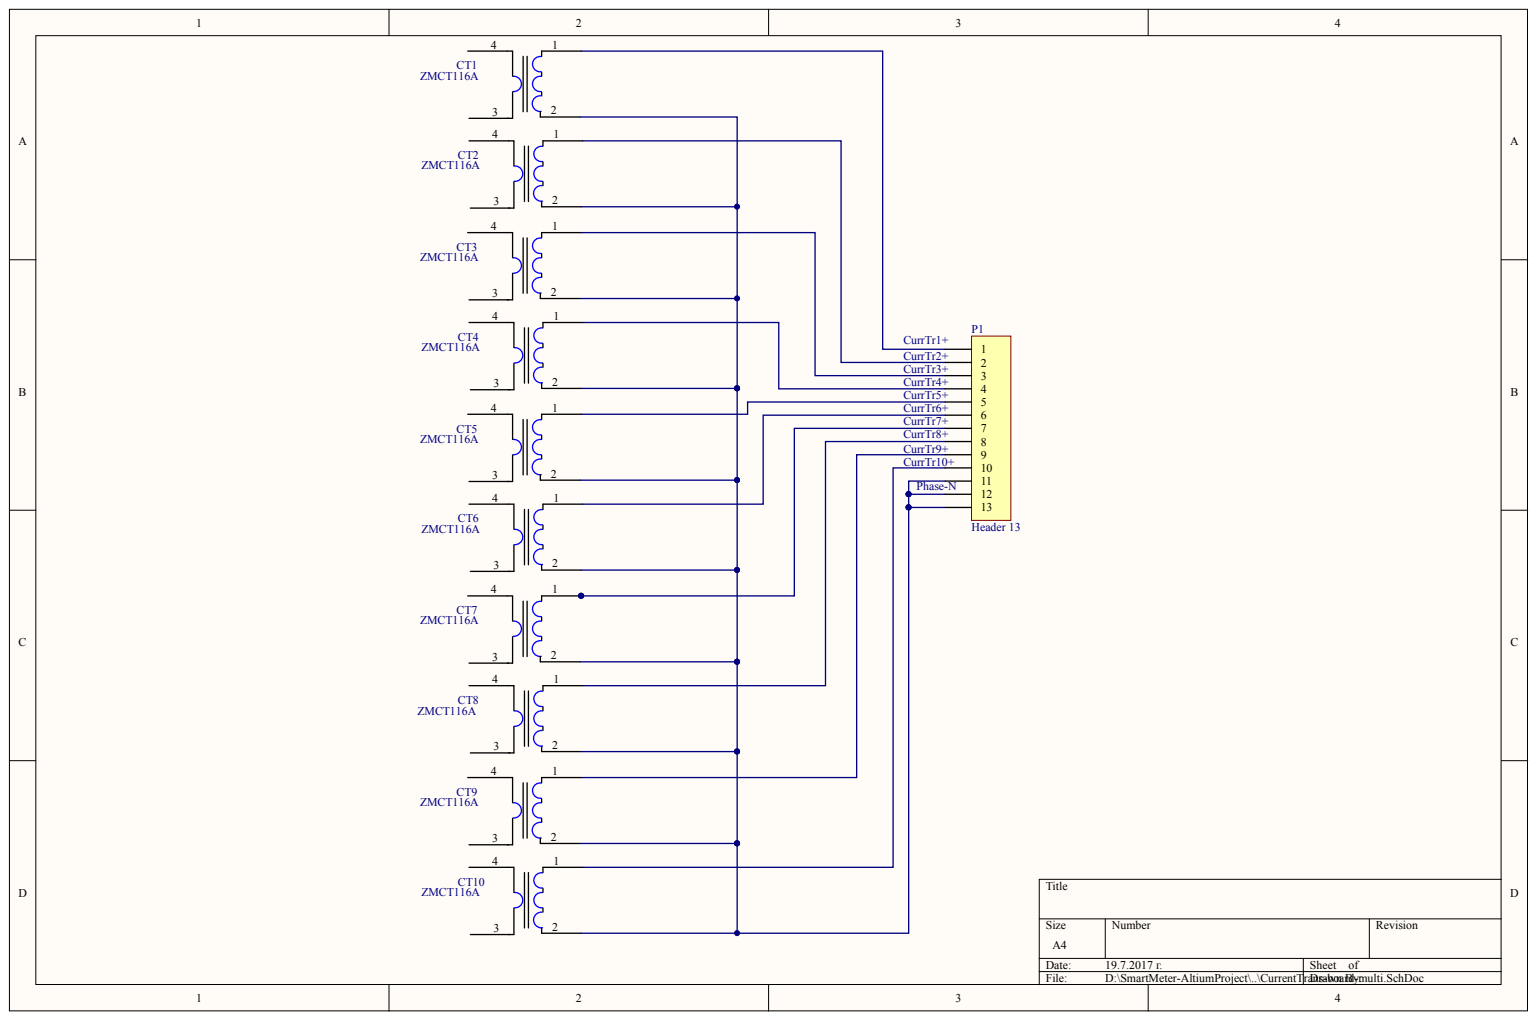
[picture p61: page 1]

CurrTr2+
CurrTr3+
CurrTr4+
CurrTr5+
CurrTr6+
CurrTr7+
CurrTr8+
CurrTr9+
CurrTr10+

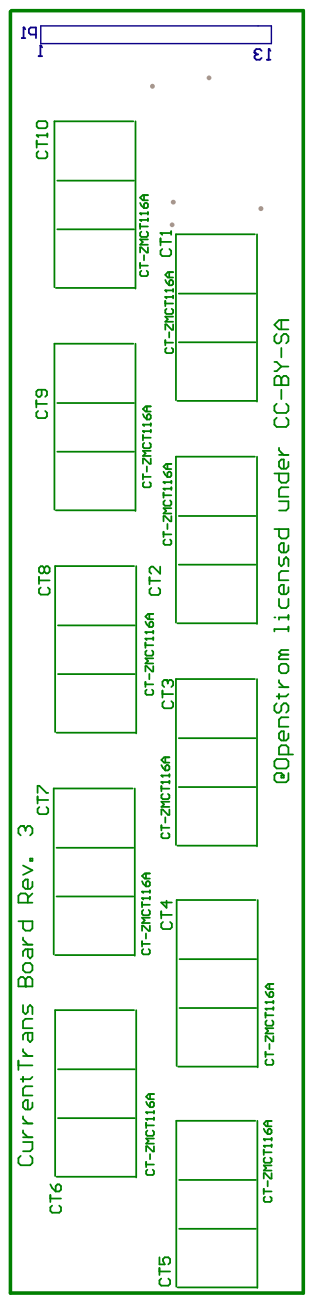
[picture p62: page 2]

Designator | Manufacturer | Mfr.PN# | PartType | Quantity | Suppl.PN# | Supplie r

CT1, CT2, CT3, CT4, CT5, CT6, CT7, CT8, CT9, CT10 | NanJing ZeMing Electronics Co.Ltd | ZMCT116A | ZMCT116A | 10

P1 | JYR Ecec Co.,Ltd China | 2.54mm 90 degHea der 13 | | 1 | | Alibaba

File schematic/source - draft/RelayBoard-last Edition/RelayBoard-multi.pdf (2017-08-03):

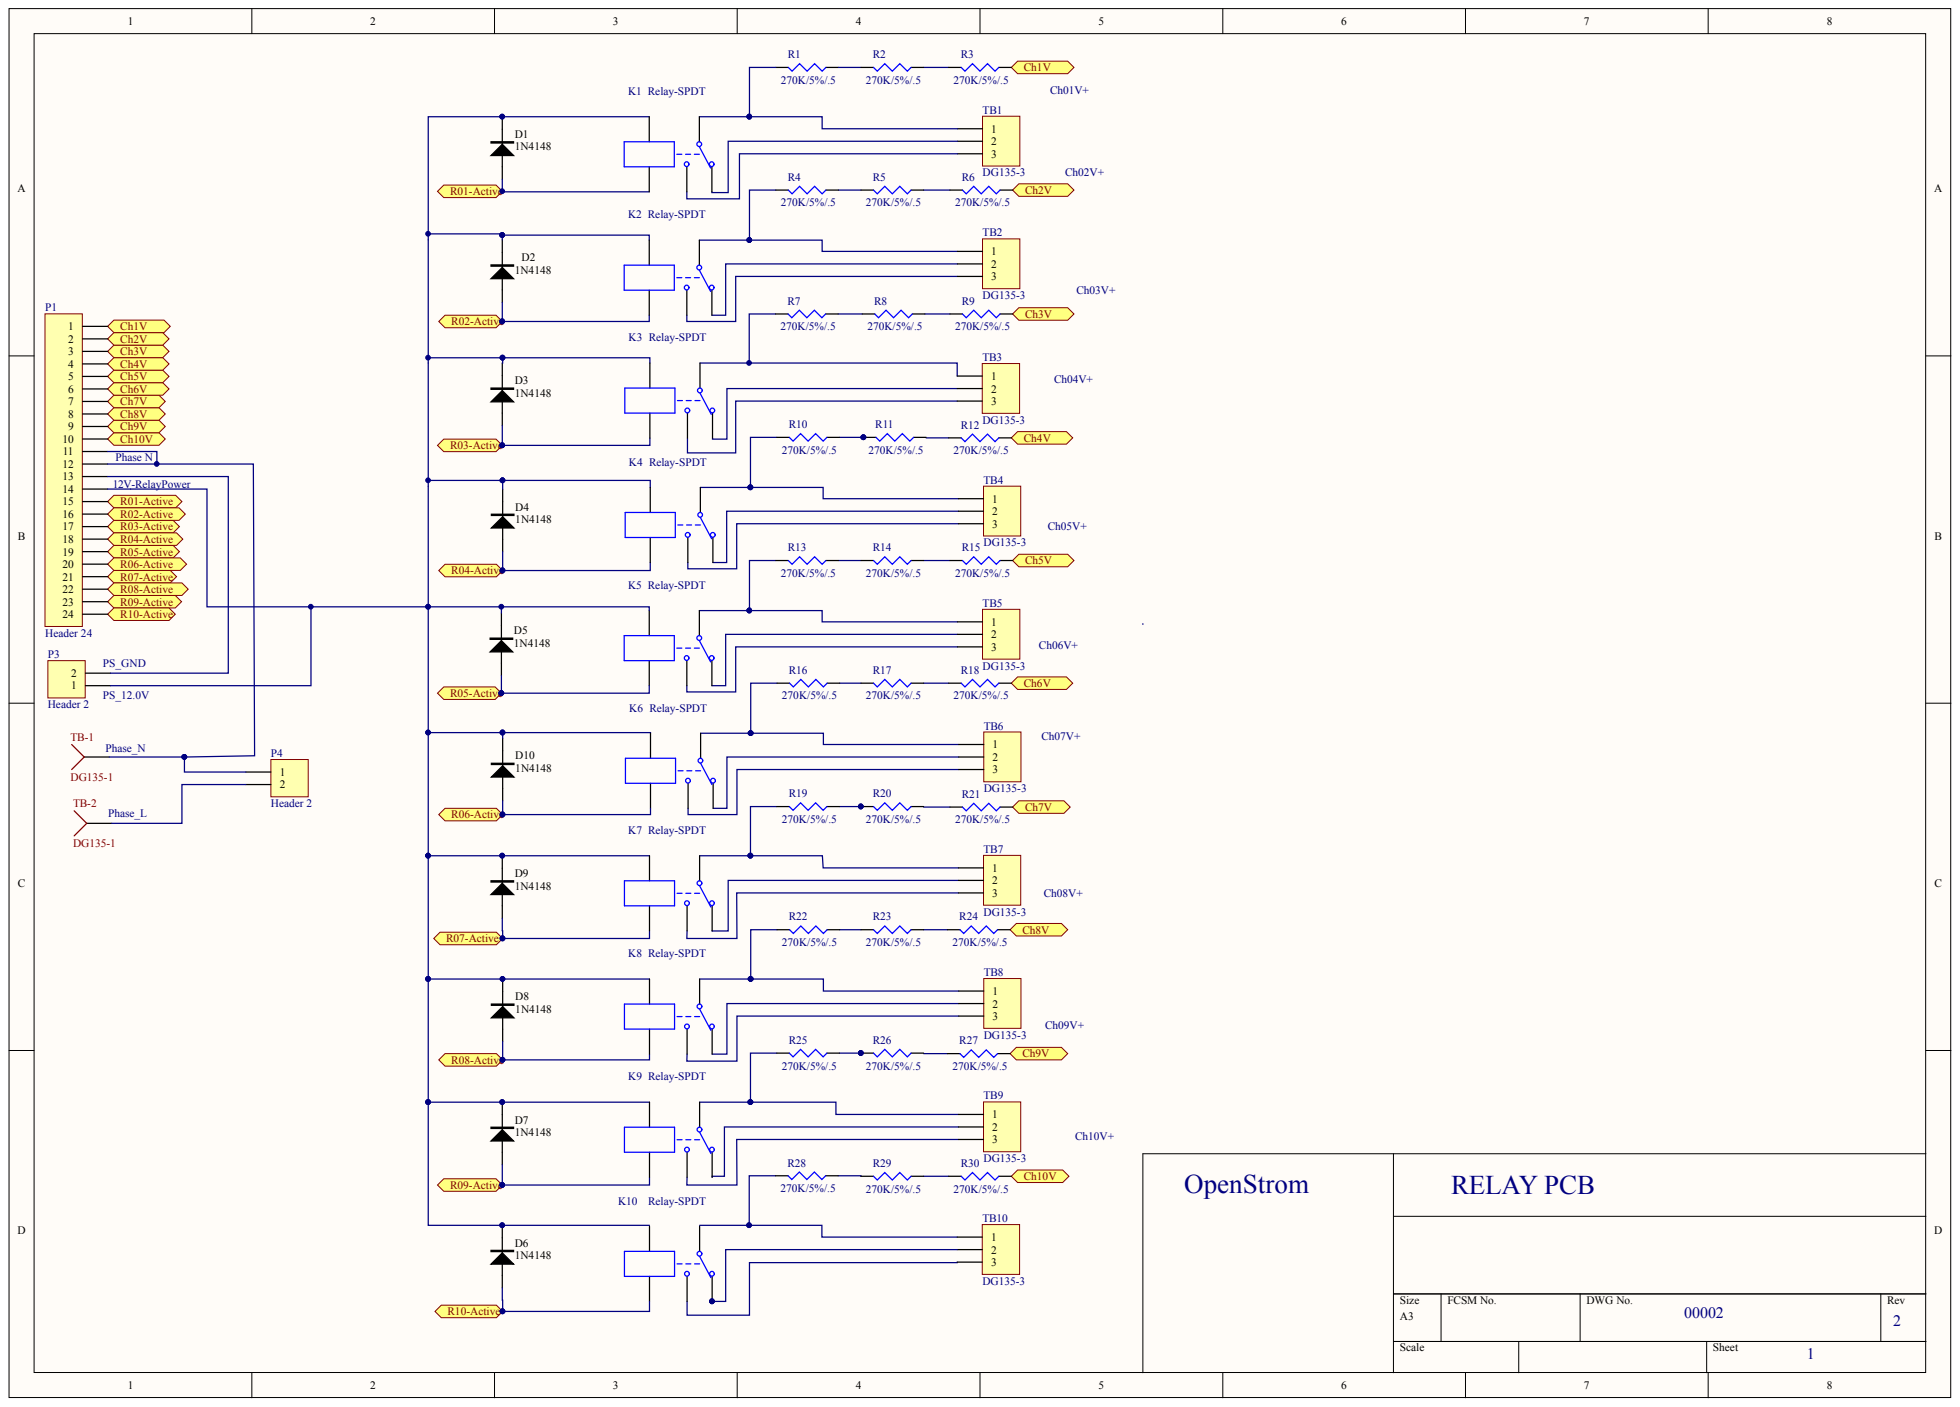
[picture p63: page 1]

12V-RelayPower
R05-Active R03-Active R01-Active R02-Active R04-Active R06-Active R08-Active R09-Active

R10-Active

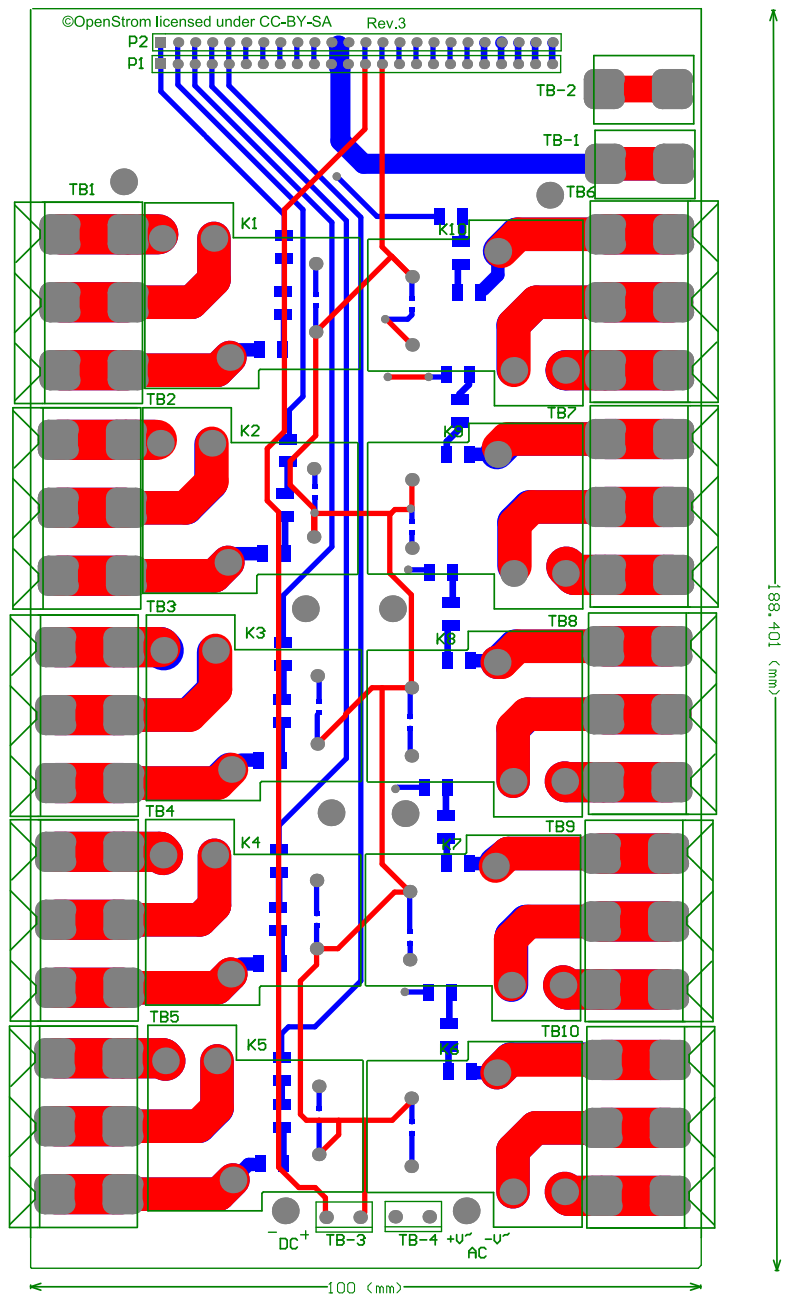
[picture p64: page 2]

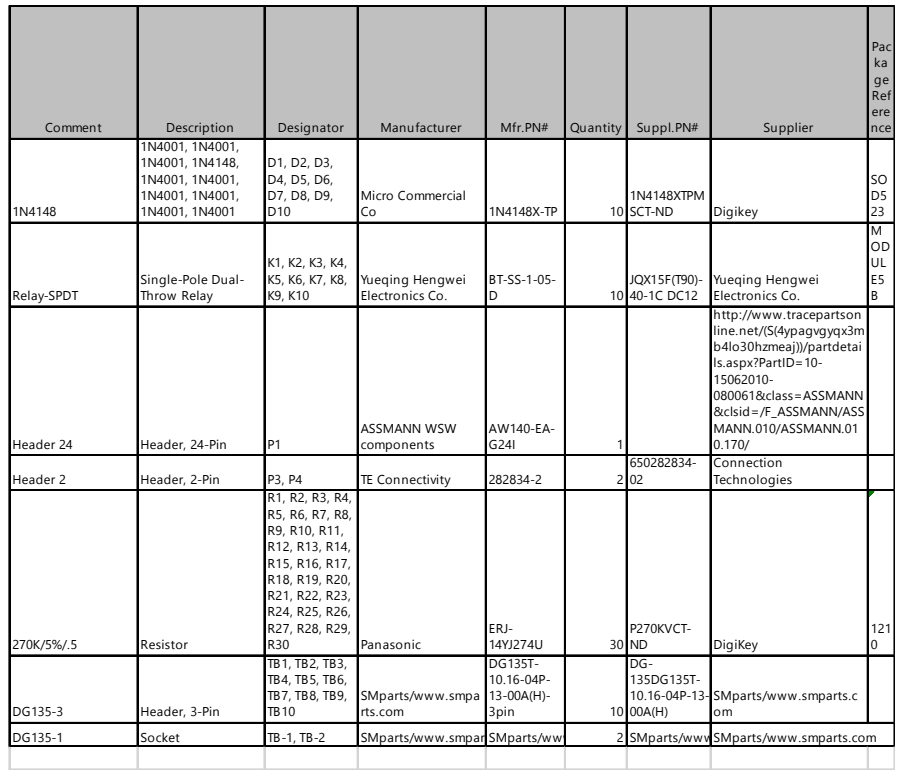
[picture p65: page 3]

Comment | Description | Designator | Manufacturer | Mfr.PN# | Quantity | Suppl.PN# | Supplier | Pac ka ge Ref ere nce

1N4148 | 1N4001, 1N4001, 1N4001, 1N4148, 1N4001, 1N4001, 1N4001, 1N4001, 1N4001, 1N4001 | D1, D2, D3, D4, D5, D6, D7, D8, D9, D10 | Micro Commercial Co | 1N4148X-TP | 10 | 1N4148XTPM SCT-ND | Digikey | SO D5 23

Relay-SPDT | Single-Pole Dual-Throw Relay | K1, K2, K3, K4, K5, K6, K7, K8, K9, K10 | Yueqing Hengwei Electronics Co. | BT-SS-1-05-D | 10 | JQX15F(T90)-40-1C DC12 | Yueqing Hengwei Electronics Co. | M OD UL E5 B

Header 24 | Header, 24-Pin | P1 | ASSMANN WSW components | AW140-EA-G24I | 1 | | http://www.tracepartsonline.net/(S(4ypagvgyqx3mb4lo30hzmeaj))/partdetai ls.aspx?PartID=10-15062010-080061&class=ASSMANN &clsid=/F_ASSMANN/ASS MANN.010/ASSMANN.01 0.170/

Header 2 | Header, 2-Pin | P3, P4 | TE Connectivity | 282834-2 | 2 | 650282834-02 | Connection Technologies

270K/5%/.5 | Resistor | R1, R2, R3, R4, R5, R6, R7, R8, R9, R10, R11, R12, R13, R14, R15, R16, R17, R18, R19, R20, R21, R22, R23, R24, R25, R26, R27, R28, R29, R30 | Panasonic | ERJ-14YJ274U | 30 | P270KVCT-ND | DigiKey | 121 0

DG135-3 | Header, 3-Pin | TB1, TB2, TB3, TB4, TB5, TB6, TB7, TB8, TB9, TB10 | SMparts/www.smpa rts.com | DG135T-10.16-04P-13-00A(H)-3pin | 10 | DG-135DG135T-10.16-04P-13-00A(H) | SMparts/www.smparts.c om

DG135-1 | Socket | TB-1, TB-2 | SMparts/www.smpartSMparts/www | | 2 | SMparts/wwwSMparts/www.smparts.com

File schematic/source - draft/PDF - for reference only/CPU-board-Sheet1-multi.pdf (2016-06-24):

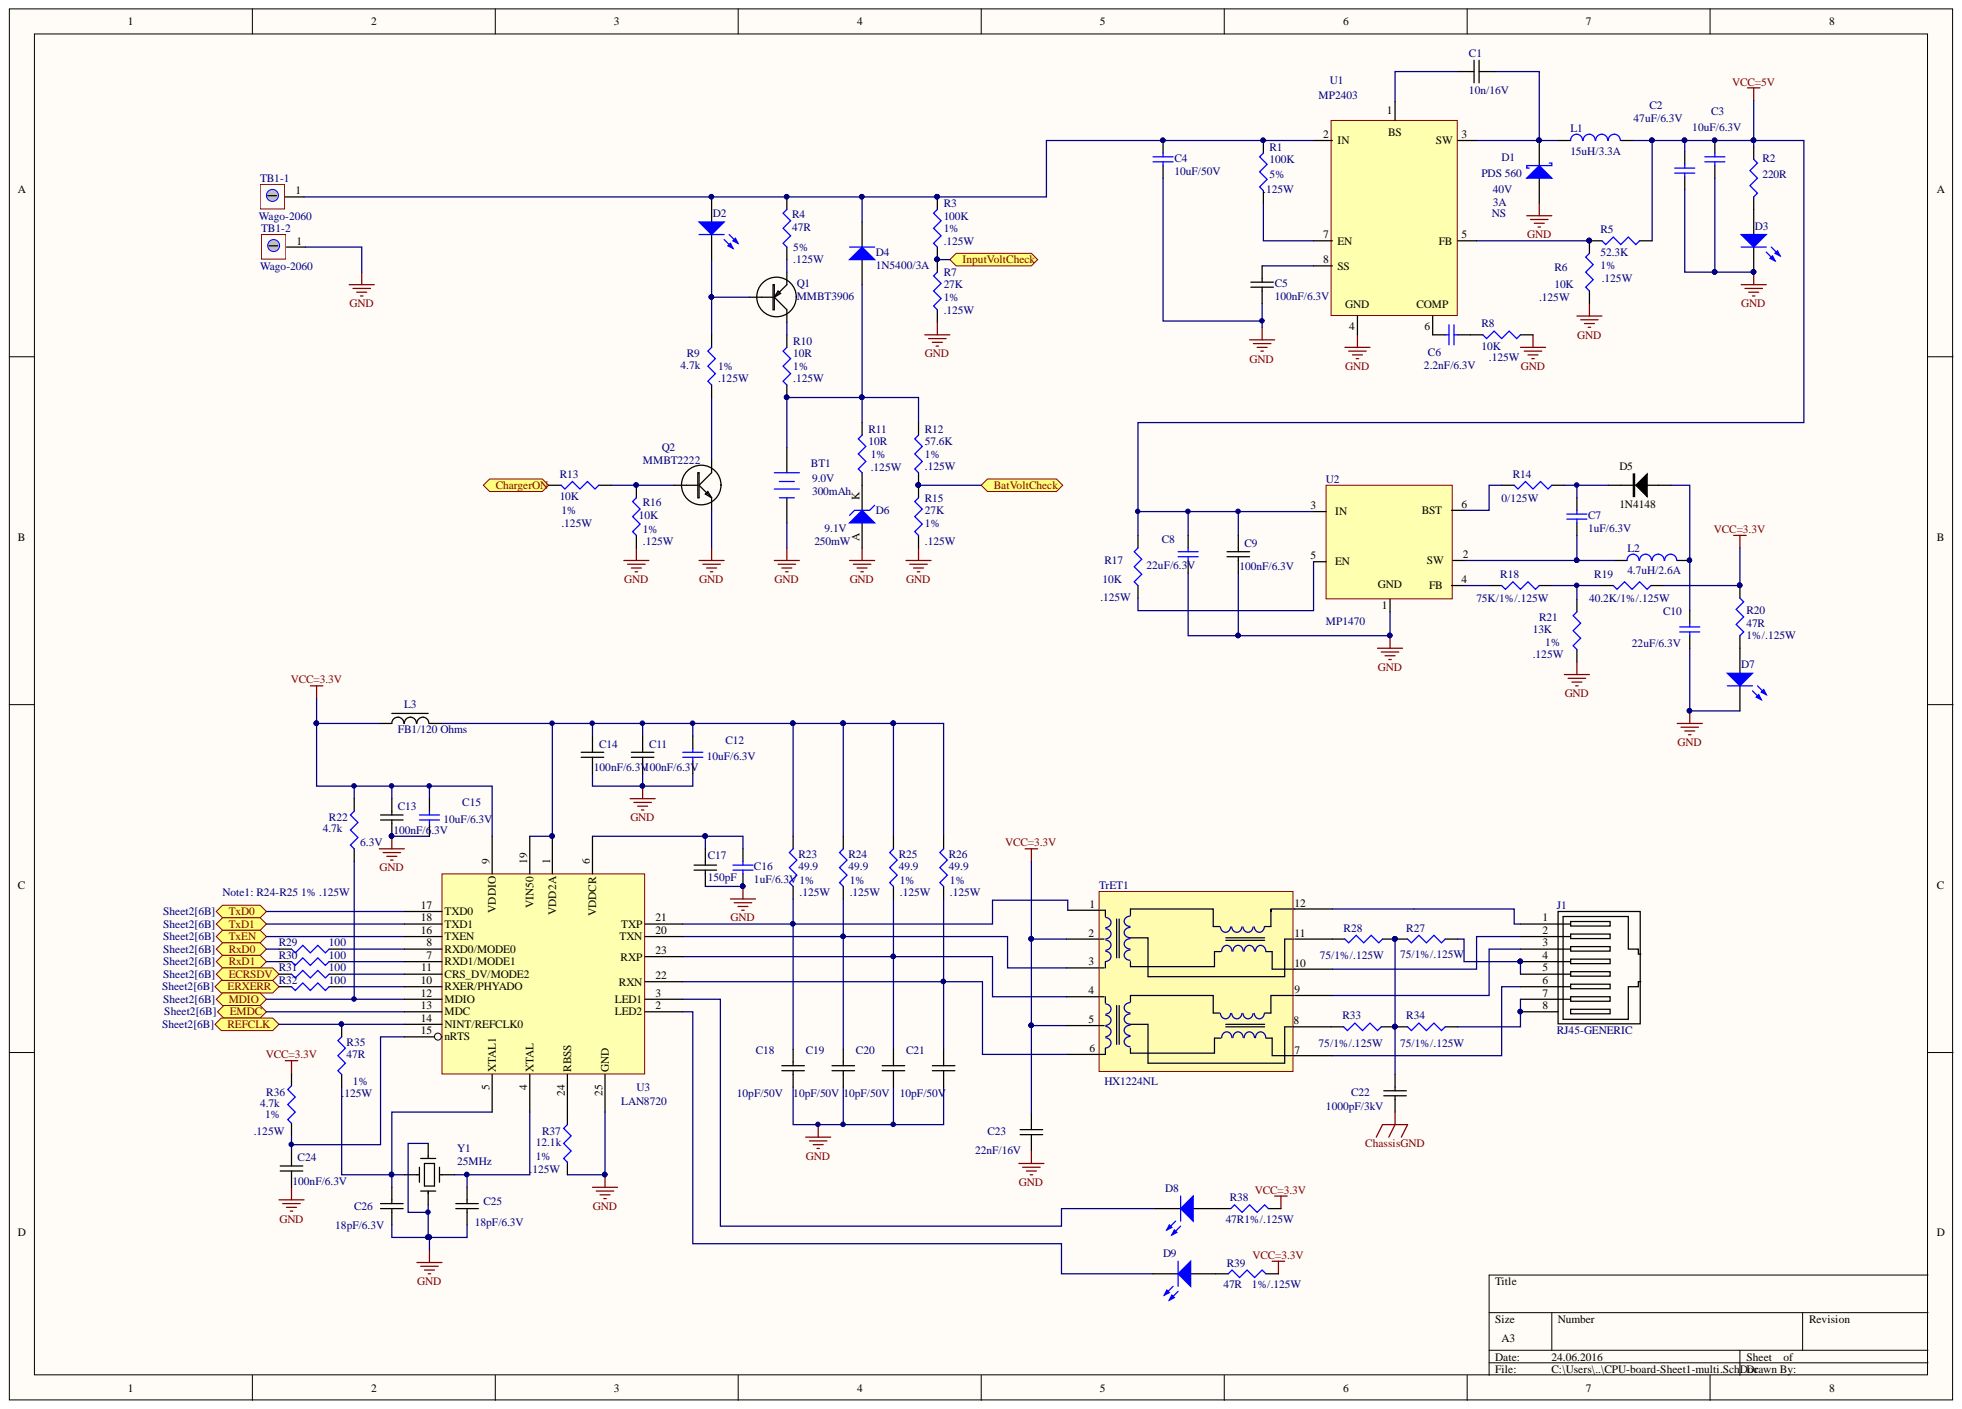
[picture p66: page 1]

SW GND | 2 | 4.7uH/2.6A

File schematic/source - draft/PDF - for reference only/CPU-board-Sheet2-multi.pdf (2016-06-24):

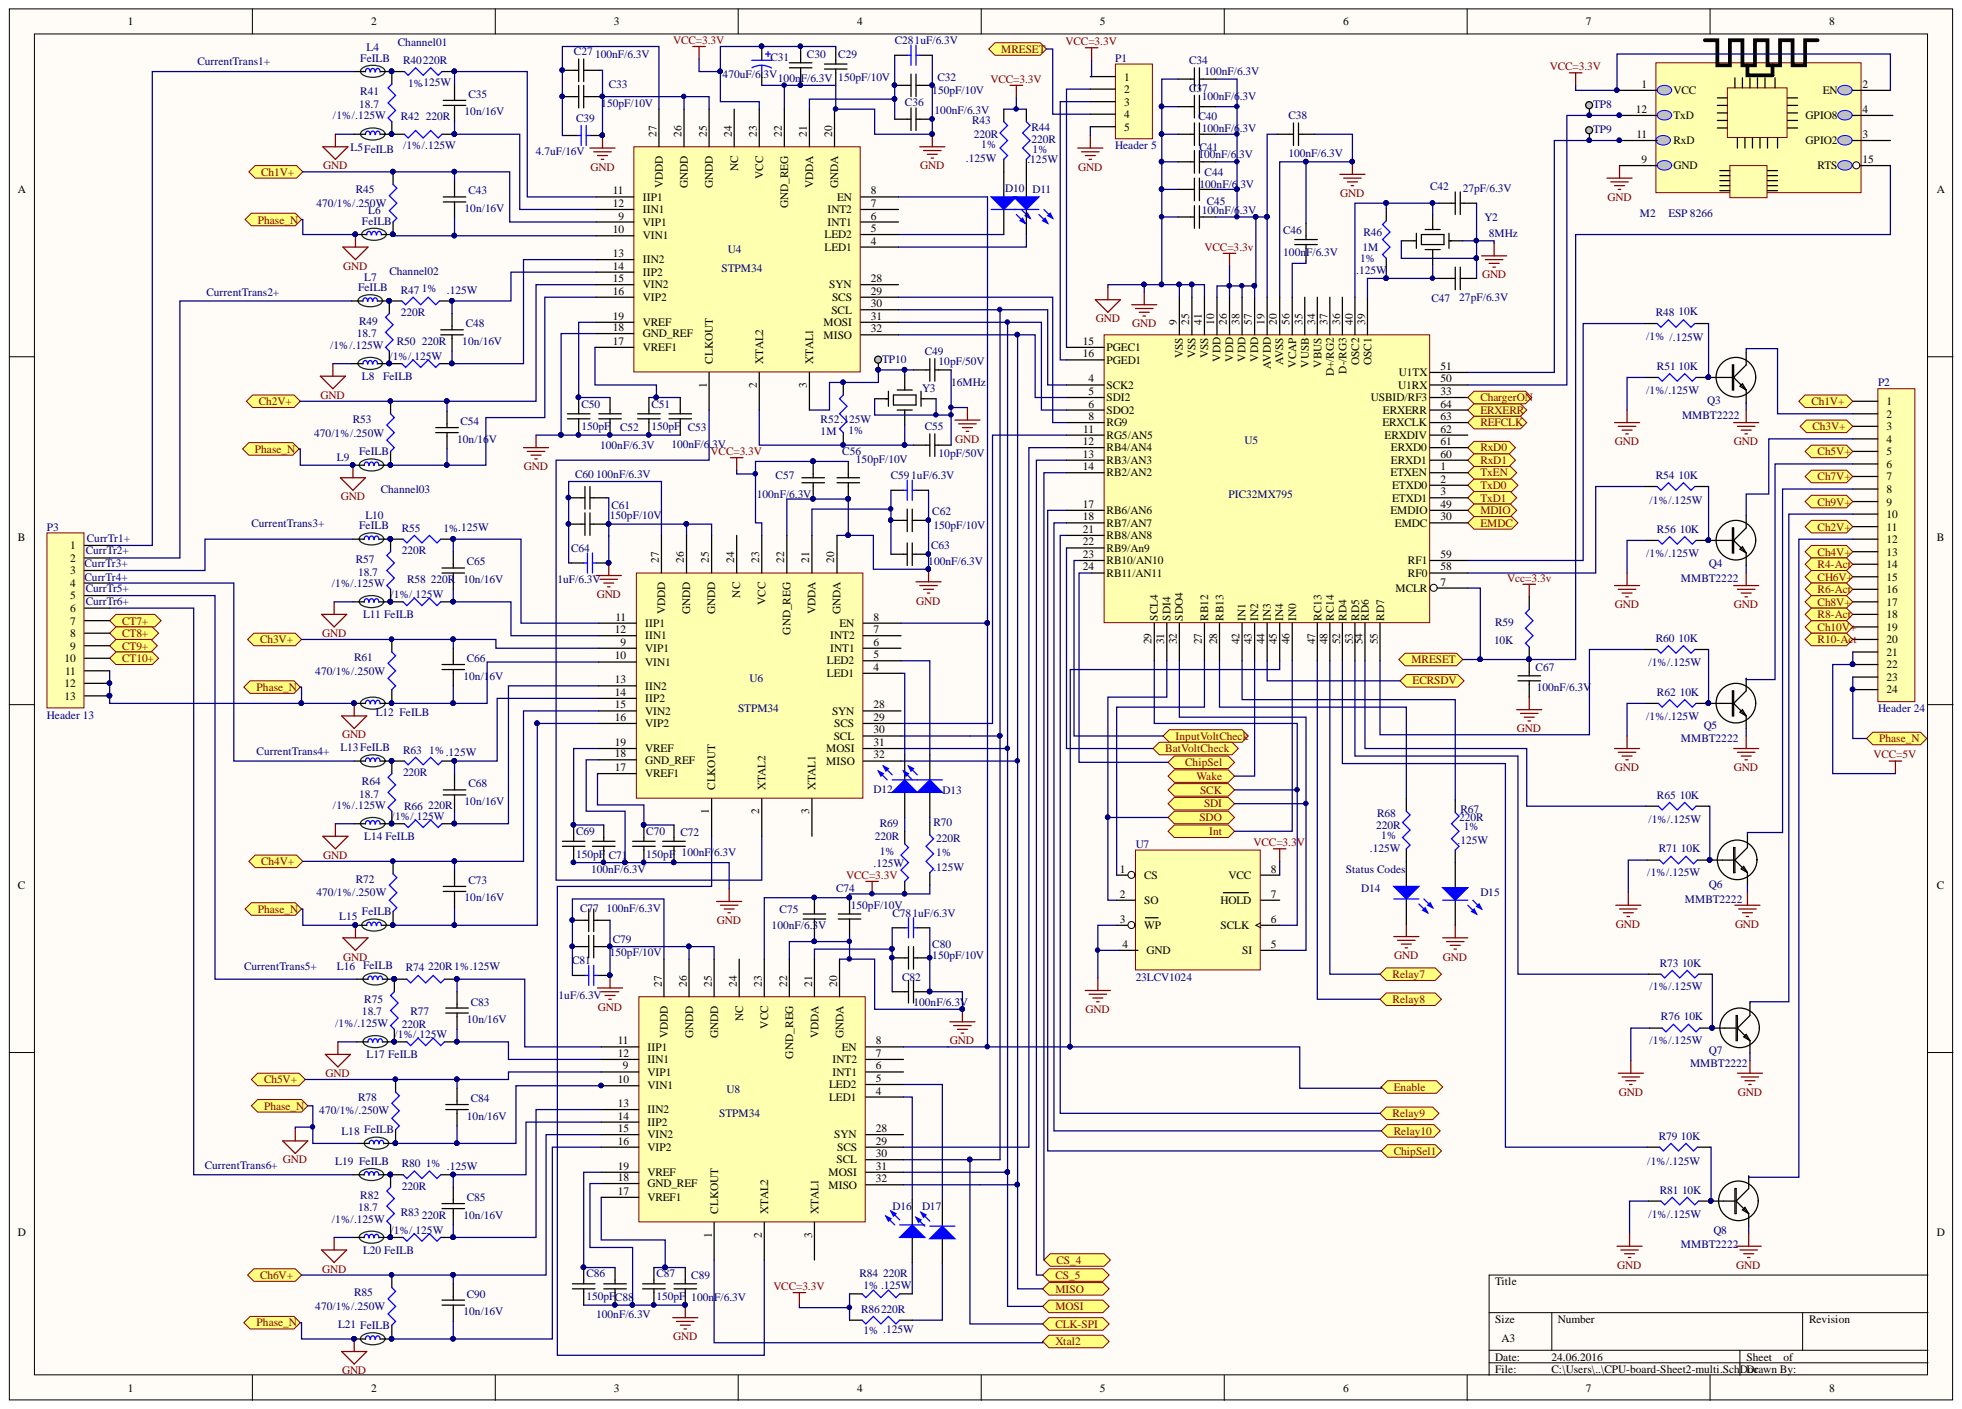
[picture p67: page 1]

IIP2 14
VIN2 15
VIP2 16

VREF1 17 GND_REF 18 VREF 19

GND | L12 FeILB R63 R66 220R L14 FeILB | | VIN2 15

VCC=3.3V 1% .125W

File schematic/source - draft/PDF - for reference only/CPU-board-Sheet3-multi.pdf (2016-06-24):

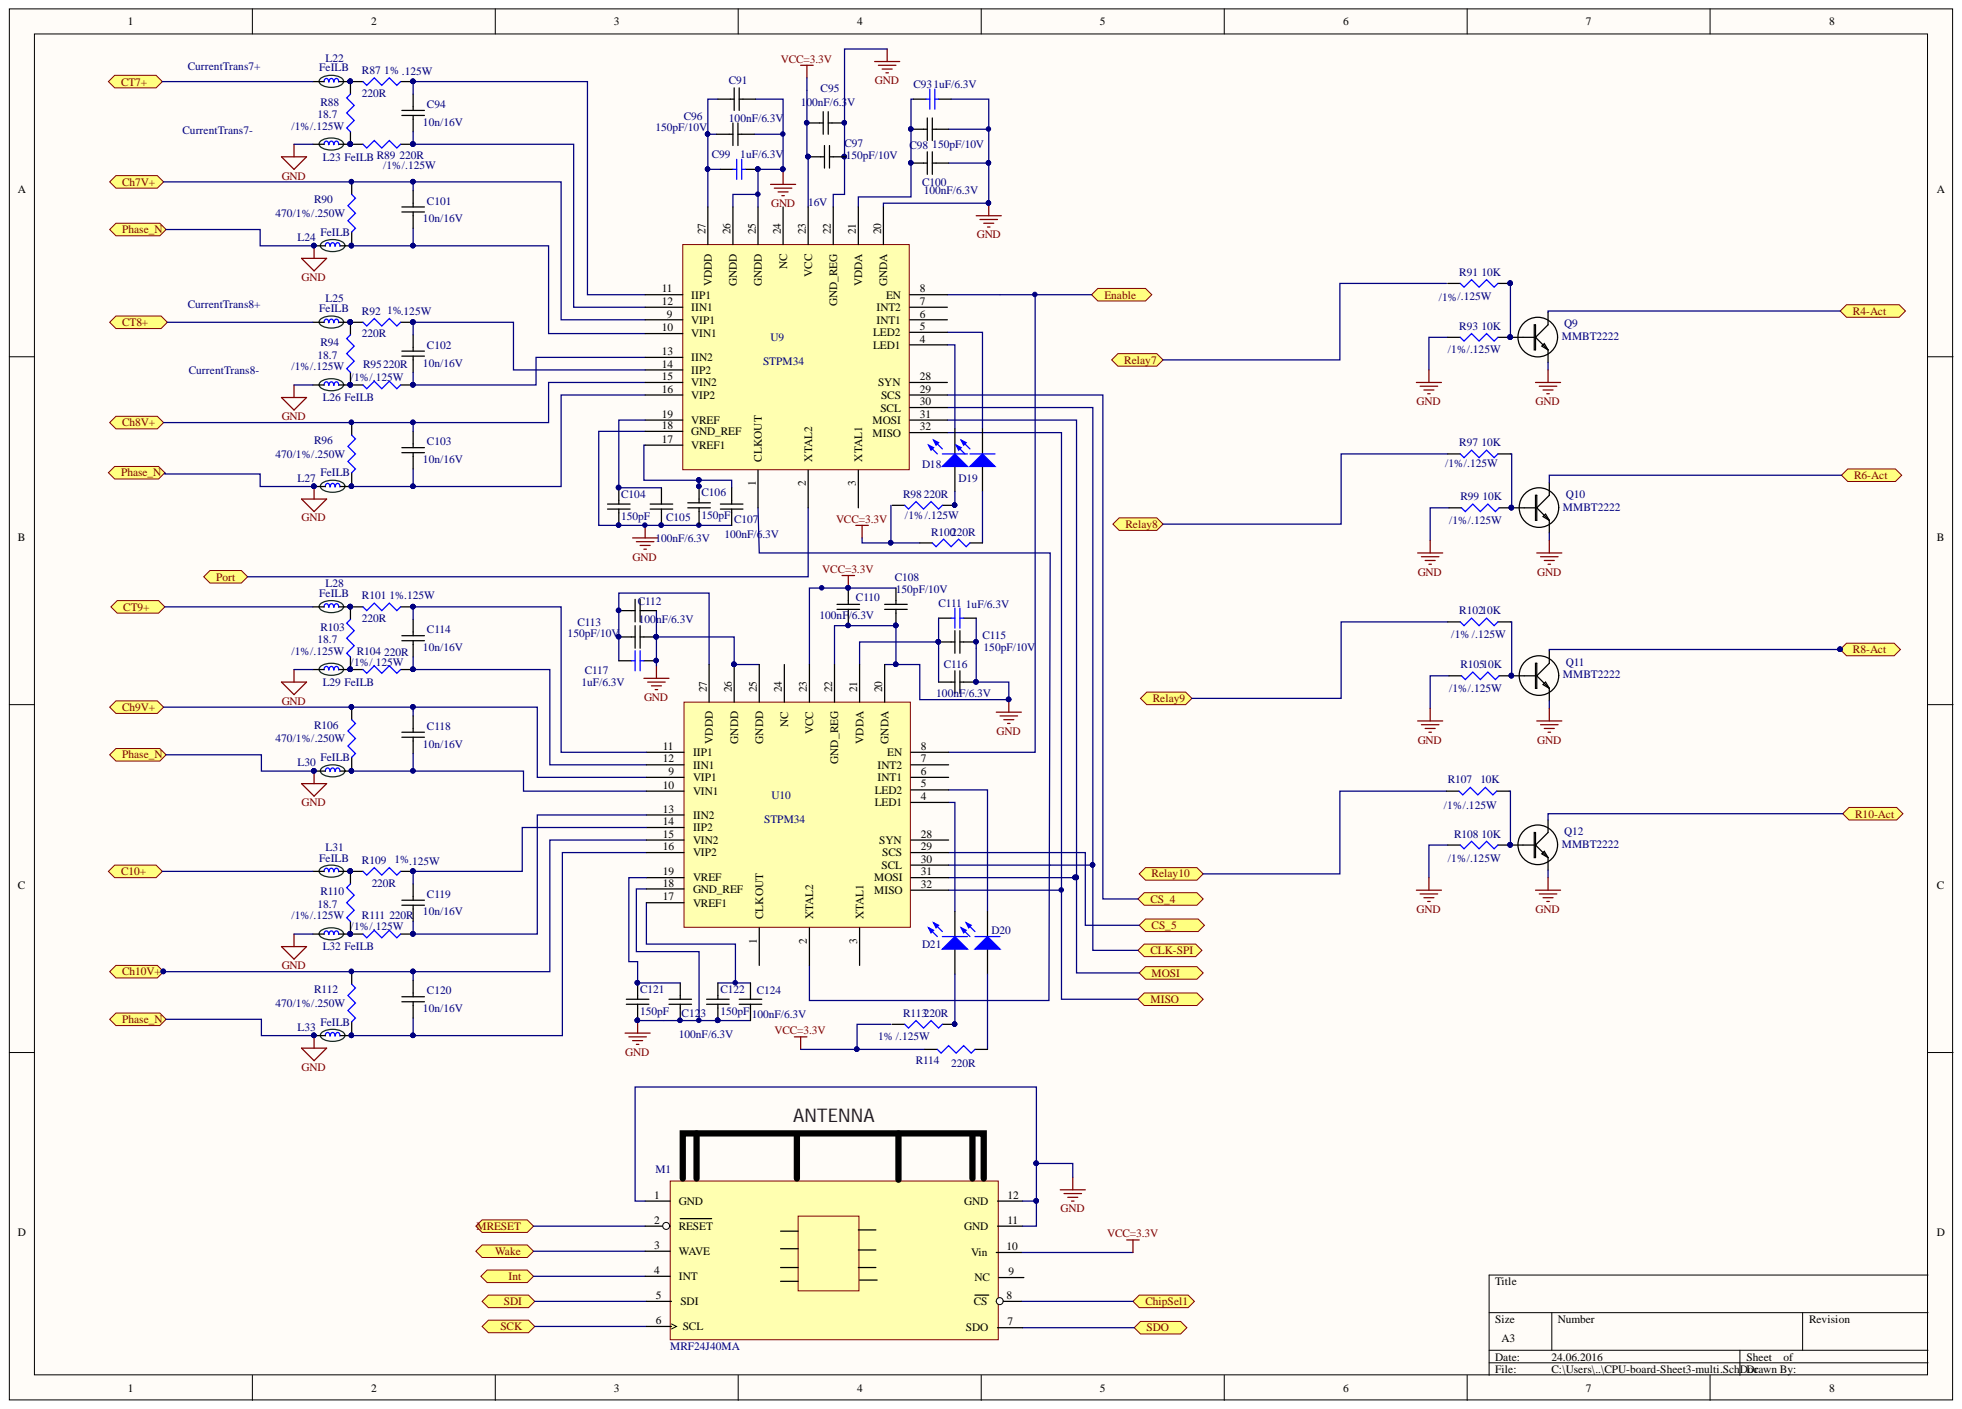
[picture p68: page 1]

VIN1 10

VIN2 15

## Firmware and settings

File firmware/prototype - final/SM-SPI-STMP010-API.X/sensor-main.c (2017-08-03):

/* 
 * File:   sensor-main.c
 * Author: Anton Tachev
 * Description: The main function SM-SPI-STMP02 configurates STPM 34 IC and
 * get energy parameters such as:
 * -Active Energy&Power;
 * -Reactive Energy&Power
 * -Apparent Energy&Power
 * -Fundamental Energy, ph1 Currents&Voltages, ph2 Currents&Voltages
 * Created on:    24.02.2017
 */
/*----------------SPI 2 module identification---------------------------------*/
/* SCK2 - pin2 RE6                         
 * SDI2 - pin5 RG7
 * SDO2 - pin 6 RG8
 * SCS - pin 9 RG9
 * Enable(EN) - pin 45 RD11
 */

#include <stdio.h>
#include <stdlib.h>
#include <plib.h>
#include <p32xxxx.h>
#include <proc/p32mx795f512h.h>
#include "relay.h"
#include <stdint.h>
//#include "STPM-define.h"

/*----------------Function prototypes -----------------------------------------*/

void Init_STPM34(int chnSel,unsigned int port,unsigned int _bits);        //function prototype are defined in STPM34_header.h
void SPI_Init();
void Delay(void);
void ReadFrame(unsigned short address, uint32_t * buffer,int port,int bits);
void SendFrame(char readAdd,char writeAdd, char dataLSB,char dataMSB,int port,int bits);
void FrameDelay(void);                          
//void GetParams(unsigned int port, unsigned _bits, int *buffer);
void GetParamsEnergyPH1(unsigned int port, unsigned _bits,int *buffer, relay_t activeRelay,int i);
void GetParamsEnergyPH2(unsigned int port, unsigned _bits,int *buffer, relay_t activeRelay,int i);
void GetParamsPowerPH1(unsigned int port, unsigned _bits,int *buffer, relay_t activeRelay,int i);
void GetParamspowerPH2(unsigned int port, unsigned _bits,int *buffer, relay_t activeRelay,int i);

void ReadC1Data(uint32_t *dataBuf,int port, relay_t relayNum, unsigned  _bits);
void ReadC2Data(uint32_t *dataBuf, int port, relay_t relayNum, unsigned _bits);

void GetParamsPowerPH1A(unsigned int port,unsigned int _bits,uint32_t *buf1);
void GetParamsPowerPH1R(unsigned int port,unsigned int _bits,uint32_t *buf1);
void GetParamsPowerPH2A(unsigned int port,unsigned int _bits,uint32_t *buf1);
void GetParamsPowerPH2R(unsigned int port,unsigned int _bits,uint32_t *buf1);

void BlockCRC(unsigned int port, unsigned _bits);
void CHCalibrate();
uint32_t Converse(uint32_t doubleword);
uint32_t PowerConverse(uint32_t doubleword);
void TestRWparameters(void);

void Get1();
void Get2();
// configuration settings
//#pragma config FPLLMUL = MUL_15,FPLLODIV = DIV_4
#pragma config FPLLMUL = MUL_20, FPLLIDIV = DIV_2, FPLLODIV = DIV_1, FWDTEN = OFF //FPLLMUL = MUL_15=60Mz,FPLLMUL = MUL_20=80Mhz

#pragma config POSCMOD = XT, FNOSC = PRIPLL, FPBDIV = DIV_4,ICESEL=ICS_PGx1
//#pragma config FNOSC=FRCPLL,POSCMOD=OFF,ICESEL=ICS_PGx1,FPBDIV= DIV_4// old 8 - periphelal clock=20Mhz(FPBDIV)
/*-------------Global Variables--------------------------------------*/
int i,j,k,l;
int delayValue;
int chnSel=6;                           //the number of sensor IC  20/04/2017
int chnNum=6;
uint32_t v1_bytes;
uint32_t c1_bytes;
uint32_t limitCurrentValue1=0x0000a740;     //this value is 40Amps input current
unsigned int port;
unsigned int _bits;
unsigned int bits5;
static uint32_t *tempbuff;
uint32_t receiveBuffer1;
uint32_t clearBuffer;
int cs;
/*-------------------------------------------------------------------*/
/*----------Energy Parameter's buffers area--------------------------*/

uint32_t buf1[10];              //contains energy params for Channels 1               
uint32_t buf2[10];              //contains energy params for Channels 2 
uint32_t buf3[10];              //contains energy params for Channels 3 
uint32_t buf4[10];              //contains energy params for Channels 4 
uint32_t buf5[10];              //contains energy params for Channels 5
uint32_t buf6[10];              //contains energy params for Channels 6
uint32_t buf7[10];              //contains energy params for Channels 7
uint32_t buf8[10];              //contains energy params for Channels 8
uint32_t buf9[10];              //contains energy params for Channels 9
uint32_t buf10[10];              //contains energy params for Channels 10
uint32_t *buff1;
uint32_t *buff2;
uint32_t pr;
unsigned char crcCom[5]={0x24,0x24,0x07,0x00,0x15};
int main()
  {
  
  /* configure the proper PB frequency and the number of wait states */
   SYSTEMConfigWaitStatesAndPB(80000000L);
   CheKseg0CacheOn();                           // enable the cache for the best performance
   RtccShutdown();                              //enable RC13&RC14 as a I/O
   mT2ClearIntFlag();
 /*---------------------------------------------*/
 
   SPI_Init();              //initialize SPI INPUT/OUTPUTS
   STPMInitReset();
   SelectSPIall();          //very important select channel SPI
   SetSPIx(1);             // Select SPI for SPTM34-1 
   _bits=BIT_9;
   port=IOPORT_G;
   BlockCRC(port,_bits);

   buff1=buf1;
   Init_STPM34(1,port,_bits);        //(the last 1,port,_bits)
 // CHCalibrate();
  //SpiInit1();
 // TestRWparameters();                 // very important use for separated testing
// to do test program //
  
  activeRelayArr[0].relayPort1=IOPORT_F;            //select port F
  activeRelayArr[0].relayPin1=BIT_1;                //select Relay1 - connector P2-15
  activeRelayArr[0].relayPort2=IOPORT_F;            //select port F
  activeRelayArr[0].relayPin2=BIT_0;                //select Relay2 - connector P2-16
         
  activeRelayArr[1].relayPort1=IOPORT_D;            //select port D
  activeRelayArr[1].relayPin1=BIT_7;                //select Relay3 - connector P2-17
  activeRelayArr[1].relayPort2=IOPORT_D;            //select port D
  activeRelayArr[1].relayPin2=BIT_6;                //select Relay4 - connector P2-18
         
  activeRelayArr[2].relayPort1=IOPORT_D;            //select port D
  activeRelayArr[2].relayPin1=BIT_5;                //select Relay5 - connector P2-19
  activeRelayArr[2].relayPort2=IOPORT_D;            //select port D
  activeRelayArr[2].relayPin2=BIT_4;                //select Relay6 - connector P2-20
         
  activeRelayArr[3].relayPort1=IOPORT_C;            //select port C
  activeRelayArr[3].relayPin1=BIT_14;               //select Relay7 - connector P2-21
  activeRelayArr[3].relayPort2=IOPORT_C;            //select port C
  activeRelayArr[3].relayPin2=BIT_13;               //select Relay8 - connector P2-22
         
  activeRelayArr[4].relayPort1=IOPORT_B;            //select port B
  activeRelayArr[4].relayPin1=BIT_8;                //select Relay9 - connector P2-23
  activeRelayArr[4].relayPort2=IOPORT_B;            //select port B
  activeRelayArr[4].relayPin2=BIT_7;                //select Relay10 - connector P2-24
 
   while(1)
   {
    /*------Select Channel-01&02 and download energy parameters--------------------*/
    /* Input ID Parameters:                                                     */
    /*     - CS1  - BIT_9                                                       */
    /*     - port - IOPORT_G                                                    */
    /*     - active relays -Relay1, Relay2                                      */
    /*     - transfer Buffer-buff1[10],buff2[10]                                          */
    /*     - Energy parameters:                                                 */
    /*          - current Irms;                                                 */
    /*          - voltage Vrms                                                  */
    /*          - Active Power PHx-A                                           */
    /*          - Reactive Power PHx-R                                          */
    /*--------------------------------------------------------------------------*/
      
       SetSPIx(1);                          // set up SPI interface for chn-01 & chn-02   
       _bits=BIT_9;                         //CS1 active
       port=IOPORT_G;                       //IOPORT_G=0x05
       BlockCRC(port,_bits);
       Init_STPM34(1,port,_bits);
       buff1=buf1;
       buff2=buf2;
       j=0;
       i=0;
       ReadC1Data(buff1,port,activeRelayArr[0],_bits);      //Get Irms and Vrms
       j++;
       GetParamsPowerPH1A(port,_bits,buf1);                 // Get Active Power chn1
       j++;
       GetParamsPowerPH1R(port,_bits,buf1);                 // get Reactive power chn1
       i=1;
       j=0;
       ReadC2Data(buff2,port,activeRelayArr[1],_bits);      //Get Irms and Vrms
       j++;
       GetParamsPowerPH2A(port,_bits,buf2);                 // Get Active Power chn2
       j++;
       GetParamsPowerPH2R(port,_bits,buf2);                 // get Reactive power chn2
    /*---------------------------------------------------------------------------*/   
       
    /*------Select Channel-03&04 and download energy parameters--------------------*/
    /* Input ID Parameters:                                                     */
    /*     - CS2  - BIT_5                                                       */
    /*     - port - IOPORT_B                                                    */
    /*     - active relays -Relay3, Relay4                                      */
    /*     - transfer Buffer-buff3[10],buff4[10]                                          */
    /*     - Energy parameters:                                                 */
    /*          - current Irms;                                                 */
    /*          - voltage Vrms                                                  */
    /*          - Active Power PHx-A                                           */
    /*          - Reactive Power PHx-R                                          */
    /*--------------------------------------------------------------------------*/
      
       SetSPIx(2);                          // set up SPI interface for chn-03&04   
       _bits=BIT_5;                         //CS2 active
       port=IOPORT_B;                       
       BlockCRC(port,_bits);
       Init_STPM34(2,port,_bits);
       buff1=buf3;
       buff2=buf4;
       i=2;
       j=0;
       ReadC1Data(buff1,port,activeRelayArr[2],_bits);      //Get Irms and Vrms
       j++;
       GetParamsPowerPH1A(port,_bits,buf1);                 // Get Active Power chn1
       j++;
       GetParamsPowerPH1R(port,_bits,buf1);                 // get Reactive power chn1
       i=3;
       j=0;
       ReadC2Data(buff2,port,activeRelayArr[3],_bits);      //Get Irms and Vrms
       j++;
       GetParamsPowerPH2A(port,_bits,buf2);                 // Get Active Power chn2
       j++;
       GetParamsPowerPH2R(port,_bits,buf2);                 // get Reactive power chn2
    /*--------------------------------------------------------------------------*/  
       
    /*------Select Channel-05&06 and download energy parameters-----------------*/
    /* Input ID Parameters:                                                     */
    /*     - CS3  - BIT_4                                                       */
    /*     - port - IOPORT_B                                                    */
    /*     - active relays -Relay5, Relay6                                      */
    /*     - transfer Buffer-buff5[10],buff6[10]                                          */
    /*     - Energy parameters:                                                 */
    /*          - current Irms;                                                 */
    /*          - voltage Vrms                                                  */
    /*          - Active Power PHx-A                                           */
    /*          - Reactive Power PHx-R                                          */
    /*--------------------------------------------------------------------------*/
      
       SetSPIx(3);                          // set up SPI interface for chn-03&04   
       _bits=BIT_4;                         //CS2 active
       port=IOPORT_B;                       
       BlockCRC(port,_bits);
       Init_STPM34(3,port,_bits);
       buff1=buf5;
       buff2=buf6;
       i=6;
       j=0;
       ReadC1Data(buff1,port,activeRelayArr[4],_bits);      //Get Irms and Vrms
       j++;
       GetParamsPowerPH1A(port,_bits,buf1);                 // Get Active Power chn1
       j++;
       GetParamsPowerPH1R(port,_bits,buf1);                 // get Reactive power chn1
       i=7;
       j=0;
       ReadC2Data(buff2,port,activeRelayArr[4],_bits);      //Get Irms and Vrms
       j++;
       GetParamsPowerPH2A(port,_bits,buf2);                 // Get Active Power chn2
       j++;
       GetParamsPowerPH2R(port,_bits,buf2);                 // get Reactive power chn2
     /*---------------------------------------------------------------*/  
     
    /*------Select Channel-07&08 and download energy parameters----- -----------*/
    /* Input ID Parameters:                                                     */
    /*     - CS4  - BIT_2                                                       */
    /*     - port - IOPORT_B                                                    */
    /*     - active relays -Relay7, Relay8                                      */
    /*     - transfer Buffer-buff7[10],buff8[10]                                          */
    /*     - Energy parameters:                                                 */
    /*          - current Irms;                                                 */
    /*          - voltage Vrms                                                  */
    /*          - Active Power PHx-A                                           */
    /*          - Reactive Power PHx-R                                          */
    /*--------------------------------------------------------------------------*/
    //    GetParamsEnergyPH1(port,_bits,buf2, activeRelayArr[0],i);         // select params from Chn3$4
       SetSPIx(4);                          // set up SPI interface for chn-03&04   
       _bits=BIT_2;                         //CS2 active
       port=IOPORT_B;                       
       BlockCRC(port,_bits);
       Init_STPM34(4,port,_bits);
       buff1=buf7;
       buff2=buf8;
       i=6;
       j=0;
       ReadC1Data(buff1,port,activeRelayArr[6],_bits);      //Get Irms and Vrms
       j++;
       GetParamsPowerPH1A(port,_bits,buf1);                 // Get Active Power chn1
       j++;
       GetParamsPowerPH1R(port,_bits,buf1);                 // get Reactive power chn1
       j++;
       i=7;
       j=0;
       ReadC2Data(buff2,port,activeRelayArr[7],_bits);      //Get Irms and Vrms
       j++;
       GetParamsPowerPH2A(port,_bits,buf2);                 // Get Active Power chn2
       j++;
       GetParamsPowerPH2R(port,_bits,buf2);                 // get Reactive power chn2
    /*---------------------------------------------------------------------------*/
     /*------Select Channel-09&10 and download energy parameters----- -----------*/
    /* Input ID Parameters:                                                     */
    /*     - CS5  - BIT_3                                                       */
    /*     - port - IOPORT_B                                                    */
    /*     - active relays -Relay9, Relay10                                      */
    /*     - transfer Buffer-buff9[10],buff10[10]                                          */
    /*     - Energy parameters:                                                 */
    /*          - current Irms;                                                 */
    /*          - voltage Vrms                                                  */
    /*          - Active Power PHx-A                                           */
    /*          - Reactive Power PHx-R                                          */
    /*--------------------------------------------------------------------------*/
      
       SetSPIx(5);                          // set up SPI interface for chn-03&04   
       _bits=BIT_3;                         //CS2 active
       port=IOPORT_B;                       
       BlockCRC(port,_bits);
       Init_STPM34(5,port,_bits);
       buff1=buf9;
       buff2=buf10;
       i=8;
       j=0;
       ReadC1Data(buff1,port,activeRelayArr[8],_bits);      //Get Irms and Vrms
       j++;
       GetParamsPowerPH1A(port,_bits,buf1);                 // Get Active Power chn1
       j++;
       GetParamsPowerPH1R(port,_bits,buf1);                 // get Reactive power chn1
       i=9;
       j=0;
       ReadC2Data(buff2,port,activeRelayArr[9],_bits);      //Get Irms and Vrms
       j++;
       GetParamsPowerPH2A(port,_bits,buf2);                 // Get Active Power chn2
       j++;
       GetParamsPowerPH2R(port,_bits,buf2);                 // get Reactive power chn2
      
    /*---------------------------------------------------------------------------*/
     
    
      
   }
} 
/*--------------------block CRC Routine----------------------------------------*/
/* This routine disable the CRC communication option --------------------------*/
/* -command    ReadReg, WriteReg, LSB,  MSB,  CRC                        
/*              0x24     0x24     0x07  0x00  0x15                             */

 void BlockCRC(unsigned int port, unsigned _bits)
{
   int i;
   SPI2CONbits.ON=0;            //stopSPI
   SPI2CONbits.MODE16=0;        //set communication byte 8 bits
   SPI2CONbits.MODE32=0;
   SPI2CONbits.ON=1;
 // while(1){                     //test point

   CSxActive(_bits);
   for(i=0;i<5;i++)
   {
       SPI2BUF=crcCom[i];
       while(SPI2STATbits.SPITBF){}
   }
   CSxInActive(_bits);
   FrameDelay();
//}
    SPI2CONbits.ON=0;            //stopSPI
    SPI2CONbits.MODE32=1;        // select Mode 32 bits
    SPI2CONbits.ON=1;            //startSPI
}
void CHCalibrate()
{
    //calibrate voltage V1
  // while(1){ 
   CSxActive(_bits);
   SPI2BUF=0xff10ffff;               //last set up calibration value 8044
   receiveBuffer1=SPI2BUF;
   FrameDelay1();                       //very important delay
   while(SPI2STATbits.SPITBF){}
   CSxInActive(_bits);
   FrameDelay();
  // }
    //calibrate current c1
    CSxActive(_bits);
    SPI2BUF=0x0A0Affff;               //0855last set up calibration value
    receiveBuffer1=SPI2BUF;
    FrameDelay1();                       //very important delay
    while(SPI2STATbits.SPITBF){}
    CSxInActive(_bits);
    FrameDelay();
    
}
uint32_t Converse(uint32_t doubleword)
{
    uint32_t lsb1, lsb2,msb1,msb2,temp;
    uint32_t cmsb2,clsb2;
    temp=doubleword;
    lsb1=temp&0xff000000;
    lsb2=temp&0x00ff0000;
    msb1=temp&0x0000ff00;
    msb2=temp&0x000000ff;
    
    lsb1=lsb1>>24;
    lsb2=lsb2>>8;
    
    msb1=msb1>>8;
    msb2=msb2<<8;
    msb2=msb2/2;
    
    cmsb2=msb2|msb1;
    clsb2=lsb2|lsb1;
    clsb2=clsb2&0x7fff;
    cmsb2=cmsb2<<16;
    return cmsb2|clsb2;
    
}   
uint32_t PowerConverse(uint32_t doubleword)
{
    uint32_t lsb1, lsb2,msb1,msb2,temp;
    uint32_t cmsb2,clsb2;
    temp=doubleword;
    lsb1=temp&0xff000000;
    lsb2=temp&0x00ff0000;
    msb1=temp&0x0000ff00;
    msb2=temp&0x000000ff;
    
    lsb1=lsb1>>24;
    lsb2=lsb2>>8;
    
    msb1=msb1>>8;
    msb2=msb2<<8;
   // msb2=msb2/2;
    
    cmsb2=msb2|msb1;
    clsb2=lsb2|lsb1;
   // clsb2=clsb2&0x7fff;
    cmsb2=cmsb2<<16;
    return (cmsb2|clsb2)/4;
}
void TestRWparameters(void)
{
     
while(1){
    for(j=0;j<50;j++){
         CSxActive(_bits);
         SPI2BUF=0x48ffffff;               //last 0x4058100
         receiveBuffer1=SPI2BUF;
         FrameDelay1();                       //very important delay
         while(SPI2STATbits.SPITBF){}
         CSxInActive(_bits);
         ActiveSYN();           //22.06.2017 very important latch Read registers     
  //-------------------Segment Read Control Register---------------------------//
         receiveBuffer1=SPI2BUF;
         SPI2STATCLR=1<<6;
         CSxActive(_bits);
         SPI2BUF=0xffffffff;      
        // receiveBuffer1=SPI2BUF;
         FrameDelay1();
         while(!SPI2STATbits.SPIRBF){}
            CSxInActive(_bits);
            receiveBuffer1=SPI2BUF;  
            receiveBuffer1=receiveBuffer1<<1;    //14.06.2007 for V,I rms and Power
            buf1[j]=Converse(receiveBuffer1);
          //buf1[j]=PowerConverse(receiveBuffer1);
         // buf1[j]=receiveBuffer1;
         // FrameDelay();         //01.07.2017 17;00
        }  
     
            i=1;
  
    }
}
void ReadC1Data(uint32_t *dataBuf, int port, relay_t relayNum, unsigned _bits)
{
    int i;
    uint32_t tempValue;
  
         CSxActive(_bits);
         SPI2BUF=0x5cffffff;               //last 0x4058100
         receiveBuffer1=SPI2BUF;
         FrameDelay1();                       //very important delay
         while(SPI2STATbits.SPITBF){}
         CSxInActive(_bits);
         ActiveSYN();           //22.06.2017 very important latch Read registers     
  //-------------------Segment Read Control Register---------------------------//
         receiveBuffer1=SPI2BUF;
         SPI2STATCLR=1<<6;
         CSxActive(_bits);
         SPI2BUF=0xffffffff;      
        // receiveBuffer1=SPI2BUF;
         FrameDelay1();
         while(!SPI2STATbits.SPIRBF){}
            CSxInActive(_bits);
            receiveBuffer1=SPI2BUF;  
            receiveBuffer1=receiveBuffer1<<1;    //14.06.2007 for V,I rms and Power
            buf1[j]=Converse(receiveBuffer1);
          //buf1[j]=PowerConverse(receiveBuffer1);
         // buf1[j]=receiveBuffer1;
         // FrameDelay();         //01.07.2017 17;00
  
    if (receiveBuffer1 >= limitCurrentValue1) {
        Find_ZCR();
        Switch_ON_Relay(port, relayNum); //two options for relay switching
        Switch_ON_PWMRelay(port, relayNum);
    }
    // how to Switch OFF relays

}
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

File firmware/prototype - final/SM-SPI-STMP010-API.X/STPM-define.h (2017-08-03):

/* 
 * File:   STPM-define.h
 * Author: Tony Tachev
 *
 * Upgraded on 25.July. 2016 14:53
 */


#ifdef	__cplusplus
extern "C" {
#endif
#include <stdint.h>
#include <stdlib.h>
// TODO Insert declarations
//void  Init_STPM34();        //function prototype
//void  Init_SPI_module();
//void SendFrame(char readAdd,char wrireAdd, char dataLSB,char dataMSB);
//----SPI Buffer for sending frames to configurate STPM registers-------//
// Structure of the frame:  
//          ReadAdd(1byte);				//
/*			WriteAdd(1Byte);				*/
/*			LSData[7:0];					*/
/*			MSData[15:8]					*/			
/*----------------------------------------------------------------------*/
 //char sendBuff[4]={0x0f,0x0f,0x0f,0x0f};
 
 /*------Structure definition for DSP CR1 LSB register STMP32----------*/
/*  Row:     0                                                        */
/*  Address:0x00                                                   */
/*  Name:    DSP_CR1_LSW[15:0]                                        */
/*  Read(R) Write(W) Latch(L): RW                                     */
/*  Default: 0x00A0                                                   */

typedef union{
    
    struct{    
        
   	 unsigned CLRSS_T01 :4;		
  	 unsigned ClearSS   :1;		
 
  	 unsigned ENVREF1   :1;		//  Enable internal voltage reference for primary channel:
                                // 0: reference disabled – external Vref required
                                // 1: reference enabled
 	 unsigned TC1       :3;		//Temperature compensation coefficient selection for primary 
                                //channel voltage reference VREF1
  	 unsigned           :7;
    };
    struct{
        unsigned LSB:8;
        unsigned MSB:8;
        unsigned LSW:16;
    };
    struct{
		unsigned short Address;
    };
  
}DSP_CR100bits_t;
//extern volatile DSP_CR100bits_t DSP_CR100bits  __asm__ ("DSP_CR100") __attribute__((section("sfrs")));
/*-----------------------------------------------------------------------*/

/*------Structure definition for DSP CR1 MSB register STMP32----------------*/
/*  Row:     1                                                              */
/*  Address: 0x01                                                         */
/*  Name:    DSP_CR1 MSW[31:16]                                             */
/*  Default: 0x0400                                                         */

typedef union{
    
    struct{
    
    
   	unsigned         :1;
	unsigned AEM1	:1;	// Apparent energy mode for primary channel:
                            // 0: use apparent RMS power
                            // 1: use apparent vectorial power
	unsigned APM1	:1;	// Apparent vectorial power mode for primary channel:
                            // 0: use fundamental power
                            // 1: use active power					    
   	unsigned BHPFV1 :1;	// Bypass hi-pass filter for primary voltage channel:
                            // 0: HPF enabled
                            // 1: HPF bypassed
   	unsigned BHPFC1 :1;	// Bypass hi-pass filter for primary current channel:
                            // 0: HPF enabled
                            // 1: HPF bypassed
   	unsigned ROC1 	:1;	// Add Rogowski integrator t

   	unsigned BLPFV1 :1;	// Primary voltage channel frequency content used for reactive  power calculation:
                                 // 0: fundamental
                                 // 1: wideband
   	unsigned BLPFC1 :1;	// Primary current channel frequency content used for reactive power calculation:
                        	// 0: fundamental
                        	// 1: wideband
   	unsigned LPW1   :4;	// LED1 speed dividing factor: 0x0 = 2^(-4), 0xF = 2^11
                                // Default 0x4 = 1
	unsigned LPC1		:2;	// LED1 pulse-out power selection:LPS1 [1:0]: 00,01,10,11
                            // LED1 output: active, fundamental, reactive, apparent
	unsigned LCSI		:2;	// LCS1 [1:0]: 00,01,10,11LED1: primary channels, secondary channels, cumulative, 
                            // sigma-delta bitstream
    };
    struct{
        unsigned LSB:8;
        unsigned MSB:8;
        unsigned MSW:16;
    };
   struct{
	unsigned short Address;
    };

} DSP_CR101bits_t;


/*------Structure definition for DSP CR2 LSB register STMP32----------*/
/*  Row:     01                                                        */
/*  Address: 0x02                                                     */
/*  Name:    DSP_CR2_LCW[15:0]                                        */
/*  Default: 0x00A0                                                   */
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

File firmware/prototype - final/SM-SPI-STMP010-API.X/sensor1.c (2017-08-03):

#include <stdio.h>
#include <stdlib.h>
#include <plib.h>
#include <p32xxxx.h>
#include <proc/p32mx795f512h.h>
#include "STPM-define.h"
#include "relay.h"
void Delay(void);
//void DiplayState(int code);
void Find_ZCR(void);
//void ReadFrame(unsigned short address, uint32_t * buffer);
void SendFrame(uint32_t readAdd, uint32_t writeAdd, uint32_t dataLSB, uint32_t dataMSB, int port, int _bits);
void FrameDelay(void);
void FrameDelayR(void);
void CheckOverCurrent(uint32_t *dataBuf, IoPortId port, unsigned int relayNum);
void CSxActive(int _bits);
void CSxInActive(int _bits);
void ReadReg(int port, int _bits, uint32_t *buf); // temp function for read reg contol
void ActiveSYN(void);
void FrameDelay1(void);
void FrameSend(void);
void SelectSPI(int cs);
void SetSPIx(int cs);
void DelayEn(void);
void Delay1mS();
void SelectSPIall(void);

void STPMInitReset();
void SpiInit1(void);
void ReadRegVI(int port, int _bits, uint32_t *buf);
void ReadRegPW(int port, int _bits, uint32_t *buf);

uint32_t ReadRegControl(int cmd, uint32_t flagZ, IoPortId port, unsigned int _bits); // temp function for read reg contol
/*--------------------------- SPI_Init() routine----------------------------------------*/
/* PORT/pin Definitions:                                                         */
/* En   - PIC32-pin45    RD11                                                    */
/* CS_1 - PIC32-pin8     RG9                                                     */
/* CS_2 - PIC32-pin11    RB5                                                     */
/* CS_3 - PIC32-pin12    RB4                                                     */
/* CS_4 - PIC32-pin14    RB2                                                     */
/* CS_5 - PIC32-pin13    RB3                                                     */
/**/
/* SPI Bus Pins Definition                                                       */
/* SKL2 - PIC32-pin4 - RG6                                                       */
/* SDI2 - PIC32-pin5 - RG7                                                       */
/* SDO2 - PIC32-pin6 - RG8                                                       */
//*SYN  - PIC32-pin44-RD10                                                       */
/*-------------------------------------------------------------------------------*/
#define  EnSPI PORTDbits.RD11                   // Enable (EN) for SPI selection)
#define SYN PORTDbits.RD10                      // SYN
#define CS_1   LATGbits.LATG9                    //  CS_1
#define CS_2   LATBbits.LATB5                    //  CS_2
#define CS_3   LATBbits.LATB4                    //  CS_3
#define CS_4   LATBbits.LATB2                    //  CS_4
#define CS_5   LATBbits.LATB3                    //  CS_5

void SPI_Init() {
    // Set Inputs/Outputs for SPI communication

    TRISDbits.TRISD11 = 0; //set EN as an Output
    TRISGbits.TRISG9 = 0; // set CS_1 an output
    TRISBbits.TRISB5 = 0; // set CS_2 an output
    TRISBbits.TRISB4 = 0; // set CS_3 an output
    TRISBbits.TRISB2 = 0; // set CS_4 an output
    TRISBbits.TRISB3 = 0; // set CS_5 an output
    TRISDbits.TRISD10 = 0; // set SYN as an output
   
    LATDbits.LATD11 = 0; //activate EN signal     21.04.2017
   // LATDbits.LATD11 = 1; //activate EN signal     21.04.2017
    LATDbits.LATD10 = 1; //deactivate SYN

    LATGbits.LATG9 = 1;  //1
    LATBbits.LATB5 = 1;  //1
    LATBbits.LATB4 = 1;  //1
    LATBbits.LATB2 = 1;  //1
    LATBbits.LATB3 = 1;  //1
   
    
    TRISGbits.TRISG7 = 1; //set as an input
    TRISGbits.TRISG8 = 0; //set as an output
    TRISGbits.TRISG6 = 0; //set as an output
    
    SpiChnOpen(2, SPICON_MSTEN | SPICON_SMP | SPICON_MODE32 | SPICON_ON, 2); // last was 8 = 20Mhz old value ,2 value 8
    SPI2CONbits.ON=0;
    SPI2CONbits.ENHBUF=0;
    SPI2CONbits.MODE32=1;
    SPI2CONbits.SMP=1;                  //sampled  at the end of the data
    SPI2CONbits.CKP=1;                  //ckp=1;select transfer mode 3
    SPI2CONbits.CKE=0;                  //cke=0
   
    SPI2CONbits.DISSDO=0;
    IEC0CLR=0x03800000;
    IFS0CLR=0x03800000;//Clears any existing event (rx / tx/ fault interrupt)
    SPI2CONbits.ON=1;
   

}

void STPMInitReset() {

    SYN = 0;
    Delay1mS();
    SYN = 1;
    Delay1mS();
    SYN = 0;
    Delay1mS();
    SYN = 1;
    Delay1mS();
    SYN = 0;
    Delay1mS();
    SYN = 1;
    Delay1mS();
    CS_1 = 0;
  //  CS_2 = 0;
  //  CS_3 = 0;
  //  CS_4 = 0;
  //  CS_5 = 0;
    Delay1mS();
      CS_1 = 1;
   // CS_2 = 1;
  //  CS_3 = 1;
  //  CS_4 = 1;
   // CS_5 = 1;
    /*-------------------------------------------------------------------------*/
   
   
}

/*--------------------------------------------------------------------------*/
void ActiveSYN(void) {
    PORTDbits.RD10 = 0; //active SYN
    FrameDelayR(); //4us 
    PORTDbits.RD10 = 1;
}
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

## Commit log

2016-02-12 Firmware to test prototype
    Initial version
2016-02-18 Schematic Files
    Initial draft of the schematic
    [PcbLib1.PcbLib, PcbLib2.PcbLib, PcbLib3.PcbLib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]
2016-02-19 Initial BOM
    This is still work in progress
    [OpenStrom - BOM.xlsx]
2016-02-23 Minor updates
    [SMLib.SchLib, Sheet1.SchDoc, Sheet2.SchDoc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]
2016-04-01 Updated Schematic
    Exploring options to have the sensors/relays on an external module
2016-04-07 Updated schematics
    Changed crystal oscillators with ceramic for the sizes and cost. For
    some resistors&capacitors I had to changed the packagse to 0603for the
    limit space.
2016-04-18 Updated Schematic
    Various changes, still lots to do :-)
2016-04-18 Updated Altium Files
    [PcbLib1.PcbLib, PcbLib2.PcbLib, PcbLib3.PcbLib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]
2016-04-25 Updated schematic
2016-05-02 Various changes
    [BOM-PCB_RelayBoard.xls, BOM-SmartMeter-rev4.xls]
2016-05-02 Revert "Various changes"
    This reverts commit ab9a9ce18bbdebc633697199979db1f4bed12320.
    [BOM-PCB_RelayBoard.xls, BOM-SmartMeter-rev4.xls]
2016-05-12 Updated Relay Board
    Splitting relay and sensor board on 2 levels to fit inside physical
    diemensions
2016-05-29 Updated files
    Updates to the designs.
    Please note that the control board design is only a prelimenary
    placement of the various parts and needs more work!
    [OpenStrom - BOM.xlsx]
2016-06-05 Various updates, including latest Altium files
    [CurrentTransPCB.PrjPcb, CurrentTransPCB.SchDoc, OpenStrom - BOM.xlsx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]
2016-06-09 Updated files.
    Please note that these are not the final files. We are working on
    several improvements, especially reducing the amount of components in
    the BOM
    [CPU-board-Sheet1-multi.SchDoc, CPU-board-Sheet2-multi.SchDoc, CPU-board-Sheet3-multi.SchDoc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]
2016-06-11 Routed main board
    [CPU-board-Sheet1-multi.SchDoc, CPU-board-Sheet2-multi.SchDoc, CPU-board-Sheet3-multi.SchDoc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]
2016-06-12 Updates
    changed the routing for RJ-45
    Still missing: do rule check procedure including correction of shortcuts
    clearance matches ,vias, track width and etc.
2016-06-15 Updated Schematics
    Double checking everythign now before getting PCB done
    [CPU-board-Sheet2-multi.SchDoc, CPU-board-multi.PrjPCB]
2016-06-17 ZigBee
    Using MRF24J40MA with integrated antenna for ZigBee
    [CPU-board-Sheet1-multi.SchDoc, CPU-board-Sheet2-multi.SchDoc, CPU-board-Sheet3-multi.SchDoc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]
2016-06-17 Removed old files
    [CurrentTransPCB.PrjPcb, CurrentTransPCB.SchDoc, PcbLib1.PcbLib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]
2016-06-23 Updated v0.1
    Several small fixes and adjustments.
    [BOM-CPU-board-multi-rev.0.1.xls, CPU-board-Sheet1-multi-rev.0.1.SchDoc, CPU-board-Sheet1-multi.SchDoc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]
2016-06-23 removed some old files
    [BOM-CPU-board-multi-rev.0.1.xls, BOM-PCB_RelayBoard.xls, BOM-SmartMeter-rev4.xls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]
2016-06-24 Some housekeeping
    [BOM-CPU-board-multi-rev.0.1.xls, BOM-CurrentTrans-board-multi.xls, BOM-RelayBoard-multi.xls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]
2016-06-24 Added Schematic v 0.1 files as PDF
2016-06-26 Updated to v0.2
    completed the correction for stpm34 oscillation
    added some test points
    some cleanup
    [BOM-CPU-board-multi-rev.0.1.xls, BOM-CPU-board-multi.xls, CPU-board-Sheet1-multi.SchDoc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]
2016-06-29 v0.3
    Added some test points
    [CPU-board-Sheet1-multi.SchDoc, CPU-board-Sheet2-multi.SchDoc]
2016-07-06 v4
    Several updates based on community feedback to improve manufacturing and
    certification requirements
    [BOM-CPU-board-multi.xls, CPU-board-Sheet1-multi.SchDoc, CPU-board-Sheet2-multi.SchDoc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]
2016-07-11 v0.5
    Integrated various feedback to improve manufacturing aspects
    [BOM-CPU-board-multi.xls, CPU-board-Sheet1-multi.SchDoc, CPU-board-Sheet2-multi.SchDoc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]
2016-07-18 Updates for first prototype
    [BOM-CPU-board-multi.xls, BOM-CurrentTrans-board-multi.xls, BOM-RelayBoard-multi.xls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]
2016-08-02 Firmware to test prototype
    [Part1.SLDDRW, Part1.STL, Part2.SLDDRW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]
2016-09-02 Updates and Changes during prototyping
    [BOM-CPU-board-multi.xls, CPU-board-Sheet1-multi.SchDoc, CPU-board-Sheet2-multi.SchDoc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]
2016-10-27 Learning from prototpye
    We have fixed various issues encountered in our prototype boards
    [BOM-CPU-board-multi.xls, CPU-board-Sheet1-multi.SchDoc, CPU-board-Sheet2-multi.SchDoc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]
2017-02-13 Second Prototype
    Update of schematics and firmware test files to reflect second prototype
    [3D-CurrentTrans-board-multi.PcbDoc, 3D-RelayBoard-multi.PcbDoc, BOM-CPU-board-rev2.xls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]
2017-02-22 Updated test for relay
2017-02-24 test code the code reads most of the electrical parameters
    - mains voltages RMS and moment values;
    - mains currents RMS and moment values;
    - electrical power - fundamental, active, passive, reactive, apparent;
    - electrical energy - fundamental, active, passive, reactive, apparent;
    - zero crossing events;
2017-05-22 Prototype v2a
    Updated Transformer boards and housing
    [BOM_CurrentTrans-board-rev3.xls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]
2017-05-23 Updated Housing v0.4
    [SmartM Additional Fixture.step, SmartM Additional Fixture.stl, SmartM Housing Bottom Plate.step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]
2017-06-06 Added a lasercut housing
    [1.dxf, 10.dxf, 2.dxf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]
2017-08-03 Updated Prototype - final fixes
    [BOM-CPU-board-rev3.xls, BOM-CurrentTrans-board-rev3.xls, BOM_RelayBoard-rev2.xls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]
